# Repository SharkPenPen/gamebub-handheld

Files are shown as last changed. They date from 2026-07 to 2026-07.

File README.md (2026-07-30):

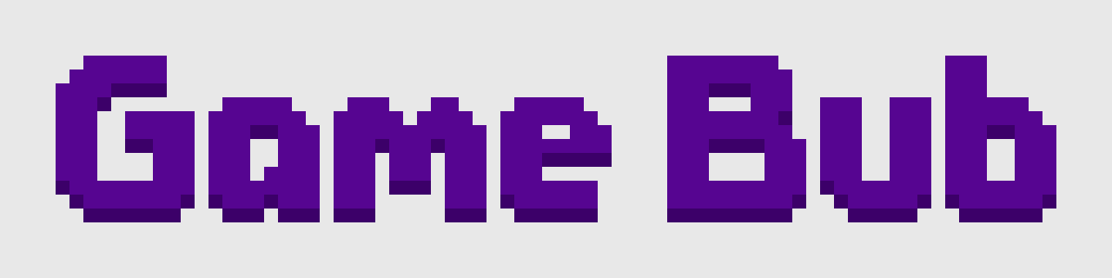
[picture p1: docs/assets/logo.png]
Game Bub logo

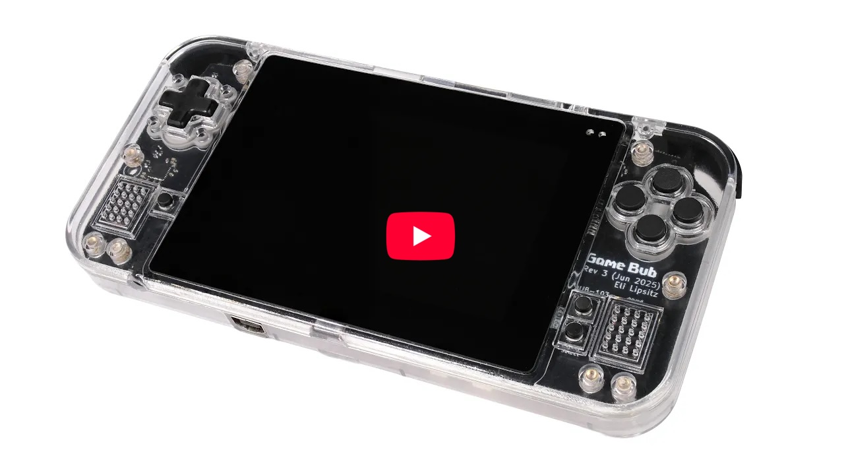
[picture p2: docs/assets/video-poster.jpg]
Game Bub trailer (https://www.youtube.com/watch?v=f16E5J6qljw)


**Game Bub** is an open-source FPGA retro emulation handheld, with support for Game Boy, Game Boy Color, and Game Boy Advance games.

Check out the [announcement blog post](https://eli.lipsitz.net/posts/introducing-gamebub/) for an in-depth look at the development process!

You can buy your own, prebuilt Game Bub from **[Crowd Supply](https://www.crowdsupply.com/second-bedroom/game-bub)**!

Want to chat about Game Bub? Feel free to [join the Discord](https://discord.gg/T5xrYpMfN7). 

## Features
* Play physical Game Boy / Color / Advance cartridges
* Load and play ROM files from a microSD card (with built-in support for rumble, clock, accelerometer, gyroscope)
* Multiplayer link cable functionality
* Custom, from-scratch Game Boy and Game Boy Advance FPGA cores with great game compatibility
* 14+ hour battery life 
* Video output to TV or monitor via custom dock
* Extensible hardware, designed for future improvements

## Building

Building a Game Bub handheld requires manufacturing PCBs, 3D printing the shell and buttons, and assembling components from a variety of sources. For information on manufacturing and assembling your own, see [docs/building.md](docs/building.md).

For other inquiries, contact me directly at eli@lipsitz.net.

## Architecture

For an in-depth description of the project architecture, see [docs/architecture.md](docs/architecture.md).

The Game Bub handheld consists of a Xilinx XC7A100T FPGA to do the main emulation and I/O, and an ESP32-S3 microcontroller to do auxiliary tasks (configuring the FPGA, rendering the UI, loading ROM files from a microSD card and sending it to the FPGA).

### Directory Structure

* `pcb`: PCB design files for Handheld, Dock, and others
* `3d`: STLs for 3D printed shell and buttons
* `fpga`: FPGA source code (HDL), written in [Chisel](https://github.com/chipsalliance/chisel)
* `firmware/handheld`: Microcontroller firmware

## License

Unless otherwise specified:
* FPGA source code (in `fpga/`) and firmware (in `firmware/`) is licensed under GPLv3 (`GPL-3.0-only`).
* 3D STL files (in `3d/`) is licensed under Creative Commons Attribution / Share-Alike 4.0 (`CC-BY-SA-4.0`)
* PCB schematic and layout files (in `pcb/`) are licensed under Creative Commons Attribution / Share-Alike 4.0 (`CC-BY-SA-4.0`)

At a high level, this means that you can copy, share, and modify the source code, as long as you provide proper attribution and share your source code / design files with the same license. However, this does not mean that you can use the "Game Bub" name and logo for your product without permission.

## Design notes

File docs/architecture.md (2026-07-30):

# Architecture

The physical architecture of the Game Bub handheld is summarized in the following block diagram.

See the [schematic](../pcb/handheld_rev2/handheld.pdf) for more information.

<p align="center">
     
</p>

## Power 

The device is split into three power domains:

* **Always on**: real-time clock, battery charger, battery gauge, and the power switch circuit.
    * `VBATT` (directly from the battery, 3.7V to 4.2V)
    * `VSYS_ALWAYS` (from the BQ24073 charger)
* **MCU**: Powers the MCU, its peripherals, and the display. Pressing the power switch powers on this power domain.
    * `VSYS` (~3.7V to 5.0V), from `VSYS_ALWAYS` through a load switch
    * `+3V3` (3.3V), generated by a TLV62585 buck converter from `VSYS`
* **FPGA**: Controlled by the `FPGA_ENABLE` signal from the MCU. Powers the FPGA and its peripherals. Also powers the DAC digital and analog core voltages (but the IO rails are powered as part of the MCU power domain).
    * `+1V0` (1.0V), generated by a TLV62585 buck converter from `VSYS`
    * `+5V0` (5.0V), generated by a TPS61022 boost converter from `VSYS`
    * `+1V8` (1.8V), generated by a TPS61022 boost converter from `VSYS`
    * `+3V3_FPGA` (3.3V), gated by a load switch from `+3V3`
    * `VGB` (3.3V or 5.0V), muxed from `+3V3_FPGA` or `+5V0` depending on whether there is a Game Boy (5V) or Game Boy Advance (3.3V) cartridge present. This muxing is controlled by the FPGA, and this is used to power the cartridge, link port, and the level shifters.

The FPGA requires careful power sequencing: `FPGA_ENABLE` enables `+1V0` and `+5V0`. `+1V8` is enabled once `+1V0` stabilizes, and `+3V3_FPGA` is enabled once that stabilizes.

## MCU and FPGA Responsibilities

The MCU is responsible for system control: it boots the device and manages the FPGA (power and configuration). It also renders the UI (sending completed frames over the FPGA for display).

The FPGA does all game emulation. It has direct access to the cartridge slot and link ports, and has dedicated memory (32 MiB of SDRAM, 512 KiB of SRAM) to assist with this. It produces audio and sends it to the DAC via I2S, and it has a high-bandwidth 18-bit parallel interface to the display. 

The FPGA also has 4 high-speed differential pairs routed out to the USB-C connector. This is used, with the custom dock in a vendor-specific alt mode, to output HDMI audio and video (directly from the FPGA). 

The high-speed QSPI link between the MCU and the FPGA (4 bit at 40 MHz, 20 MB/sec) is primarily used for control signals (telling the FPGA to play or pause), as well as rendering the UI. The FPGA drives the display, so the MCU has to send its UI through the FPGA.

Additionally, when using an emulated cartridge, the MCU sends the ROM file over to the FPGA to be stored in SDRAM, and periodically sends IMU updates (to emulate cartridges with accelerometers or gyroscopes).

Upon boot, the MCU loads the FPGA bitstream from the microSD card (4-bit SDIO), powers on the FPGA and configures it (using single SPI at 80 MHz). It initializes the display and other peripherals, and renders the initial UI.

## FPGA Structure

The top-level FPGA design is written in SystemVerilog and provides glue code to interface with the outside world, and instantiates the MMCM/PLLs, the HDMI module, and the main `HandheldTop` module, written in Chisel.

The `HandheldTop` module provides functionality common to both the Game Boy and GBA emulators. It instantiates the SPI receiver, MCU interrupt sender, SDRAM and SRAM controller, common configuration registers, the audio output (I2S), and the video output (DPI).

It instantiates the main emulator as a submodule ("inner module"), sending button input, receiving audio and video data (pixel by pixel, sample by sample, as it's generated), and arbitrating RAM access between the inner module and the MCU.

Video data from the inner module is placed into a triple-buffered framebuffer (backed by block RAM). The triple buffering is unfortunately essential because the display is rotated 90 degrees, so there would be diagonal tearing if entire frames were not buffered in memory. This also helps for HDMI output, which has to run at a constant 60 Hz frame rate, compared to the 59.73 Hz that the Game Boy and GBA run at. The UI from the MCU is received as 15-bit RGB (plus one alpha bit) and stored in a single buffer. The two are composited together as video is output.

### Clock Domains

* The "system" clock, which runs at the speed of the inner emulator (~8.39 MHz for Game Boy, ~16.78 MHz for GBA). Most of the logic runs in this clock domain
* The "av" (audio/video) clock, where the audio and video output is generated. This is 12.288 MHz when using the internal display, and 27.027 MHz when HDMI is enabled. HDMI uses a clock 5x faster as well for DDR TMDS encoding.
* The "sdram" clock, which runs at an integer multiple (e.g. 4x) of the "system" clock. This is used to communicate with the SDRAM module, and the integer multiple greatly simplifies clock domain crossing.
* The "spi" clock, which runs at 200 MHz. The SPI deserializer runs in this clock domain, allowing the 40 MHz SPI bus to be 5x oversampled. Read and write commands are deserialized and passed to the system clock domain via an asynchronous FIFO.

## MCU Structure

The MCU firmware is written with Rust, built on top of ESP-IDF with the [esp-idf-hal](https://github.com/esp-rs/esp-idf-hal) crate.

The UI is built with [Slint](https://github.com/slint-ui/slint). There's a single top-level Window, that holds the status bar and a swappable set of "Screen" components. Screens are each user-visible screen, such as the Main Menu, Rom Select, Settings, Tools, and Game screens.

Interrupts (from the FPGA, peripherals, or the button I/O expander) are handled in a dedicated interrupt thread, which sends events to a background "worker" thread. The UI runs on a dedicated "UI" thread, and the worker and UI threads communicate with each other through message passing.

When a game is being played, the Game screen is active. There are separate drivers for each type of bitstream (Game Boy or GBA), which handle loading the bootrom, loading and configuring the emulated cartridge, save files, and sending auxiliary data (e.g. IMU samples).

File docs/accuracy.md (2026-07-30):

# Accuracy

Neither the Game Boy [Color] or Game Boy Advance emulators have any major issues in any games I've tested.

## Game Boy / Game Boy Color

Test results WIP

## Game Boy Advance

Summary of test results (using [tests from here](https://emulation.gametechwiki.com/index.php/GBA_Tests)), as of commit [7d47149](/../../tree/7d47149a2f52bd7607accf401fc958f4a95d7e3a).

#### [mGBA test suite](https://github.com/mgba-emu/suite), commit 0293d27

| Test name  | Total | Passed |
| ---  | ----- | --- |
| Memory tests | 1552 | 1356 |
| I/O read tests | 130 | 43 |
| Timing tests | 2020 | 1510 |
| Timer count-up tests | 936 | 603 |
| Timer IRQ tests | 90 | 45 |
| Shifter tests | 140 | **140** |
| Carry tests | 93 | **93** |
| Multiply long tests | 72 | 52 |
| BIOS math tests | 615 | **615** |
| DMA tests | 1256 | 1060 |
| SIO register R/W tests | 90 | 32 |
| SIO timing tests | 8 | 0 |
| Misc. edge case tests | 10 | 8 |
| Video tests  | 7 | 5 |

#### AGS Aging Cartridge v10.0

| Test name  | Total | Passed |
| ---  | ----- | --- |
| Memory | 9 | **9** |
| LCD | 7 | **7** |
| Timer | 3 | **3** |
| DMA | 9 | **9** |
| COM | N/A | N/A |
| Key Input | 1 | **1** |
| Interrupt | 7 | **7** |

#### [jsmolka gba-tests](https://github.com/jsmolka/gba-tests), commit 49204e1

| Test name  | Result |
| ---  | --- |
| arm | **Pass** |
| bios | **Pass** |
| memory | **Pass** |
| nes | **Pass** |
| thumb | **Pass** |
| save: none | **Pass** |
| save: sram | **Pass** |
| save: flash64 | **Pass** |
| save: flash128 | **Pass** |

#### [alyosha gba-tests](https://github.com/alyosha-tas/gba-tests/), commit c8e15ff

| Test name  | Result |
| ---  | --- |
| DMA_ROM_Fixed | Fail test 46 |
| FIFO | Fail test 1 |
| FIFO_2 | Fail test 78 |
| Internal_Cycle_DMA_IRQ | Fail test 6 |
| Internal_Cycle_DMA_Mul | Fail test 37 |
| Halt_PC | Fail test 212 |
| Halt_PC_2 | Fail test 236 |
| Halt_PC_3 | Fail test 233 |
| Halt_PC_4 | Fail test 239 |
| IE | Fail test 1 |
| IF | Fail test 1 |
| IF_Timer | Fail test 1 |
| IRQ_Sub | **Pass** |
| LDM_ALU | Fail test 2 |
| LDM_ALU_Store | Fail test 6 |
| Sprite disable midline | not tested |
| Sprite disable on VRAM access | not tested |
| Sprite Last VRAM access | Fail test 159 |
| Sprite Last VRAM access free |  Fail test 121 |
| boundary_test_1 | Fail test 34 |
| branch_thumb | Fail test 42 |
| branch_thumb_2 | Fail test 26 |
| branch_thumb_3 | Fail test 34 |
| branch_thumb_4 | Fail test 29 |
| branch_thumb_arm | Fail test 55 |
| prefetcher_dma | Fail test 52 |
| prefetcher_full_arm | Fail test 1 |
| prefetcher_full_thumb | fail test 49 |
| PSR | Fail test 4 |
| Timer | Fail test 1 |
| Timer disable | Fail test 244 |
| Timer reset | Fail test 1 |

#### [NBA hw-test](https://github.com/nba-emu/hw-test), commit 4571fc5

| Test name  | Result |
| ---  | --- |
| Bus 128kb-boundary | Fail (stuck?) |
| DMA burst-into-tears | Fail 0/3 |
| DMA force-nseq-access | Fail 0/2 |
| DMA latch | Fail 0/3 |
| DMA start-delay | Fail 0/1 |
| IRQ irq-delay | **Pass** |
| PPU bgpd | Fail |
| PPU bgx | Fail |
| PPU dispcnt-latch | Fail |
| PPU greenswap | Fail |
| PPU sprite-hmosaic | Fail |
| PPU status-irq-dma | Fail (stuck?) |
| PPU vram-mirror | Fail 7/10 |
| Timer Reload | **Pass** |
| Timer Start-stop | **Pass** |
| Timer Halt-cnt | Fail 1/6 |

#### [Hades-Tests](https://github.com/hades-emu/Hades-Tests), commit 25ec4b4

| Test name  | Result |
| ---  | --- |
| bios-openbus | **Pass 12/12** |
| dma-latch | Fail 0/4 |
| dma-start-delay | Fail 0/8 |
| timer-basic | **Pass 10/10** |

#### [AGBEEG Aging v0.0.2](https://github.com/zaydlang/AGBEEG-Aging-Cartridge)

| Test name  | Result |
| ---  | --- |
| Cartridge | Fail 0/2 |
| CPU | Fail 2/3 |
| DMA | Fail 0/1 |

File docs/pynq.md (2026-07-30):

# Pynq-Z2 Documentation

The first version of this project was intended to be run on a Pynq-Z2 development board. Read the full writeup [here](https://eli.lipsitz.net/posts/fpga-gameboy-emulator/).

This document preserves the original instructions. **Please note, however, that the active branch of this repo no longer contains the Pynq/Zynq related code.** Check out the [`pynq-release` tag](https://github.com/elipsitz/gamebub/tree/pynq-release) for that code.

Currently, only the Pynq-Z2 is supported, although the core of the emulator should be able to be used on any FPGA with sufficient resources.

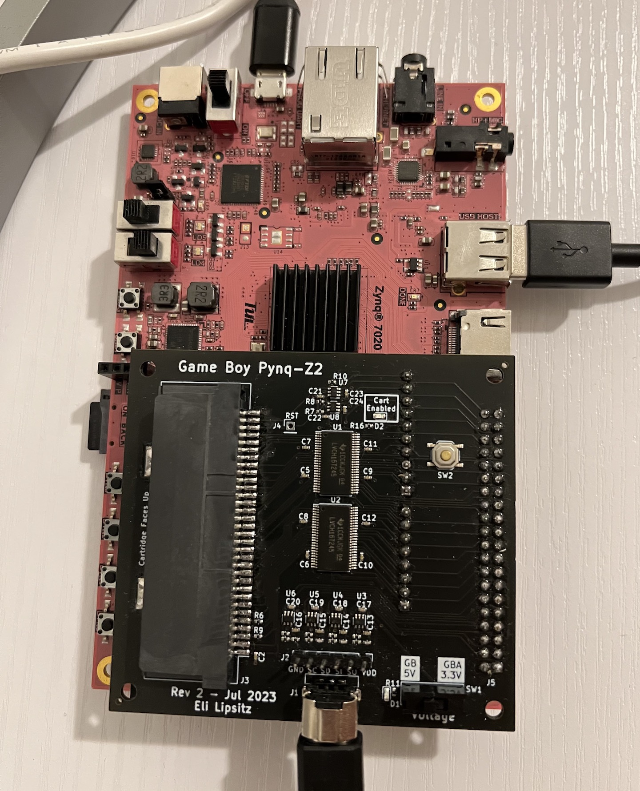
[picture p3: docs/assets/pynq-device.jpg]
 

## Building

A precompiled bitstream is available under Releases.

### Setup

#### Install Vivado

Currently this project uses Vivado 2020.2. The free edition is sufficient. Make sure to install with support for Zynq-7000 SoCs.

Install the [Pynq-Z2 Vivado board files](https://pynq.readthedocs.io/en/latest/overlay_design_methodology/board_settings.html).

Additionally, you should set up a shared IP cache to speed up synthesis of Xilinx IP:
1. Create the `~/vivado_ip_cache` directory (could be located somewhere else).
2. Create the file `~/.Xilinx/Vivado/Vivado_init.tcl`
3. In that file, add `set_param project.defaultIPCacheSetting /home/eli/vivado_ip_cache/` (substituting the absolute path to the IP cache directory).

#### Install other tools

You'll need to install JDK 8 or later, and [Scala Build Tool (`sbt`)](https://www.scala-sbt.org/download.html). Additionally, install [FuseSoC](https://github.com/olofk/fusesoc).

### Building the bitstream

From the top-level directory:

```
fusesoc --cores-root . run --build --target=pynq_z2 elipsitz:gameboy:gameboy
```

This will generate a `.bit` and `.hwh` file, which need to be accessible to the PS Python code.

## Running

### Setup

Install Pynq Linux on the Pynq-Z2, and install the pip packages listed in `python/requirements.txt`.

Transfer the `gameboy_ps` Python module (located in the `python` directory) to the Pynq-Z2.

Place the `gameboy.bit` and `gameboy.hwh` files from the build process in the `gameboy_ps/resources` directory.

### HDMI and Controller

Connect an HDMI cable from the "HDMI OUT" port on the Pynq-Z2 to a monitor or TV.

Attach an Xbox-compatible controller to the USB port of the Pynq-Z2.

### Running 

As root, run `python3 -m gameboy_ps <path to ROM directory>`, passing the path to the directory containing ROM files.

The program will load the bitstream to the PL. It takes a few seconds to load all of the Pynq libraries, but the main menu should soon show up on the display.

Warning: the audio output can be quite loud. Start at the lowest setting on the monitor/TV and increase it as needed.

## Building the cartridge adapter board

To play physical cartridges, you'll need to assemble the adapter board. KiCad board files can be found in the `pcb/pynq_adapter_rev2` directory. The schematic is pre-populated with LCSC part numbers for easy assembly at JLCPCB.

You'll need to add a few components yourself. These are all easy to solder:

* A 2x20 0.1mm female pin header (e.g. [this one](https://www.adafruit.com/product/2222)). These are used for Raspberry Pi HATs, so they're pretty easy to find.
* A SPDT slide switch such as the [EG1218](https://octopart.com/search?q=EG1218), or just a 1x3 strip of 0.1mm male pin header and a jumper.
* A GBA SP slot (such as [this one](https://handheldlegend.com/products/game-boy-cartridge-slot)). These can be found quite cheaply on eBay or Aliexpress as well. They're all pretty much the same.
* If desired, a GBA link port (e.g. [this one](https://handheldlegend.com/products/game-boy-advance-ext-link-port)). These can also be found easily from other sources.

The other parts are relatively small, so I don't recommend hand soldering the board. However, if you want to assemble the whole thing yourself, in addition to assorted resistors and capacitors, you'll also need:

* 6x [74LVC1T45DCK](https://octopart.com/search?q=74LVC1T45DCK) 1-bit level shifters.
* 2x [74LVCH16T245DGGR](https://octopart.com/search?q=74LVCH16T245DGGR) 16-bit level shifters. The non 'H' version should work as well, but the 'H' (bus hold) version is preferable.

## Appendix

### Getting Xbox controller to work on Pynq-Z2

This needs the `xpad` and `joydev` drivers. Pynq Linux isn't built with them. If you're running Pynq Linux with kernel `5.15.19-xilinx-v2022.1`, prebuilt kernel modules can be found in the [`pynq-release` release on GitHub](https://github.com/elipsitz/gamebub/releases/tag/pynq-release). Otherwise, to build loadable kernel modules from scratch:

On the Pynq-Z2, go to `/lib/modules/5.15.19-xilinx-v2022.1/build`.

Download the right version of [`xpad.c`](https://raw.githubusercontent.com/torvalds/linux/v5.15/drivers/input/joystick/xpad.c)
to `drivers/input/joystick/xpad.c`.

And do the same with [`joydev.c`](https://raw.githubusercontent.com/torvalds/linux/v5.15/drivers/input/joydev.c), to `drivers/input/joydev.c`.

The build commands in `/lib/modules` need to run with `sudo` due to permissions issues.

Do `sudo make menuconfig` and set:

* `Device Drivers --> Input device support --> Joystick interface` to `M` (for 'module')
* `Device Drivers --> Input device support --> Joysticks/gamepads --> X-box Gamepad support` to `M` (for 'module')

Save and exit.

Then build the modules:

```
sudo make scripts
sudo make distclean
sudo make prepare
sudo make modules_prepare

sudo make -C . M=drivers/input/ joydev.ko
sudo make -C . M=drivers/input/joystick xpad.ko
```

Install the modules so that they'll be loaded automatically on boot.
Copy the `.ko` files to `/usr/lib/modules/$(uname -r)/kernel/`, and append
to `/etc/modules`:

```
joydev
xpad
```

Alternatively, use `insmod <modules>.ko` to load them once.

Make sure the `xilinx` user is in the group `input`:
`sudo usermod -a -G input xilinx` (and re-login)

Install the Python library with `sudo pip3 install xbox360controller`

Create the device nodes if needed: https://docs.kernel.org/input/joydev/joystick.html#device-nodes

```
cd /dev
rm js*
mkdir input
mknod input/js0 c 13 0
mknod input/js1 c 13 1
mknod input/js2 c 13 2
mknod input/js3 c 13 3
ln -s input/js0 js0
ln -s input/js1 js1
ln -s input/js2 js2
ln -s input/js3 js3
```

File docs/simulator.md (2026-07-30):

# Simulator

Most development can be done in a Verilator simulation for easier debugging and to avoid having to build a new bitstream for every change.

Note that while the simulator is fast to compile, it's very slow to run. Only single thread CPU performance matters. On a MacBook Air M3, the GBA simulator runs at  ~5 fps (real time is 60fps), and the Game Boy Color simulator runs at ~40 fps.

The simulator has only been tested on macOS, but Linux should work perfectly fine as well.

## Setup

Ensure this repo is cloned with submodules checked out. If you already cloned the repo, run this:

```
git submodule update --init --recursive
```

SDL2 and [Verilator](https://www.veripool.org/verilator/) must be installed.
`fusesoc` and `sbt` (Scala Build Tool) must also be installed, see [building.md](./building.md).

## Building

To build the Game Boy simulator, run:

```
fusesoc --cores-root . run --target=sim --flag=module_gameboy elipsitz:gameboy:gameboy
```

The simulator will be built at `./build/elipsitz_gameboy_gameboy_1.0.0/sim-verilator/VSimGameboy`

Similarly, for the GBA, run:

```
fusesoc --cores-root . run --target=sim --flag=module_gba elipsitz:gameboy:gameboy
```

And find the simulator at `./build/elipsitz_gameboy_gameboy_1.0.0/sim-verilator/VSimGba`

Note that this command will end with an error ("ERROR: Failed to run ...") -- that's okay! FuseSoC doesn't know how to provide the correct command-line arguments to run the simulator.

## Running

For Game Boy Advance:

```
./build/elipsitz_gameboy_gameboy_1.0.0/sim-verilator/VSimGba --bios-path <path to bios.bin> <path to rom.gba>
```

Game Boy is the same, but with `VSimGameboy` (as mentioned above).

Optionally pass `--record path/to/output.mp4` to record all of the output of the simulator to play it back at full speed. Note that this produces an unusual lossless `mp4` file, and not all video players can play it. VLC works, though.

### Controls

Simulator controls:
* `escape`: quit the simulator
* `cmd+p`: pause or unpause
* `cmd+n`: pause and enter frame-by-frame mode. Keep pressing to advance one frame at a time.
* `cmd+r`: reset the simulator

Game controls:
* Arrow keys: D-pad up/down/left/right
* `z`: A button
* `x`: B button
* `a`: L shoulder button
* `s`: R shoulder button
* `right shift`: Select button
* `return`: Start button

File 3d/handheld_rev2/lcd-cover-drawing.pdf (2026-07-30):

R=3.20mm (x4)

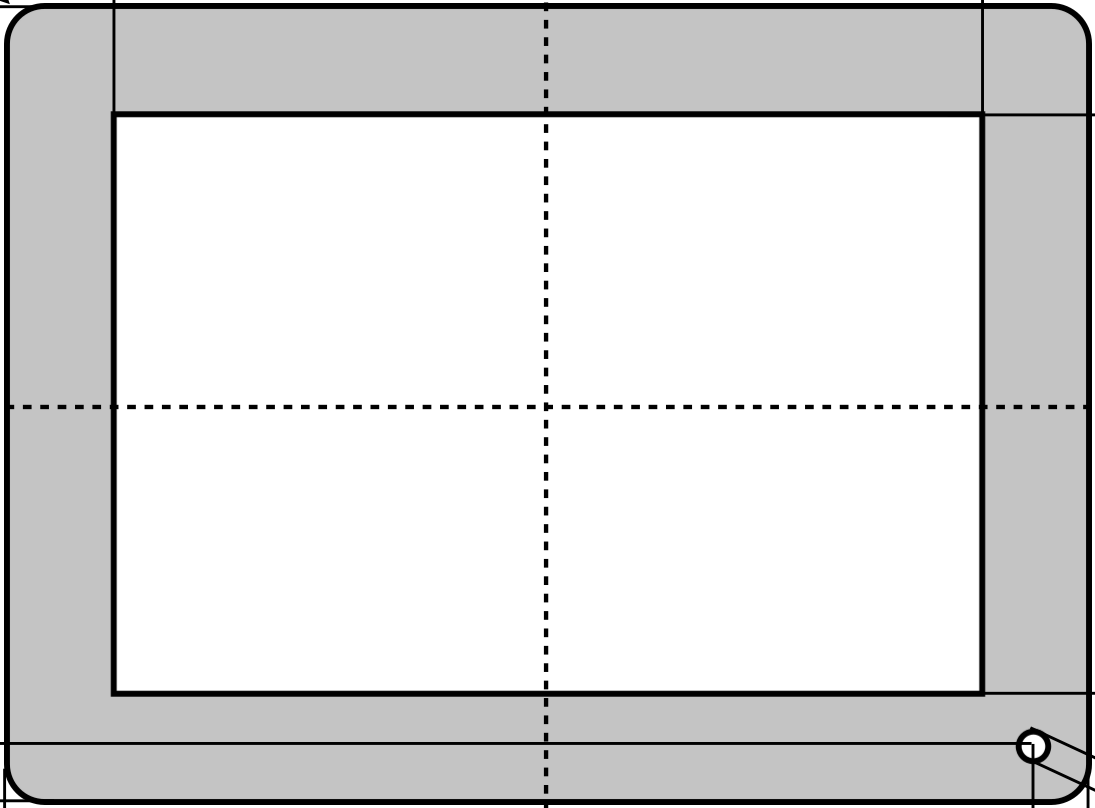
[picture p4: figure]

91.50mm

67.26mm
49.21mm

73.69mm

D=2.50mm

4.70mm

4.70mm

Shaded area: black silkscreen and adhesive backing

No adhesive in middle transparent rectangle

Material: 0.7mm tempered glass

Rounded corners (radius 3.20 mm, per drawing)

Note transparent circle in bottom right

# Front View

Transparent circle (no silkscreen)

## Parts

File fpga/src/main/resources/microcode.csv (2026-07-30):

Label | Comment | Encoding | PcNext | IME | RegRead1Sel | RegRead2Sel | RegWriteSel | RegOp | IncOp | IncReg | AluOp | AluSelA | AluSelB | AluFlagSet | MemEn | MemWr | MemAddrSel | MicroBranch | NextState
NOP |  | 00000000 | - | = | - | - | - | None | - | - | - | - | - | No | - | - | - | Fetch | -
_INVALID |  |  | Same | = | - | - | - | None | No | - | - | - | - | No | No | - | - | Jump | _INVALID
HALT |  | 01110110 | Same | = | - | - | - | None | No | - | - | - | - | No | No | - | - | Jump | HALT
STOP |  | 00010000 | IncOut | = | - | - | - | None | Inc | PC | - | - | - | No | No | - | - | Next | -
#STOP_loop |  |  | Same | = | - | - | - | None | No | - | - | - | - | No | No | - | - | Jump | #STOP_loop
LD r, (HL) |  | 01???110 | Same | = | - | - | Reg8Dest | WriteMem | No | HL | - | - | - | No | Yes | No | Incrementer | Jump | NOP
LD (HL), r |  | 01110??? | Same | = | - | Reg8Src | - | None | No | HL | CopyB | - | Reg2 | No | Yes | Yes | Incrementer | Jump | NOP
LD (HL),n |  | 00110110 | IncOut | = | - | - | W | WriteMem | Inc | PC | - | - | - | No | Yes | No | Incrementer | Next | -
 |  |  | Same | = | - | W | - | None | No | HL | CopyB | - | Reg2 | No | Yes | Yes | Incrementer | Jump | NOP
LD r,r |  | 01?????? | - | = | - | Reg8Src | Reg8Dest | WriteAlu | - | - | CopyB | - | Reg2 | No | - | - | - | Fetch | -
LD r,n |  | 00???110 | IncOut | = | - | - | Reg8Dest | WriteMem | Inc | PC | - | - | - | No | Yes | No | Incrementer | Jump | NOP
LD rr,nn |  | 00??0001 | IncOut | = | - | - | Reg16Lo | WriteMem | Inc | PC | - | - | - | No | Yes | No | Incrementer | Next | -
 |  |  | IncOut | = | - | - | Reg16Hi | WriteMem | Inc | PC | - | - | - | No | Yes | No | Incrementer | Jump | NOP
ldi (HL),A |  | 00100010 | Same | = | - | - | - | None | Inc | HL | CopyA | A | - | No | Yes | Yes | Incrementer | Jump | NOP
ldi A,(HL) |  | 00101010 | Same | = | - | - | A | WriteMem | Inc | HL | - | - | - | No | Yes | No | Incrementer | Jump | NOP
ldd (HL),A |  | 00110010 | Same | = | - | - | - | None | Dec | HL | CopyA | A | - | No | Yes | Yes | Incrementer | Jump | NOP
ldd A,(HL) |  | 00111010 | Same | = | - | - | A | WriteMem | Dec | HL | - | - | - | No | Yes | No | Incrementer | Jump | NOP
ALU A, n |  | 11???110 | IncOut | = | - | - | W | WriteMem | Inc | PC | - | - | - | No | Yes | No | Incrementer | Next | -
 |  |  | - | = | - | W | A | WriteAlu | - | - | InstAlu | A | Reg2 | All | - | - | - | Fetch | -
ALU A, (HL) |  | 10???110 | Same | = | - | - | W | WriteMem | No | HL | - | - | - | No | Yes | No | Incrementer | Next | -
 |  |  | - | = | - | W | A | WriteAlu | - | - | InstAlu | A | Reg2 | All | - | - | - | Fetch | -
ALU A, r |  | 10?????? | - | = | - | Reg8Src | A | WriteAlu | - | - | InstAlu | A | Reg2 | All | - | - | - | Fetch | -
JP nn | little endian address | 11000011 | IncOut | = | - | - | Z | WriteMem | Inc | PC | - | - | - | No | Yes | No | Incrementer | Next | -
 |  |  | IncOut | = | - | - | W | WriteMem | Inc | PC | - | - | - | No | Yes | No | Incrementer | Next | -
#PC=WZ |  |  | IncOut | = | - | - | - | None | No | WZ | - | - | - | No | No | - | - | Jump | NOP
JP HL |  | 11101001 | IncOut | = | - | - | - | None | IncNoWrite | HL | - | - | - | No | - | - | Incrementer | Fetch* | -
JP f,nn | Conditional | 110??010 | IncOut | = | - | - | Z | WriteMem | Inc | PC | - | - | - | No | Yes | No | Incrementer | Next | -
 |  |  | IncOut | = | - | - | W | WriteMem | Inc | PC | - | - | - | No | Yes | No | Incrementer | Cond | #PC=WZ
 |  |  | - | = | - | - | - | None | - | - | - | - | - | No | - | - | - | Fetch | -
LD (rr), A |  | 00??0010 | Same | = | - | - | - | None | No | Inst16 | CopyA | A | - | No | Yes | Yes | Incrementer | Jump | NOP
LD A, (rr) |  | 00??1010 | Same | = | - | - | A | WriteMem | No | Inst16 | - | - | - | No | Yes | No | Incrementer | Jump | NOP
LD (nn), A |  | 11101010 | IncOut | = | - | - | Z | WriteMem | Inc | PC | - | - | - | No | Yes | No | Incrementer | Next | -
 |  |  | IncOut | = | - | - | W | WriteMem | Inc | PC | - | - | - | No | Yes | No | Incrementer | Next | -
 |  |  | Same | = | - | - | - | None | No | WZ | CopyA | A | - | No | Yes | Yes | Incrementer | Jump | NOP
LD A, (nn) |  | 11111010 | IncOut | = | - | - | Z | WriteMem | Inc | PC | - | - | - | No | Yes | No | Incrementer | Next | -
 |  |  | IncOut | = | - | - | W | WriteMem | Inc | PC | - | - | - | No | Yes | No | Incrementer | Next | -
 |  |  | Same | = | - | - | A | WriteMem | No | WZ | - | - | - | No | Yes | No | Incrementer | Jump | NOP
LD (FF00 + n), A |  | 11100000 | IncOut | = | - | - | W | WriteMem | Inc | PC | - | - | - | No | Yes | No | Incrementer | Next | -
 |  |  | Same | = | - | W | - | None | No | - | CopyA | A | - | No | Yes | Yes | High | Jump | NOP
LD (FF00 + C), A |  | 11100010 | Same | = | - | C | - | None | No | - | CopyA | A | - | No | Yes | Yes | High | Jump | NOP
LD A, (FF00 + n) |  | 11110000 | IncOut | = | - | - | W | WriteMem | Inc | PC | - | - | - | No | Yes | No | Incrementer | Next | -
 |  |  | Same | = | - | W | A | WriteMem | No | - | - | - | - | No | Yes | No | High | Jump | NOP
LD A, (FF00 + C) |  | 11110010 | Same | = | - | C | A | WriteMem | No | - | - | - | - | No | Yes | No | High | Jump | NOP
INC rr |  | 00??0011 | Same | = | - | - | - | None | Inc | Inst16 | - | - | - | No | No | - | - | Jump | NOP
DEC rr |  | 00??1011 | Same | = | - | - | - | None | Dec | Inst16 | - | - | - | No | No | - | - | Jump | NOP
LD (nn), SP |  | 00001000 | IncOut | = | - | - | Z | WriteMem | Inc | PC | - | - | - | No | Yes | No | Incrementer | Next | -
 |  |  | IncOut | = | - | - | W | WriteMem | Inc | PC | - | - | - | No | Yes | No | Incrementer | Next | -
 |  |  | Same | = | - | SP_Lo | - | None | Inc | WZ | CopyB | - | Reg2 | No | Yes | Yes | Incrementer | Next | -
 |  |  | Same | = | - | SP_Hi | - | None | Inc | WZ | CopyB | - | Reg2 | No | Yes | Yes | Incrementer | Jump | NOP
LD SP, HL |  | 11111001 | Same | = | - | L | SP_Lo | WriteAlu | No | - | CopyB | - | Reg2 | No | No | - | - | Next | -
 |  |  | - | = | - | H | SP_Hi | WriteAlu | - | - | CopyB | - | Reg2 | No | - | - | - | Fetch | -
PUSH AF |  | 11110101 | Same | = | - | - | - | None | Dec | SP | - | - | - | No | No | No | - | Next | -
 |  |  | Same | = | - | A | - | None | Dec | SP | CopyB | - | Reg2 | No | Yes | Yes | Incrementer | Next | -
 |  |  | Same | = | - | F | - | None | No | SP | CopyB | - | Reg2 | No | Yes | Yes | Incrementer | Jump | NOP
POP AF |  | 11110001 | Same | = | - | - | F | WriteMem | Inc | SP | CopyB | - | Reg2 | No | Yes | No | Incrementer | Next | -
 |  |  | Same | = | - | - | A | WriteMem | Inc | SP | CopyB | - | Reg2 | No | Yes | No | Incrementer | Jump | NOP
PUSH rr |  | 11??0101 | Same | = | - | - | - | None | Dec | SP | - | - | - | No | No | No | - | Next | -
 |  |  | Same | = | - | Reg16Hi | - | None | Dec | SP | CopyB | - | Reg2 | No | Yes | Yes | Incrementer | Next | -
 |  |  | Same | = | - | Reg16Lo | - | None | No | SP | CopyB | - | Reg2 | No | Yes | Yes | Incrementer | Jump | NOP
POP rr |  | 11??0001 | Same | = | - | - | Reg16Lo | WriteMem | Inc | SP | - | - | - | No | Yes | No | Incrementer | Next | -
 |  |  | Same | = | - | - | Reg16Hi | WriteMem | Inc | SP | - | - | - | No | Yes | No | Incrementer | Jump | NOP
ADD HL,rr | 16-bit add | 00??1001 | Same | = | L | Reg16Lo | L | WriteAlu | No | - | AddLo | Reg1 | Reg2 | No | No | - | - | Next | -
 |  |  | - | = | H | Reg16Hi | H | WriteAlu | - | - | AddHi | Reg1 | Reg2 | -*** | - | - | - | Fetch | -
ADD SP,dd |  | 11101000 | IncOut | = | - | - | W | WriteMem | Inc | PC | - | - | - | No | Yes | No | Incrementer | Next | -
 |  |  | Same | = | SP_Lo | W | SP_Lo | WriteAlu | No | - | AddLo | Reg1 | Reg2 | 0*** | No | - | - | Next | -
 |  |  | Same | = | SP_Hi | W | SP_Hi | WriteAlu | No | - | AddHi | Reg1 | SignReg2 | No | No | - | - | Jump | NOP
ld HL,SP+dd |  | 11111000 | IncOut | = | - | - | W | WriteMem | Inc | PC | - | - | - | No | Yes | No | Incrementer | Next | -
 |  |  | Same | = | SP_Lo | W | L | WriteAlu | No | - | AddLo | Reg1 | Reg2 | 0*** | No | - | - | Next | -
 |  |  | - | = | SP_Hi | W | H | WriteAlu | - | - | AddHi | Reg1 | SignReg2 | No | - | - | - | Fetch | -
JR e |  | 00011000 | IncOut | = | - | - | W | WriteMem | Inc | PC | - | - | - | No | Yes | No | Incrementer | Next | -
#PC+=W |  |  | Same | = | PC_Lo | W | PC_Lo | WriteAlu | No | - | AddLo | Reg1 | Reg2 | No | No | - | - | Next | -
 | Mem MemAddr to be the new PC, and need to increment PC |  | IncOut | = | PC_Hi | W | PC_Hi | WriteAlu | IncNoWrite | PC_ALU | AddHi | Reg1 | SignReg2 | No | Yes | No | Incrementer | Fetch* | -
JR c,e | Conditional | 001??000 | IncOut | = | - | - | W | WriteMem | Inc | PC | - | - | - | No | Yes | No | Incrementer | Cond | #PC+=W
 |  |  | - | = | - | - | - | None | - | - | - | - | - | No | - | - | - | Fetch | -
CALL nn |  | 11001101 | IncOut | = | - | - | Z | WriteMem | Inc | PC | - | - | - | No | Yes | No | Incrementer | Next | -
 |  |  | IncOut | = | - | - | W | WriteMem | Inc | PC | - | - | - | No | Yes | No | Incrementer | Next | -
#CALL_end |  |  | Same | = | - | - | - | None | Dec | SP | - | - | - | No | No | No | - | Next | -
 |  |  | Same | = | - | PC_Hi | - | None | Dec | SP | CopyB | - | Reg2 | No | Yes | Yes | Incrementer | Next | -
 |  |  | Same | = | - | PC_Lo | - | None | No | SP | CopyB | - | Reg2 | No | Yes | Yes | Incrementer | Next | -
 |  |  | IncOut | = | - | - | - | None | IncNoWrite | WZ | - | - | - | No | - | - | Incrementer | Fetch* | -
CALL cc, nn | Conditional | 110??100 | IncOut | = | - | - | Z | WriteMem | Inc | PC | - | - | - | No | Yes | No | Incrementer | Next | -
 |  |  | IncOut | = | - | - | W | WriteMem | Inc | PC | - | - | - | No | Yes | No | Incrementer | Cond | #CALL_end
 |  |  | - | = | - | - | - | None | - | - | - | - | - | No | - | - | - | Fetch | -
RET |  | 11001001 | Same | = | - | - | PC_Lo | WriteMem | Inc | SP | - | - | - | No | Yes | No | Incrementer | Next | -
 |  |  | Same | = | - | - | PC_Hi | WriteMem | Inc | SP | - | - | - | No | Yes | No | Incrementer | Next | -
 | Extra NOP |  | Same | = | - | - | - | None | No | - | - | - | - | No | No | - | - | Jump | NOP
RET cc | Conditional | 110??000 | Same | = | - | - | - | None | No | - | - | - | - | No | No | - | - | Cond | RET
 |  |  | - | = | - | - | - | None | - | - | - | - | - | No | - | - | - | Fetch | -
RETI | RET + enable interrupts | 11011001 | Same | = | - | - | PC_Lo | WriteMem | Inc | SP | - | - | - | No | Yes | No | Incrementer | Next | -
 |  |  | Same | = | - | - | PC_Hi | WriteMem | Inc | SP | - | - | - | No | Yes | No | Incrementer | Next | -
 | Extra NOP |  | Same | En | - | - | - | None | No | - | - | - | - | No | No | - | - | Jump | NOP
INC (HL) |  | 00110100 | Same | = | - | - | W | WriteMem | No | HL | - | - | - | No | Yes | No | Incrementer | Next | -
 |  |  | Same | = | - | W | - | None | No | HL | IncB | - | Reg2 | All | Yes | Yes | Incrementer | Jump | NOP
INC r |  | 00???100 | - | = | - | Reg8Dest | Reg8Dest | WriteAlu | - | - | IncB | - | Reg2 | All | - | - | - | Fetch | -
DEC (HL) |  | 00110101 | Same | = | - | - | W | WriteMem | No | HL | - | - | - | No | Yes | No | Incrementer | Next | -
 |  |  | Same | = | - | W | - | None | No | HL | DecB | - | Reg2 | All | Yes | Yes | Incrementer | Jump | NOP
DEC r |  | 00???101 | - | = | - | Reg8Dest | Reg8Dest | WriteAlu | - | - | DecB | - | Reg2 | All | - | - | - | Fetch | -
ALU unary | accumulator/flag ops | 00???111 | - | = | - | - | A | WriteAlu | - | - | InstAcc | A | Reg2 | All | - | - | - | Fetch | -
CB_PREFIX | CB prefix | 11001011 | IncOut | = | - | - | - | None | Inc | PC | - | - | - | No | Yes | No | Incrementer | DispatchCB | -
CB_ALU (HL) | CB shift / rotates | CB_00???110 | Same | = | - | - | W | WriteMem | No | HL | - | - | - | No | Yes | No | Incrementer | Next | -
 |  |  | Same | = | - | W | - | None | No | HL | InstCB | - | Reg2 | All | Yes | Yes | Incrementer | Jump | NOP
CB_ALU r | CB shift / rotates | CB_00?????? | - | = | - | Reg8Src | Reg8Src | WriteAlu | - | - | InstCB | - | Reg2 | All | - | - | - | Fetch | -
BIT (HL) | No (HL) writeback | CB_01???110 | Same | = | - | - | W | WriteMem | No | HL | - | - | - | No | Yes | No | Incrementer | Next | -
 |  |  | - | = | - | W | - | None | - | - | InstBit | - | Reg2 | All | - | - | - | Fetch | -
CB_BIT (HL) |  | CB_?????110 | Same | = | - | - | W | WriteMem | No | HL | - | - | - | No | Yes | No | Incrementer | Next | -
 |  |  | Same | = | - | W | - | None | No | HL | InstBit | - | Reg2 | All | Yes | Yes | Incrementer | Jump | NOP
CB_BIT r |  | CB_???????? | - | = | - | Reg8Src | Reg8Src | WriteAlu | - | - | InstBit | - | Reg2 | All | - | - | - | Fetch | -
EI | Enable interrupts | 11111011 | - | En | - | - | - | None | - | - | - | - | - | No | - | - | - | Fetch | -
DI | Disable interrupts | 11110011 | - | Dis | - | - | - | None | - | - | - | - | - | No | - | - | - | Fetch | -
RST vec |  | 11???111 | Same | = | - | - | - | None | Dec | SP | - | - | - | No | No | No | - | Next | -
 |  |  | Same | = | - | PC_Hi | - | None | Dec | SP | CopyB | - | Reg2 | No | Yes | Yes | Incrementer | Next | -
 |  |  | RstAddr | = | - | PC_Lo | - | None | No | SP | CopyB | - | Reg2 | No | Yes | Yes | Incrementer | Jump | NOP
#Interrupt | decrement PC |  | IncOut | Dis | - | - | - | None | Dec | PC | - | - | - | No | No | No | - | Next | -
#Interrupt_keepPC | decrement SP |  | Same | Dis | - | - | - | None | Dec | SP | - | - | - | No | No | No | - | Next | -
 | push PC hi |  | Same | = | - | PC_Hi | - | None | Dec | SP | CopyB | - | Reg2 | No | Yes | Yes | Incrementer | Next | -
 | push PC, jump |  | Interrupt | = | - | PC_Lo | - | None | No | SP | CopyB | - | Reg2 | No | Yes | Yes | Incrementer | Jump | NOP

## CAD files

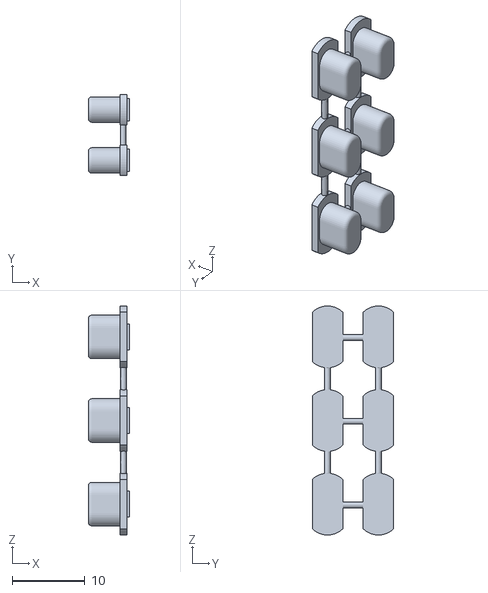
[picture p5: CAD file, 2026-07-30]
3d/handheld_rev2/SideButtonArray.stl
5.70 x 11.2 x 31.5

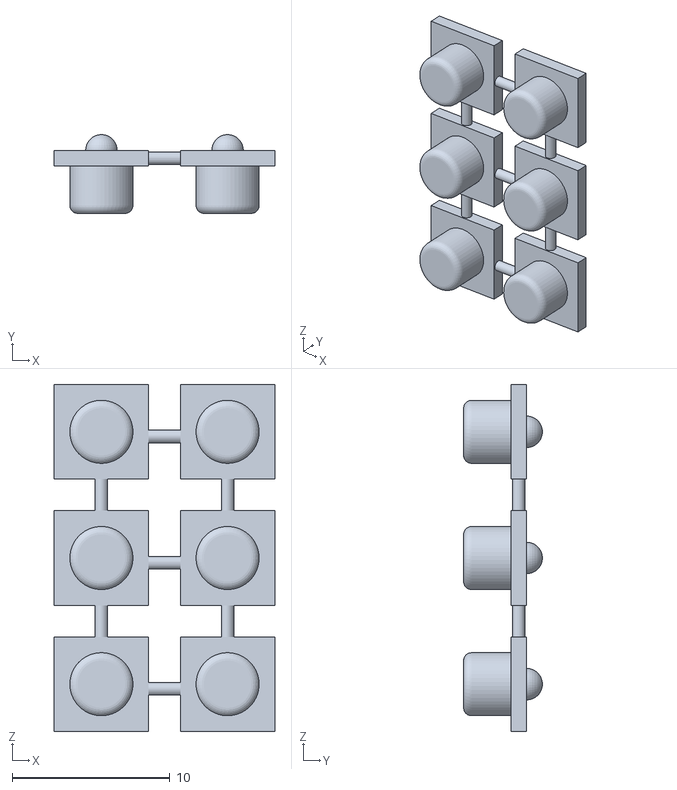
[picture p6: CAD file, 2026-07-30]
3d/handheld_rev2/ExtButtonArray.stl
14.0 x 5.00 x 22.0

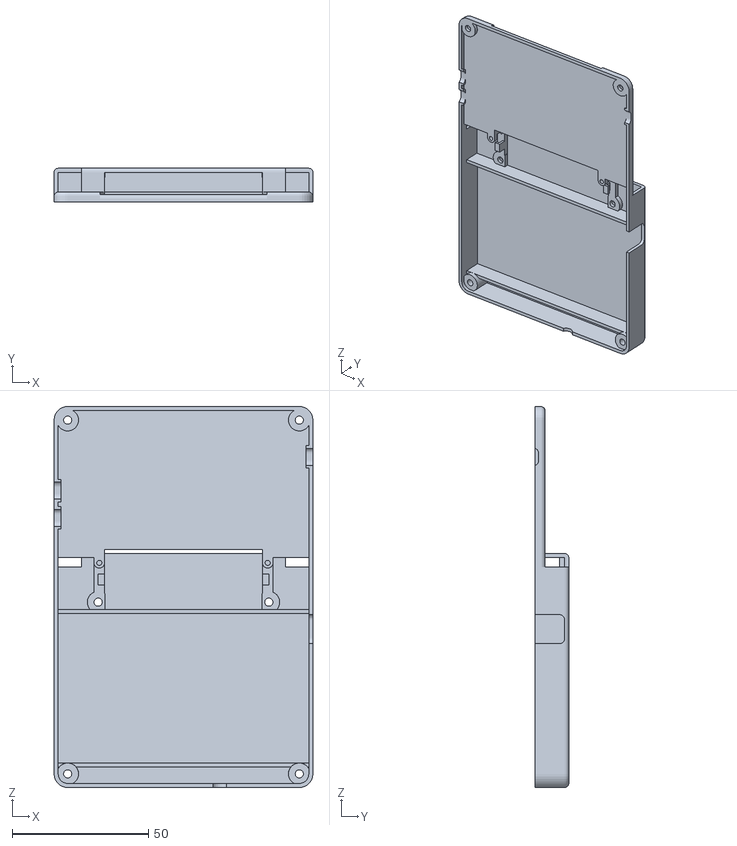
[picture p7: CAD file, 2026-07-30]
3d/handheld_rev2/Rear.stl
95.1 x 12.4 x 140.0

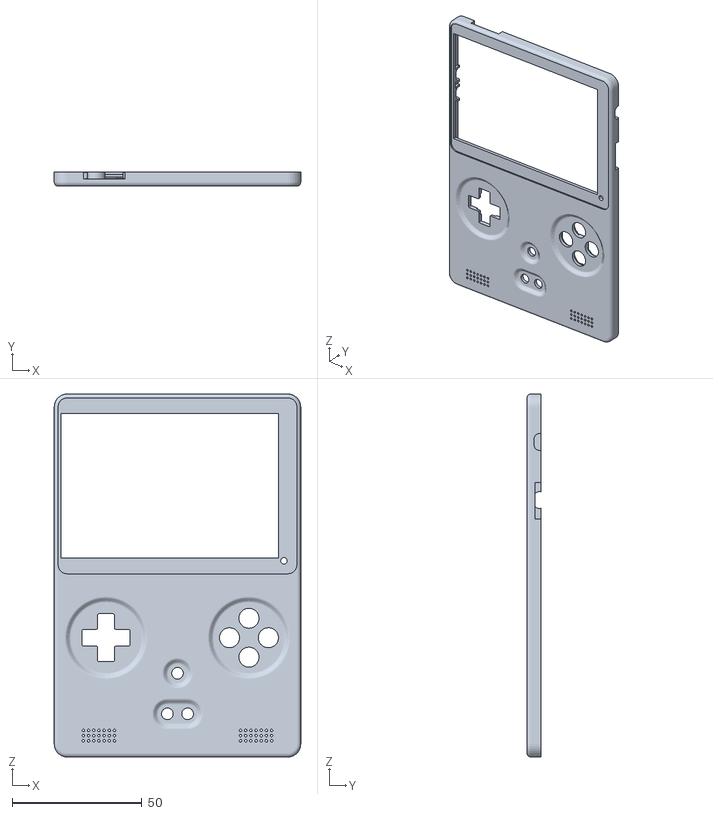
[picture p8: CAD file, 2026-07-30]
3d/handheld_rev2/Front.stl
95.1 x 5.50 x 140.0

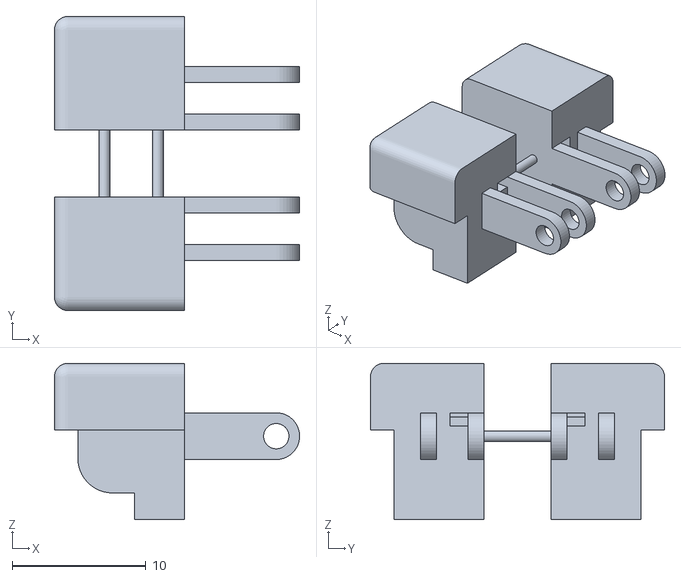
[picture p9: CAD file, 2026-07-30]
3d/handheld_rev2/ShoulderButtonArray.stl
18.3 x 22.0 x 11.7

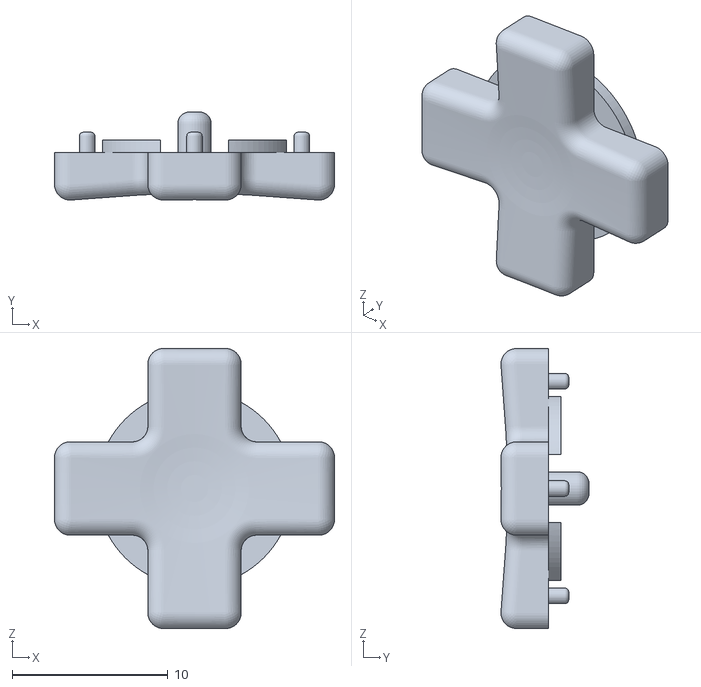
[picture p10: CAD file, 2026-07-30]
3d/handheld_rev2/DpadButton.stl
18.0 x 5.66 x 18.0

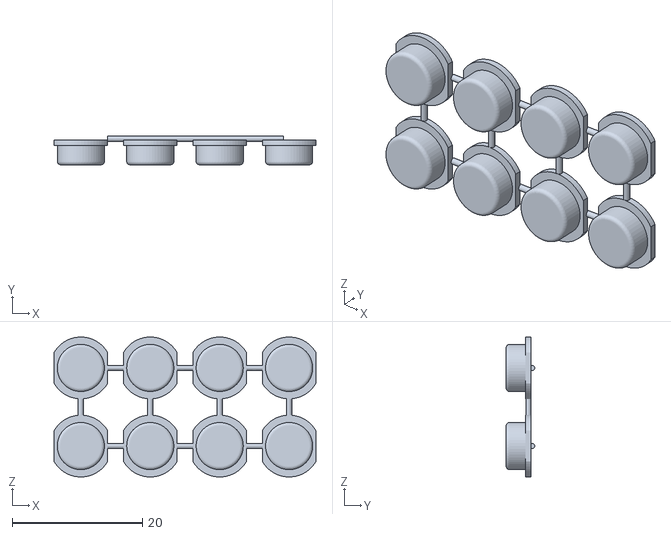
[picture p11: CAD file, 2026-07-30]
3d/handheld_rev2/FaceButtonArray.stl
40.3 x 4.40 x 21.5

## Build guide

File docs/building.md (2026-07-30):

# Building

Building a Game Bub unit is a fairly involved process:

1. Manufacturing the PCB
2. Assembling the PCB
3. Printing the shell (and buttons)
4. Assembling the whole device
5. Building the FPGA bitstreams
6. Setting up the microSD card
7. Flashing the MCU firmware

## 1. Manufacturing the PCB

Fab the PCB (in `/pcb/handheld_rev2`) using your manufacturer of choice. The board was initially designed to be fabricated and assembled by JLCPCB.

The board has 6 layers, and rectangular dimensions of 90.1 mm by 135 mm. Due to the fine pitch (0.8mm) BGA FPGA package, the smallest vias are 0.4/0.25mm, with a minimum track width of 0.1mm. The board must have an ENIG finish, as HASL is too uneven for fine-pitch BGA components. 

The board should have a thickness of 1.6mm -- this isn't essential, but the enclosure was designed for this thickness. Only the JLCPCB default 6-layer `JLC06161H-3313` stackup has been tested, but other stackups are likely to work too.

## 2. Assembling the PCB

The board is primarily one-sided, and the vast majority of the components can be machine assembled. The board design files have LCSC component IDs (for easy JLCPCB assembly).

The remaining components are specialty or otherwise difficult to machine assemble:

Front:
* 3.5mm headphone jack: Same Sky SJ-43614-SMT-TR
* Rumble motor: generic 10mm diameter rumble motor
* Optional PMOD connector: 6-pin female 0.1 inch right angle SMD header

Rear:
* Generic GBA cartridge slot
* Generic GBA link port
* Cartridge slot shape detector: JJOV0UL650NONPRBK
* Battery connector: S2B-PH-SM4-TB (or generic 2-pin SMD JST-PH receptacle)
* Shoulder (L and R) buttons: C&K PTS645VN13SMTR92LFS (x2)

Solder each of these components (see the PCB design files if needed).

## 3. Printing the shell

The shell consists of two pieces: the front and rear. Both have a wall thickness of 1.5mm, with some small features of 1.0mm or 0.8mm.

FDM (filament) printing is almost certainly not suitable: this should be printed with a high-precision technology such as SLA (photosensitive resin).

Additionally, all of the buttons are custom and need to be printed as well:
* 4x Large front buttons (A, B, X, and Y)
* D-pad
* 3x Small front buttons (Start, Select, Home)
* 3x Side buttons

## 4. Assembling the whole device

### Parts needed
* ER-TFT035IPS-6 LCD module
* LCD Cover glass (tempered glass or transparent acrylic)
* 2x Speakers (CMS-160903-18S-X8)
* 9x M2.5x4mm heat-set inserts
* CA glue to glue the inserts
* A set of Nintendo DSi button membranes (ABXY and D-pad)
* M2.5 screws:
    * 5x 5mm (three PCB screws, 2 top screws)
    * 4x 14mm (middle and bottom screws)
* A set of torsion springs (1x left, 1x right):
    * Required: >1.5mm interior diameter
    * Suggested: 0.3mm wire diameter, 5 turns, 135 degree angle
* 2x 1.5mm diameter dowel pins, 8mm to 9mm long.
* 755068 size flat Lipo battery with a JST-PH connector (verify polarity)

### Steps
Before assembling, consider testing that the PCB works properly.

1. Attach the LCD cover glass to the front shell with adhesive glue or tape
2. Place the front shell face down on a surface
3. Carefully align and press the LCD module onto the cover glass (ensure flex is facing the correct direction)
4. Glue all 9 heat-set inserts into place, and let the glue harden
5. Insert the speakers into the shell
6. Place the face buttons into the shell, followed by the D-pad and ABXY membranes
7. Open the LCD flex connector on the PCB
8. Carefully set the PCB face down onto the shell, putting the LCD module flex into place on the PCB connector, and close it.
9. Ensure the PCB is aligned well onto the front shell
8. Use the 5mm screws to attach the PCB to the front shell (triangle of screw holes in the middle, towards the bottom half of the PCB). Tighten carefully.
9. Insert the three side buttons into the front shell.
10. Attach the battery to the rear shell with adhesive
11. Assemble the shoulder buttons: align each shoulder button with the rear shell. Place the correct spring in line (inserting one end of the spring into the button), and then insert a dowel pin to hold the assembly together. Hook the other end of the spring into the hook in the rear shell.
12. Plug the battery into the battery connector on the PCB
13. Place the rear shell onto the front shell
14. Use 6 screws (5mm on top, 14mm on the middle and bottom) to close up the shell

## 5. Building the FPGA bitstreams

1. Install Xilinx Vivado 2023.2 with support for Artix-7 devices
2. Install JDK 8 or later, and [Scala Build Tool (`sbt`)](https://www.scala-sbt.org/download.html)
3. Install [FuseSoC](https://github.com/olofk/fusesoc).

From the `/fpga` directory, use FuseSoC to build the bitstreams:

```sh
$ fusesoc --cores-root . --work-root=build/boot --target=handheld_rev2 --flag=boot elipsitz:gameboy:gameboy
$ fusesoc --cores-root . --work-root=build/gameboy --target=handheld_rev2 --flag=gameboy elipsitz:gameboy:gameboy
$ fusesoc --cores-root . --work-root=build/gba --target=handheld_rev2 --flag=gba elipsitz:gameboy:gameboy
```

Save the generated `*.bit` files.

## 6. Setting up the microSD card

Format a good quality microSD card with FAT32, then create the following directory structure:

```
system/
  boot.bit.gz
  gameboy.bit.gz
  gameboy.bios-dmg.bin
  gameboy.bios-cgb.bin
  gba.bit.gz
  gba.bios.bin
roms/
```

* `boot.bit.gz` should be a gzip'd copy of the `boot` bitstream built previously.
* `gameboy.bit.gz` should be a gzip'd copy of the `gameboy` bitstream.
* `gba.bit.gz` should be a gzip'd copy of the `gba` bitstream.
* `gameboy.bios-dmg.bin` and `gameboy.bios-cgb.bin` should be the bootrom files for the original Game Boy and Game Boy Color, or open-source alternatives (e.g. from [SameBoy](https://github.com/LIJI32/SameBoy)).
* `gba.bios.bin` should be the Game Boy Advance bootrom. Either the official one, extracted from a GBA (best compatibility), or a free alternative ([e.g. this one](https://github.com/Cult-of-GBA/BIOS)).
* `roms/` should be a directory containing ROM files (if desired), with `.gb`, `.gbc`, and `.gba` extensions. This directory can be further organized into more directories.

## 7. Flashing the MCU firmware

### Setup

1. Install Rust for ESP32 by [following these instructions (Xtensa targets)](https://docs.esp-rs.org/book/installation/index.html)
2. Install [espflash](https://github.com/esp-rs/espflash)

### Building and installing

Connect the device to your computer with a USB-C cable. Hold the "Home" button (in the center) while turning the device on (by pressing the power button in the top right).

From `/firmware/handheld`, run the following command to build and flash the firmware:

```sh
$ cargo run --release --features=rev2
```

Then, flash the device-specific "factory" data:

```sh
$ python3 flash_nvs.py --serial serialno --revision 2
```

The device should automatically reboot into the main menu.

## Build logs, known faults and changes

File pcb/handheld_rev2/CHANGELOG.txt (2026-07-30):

Done
* Switch USB-C connector to one with 24p
* Remove HDMI port and related circuitry
* Power DAC IOVDD with +3V3 instead of 3V3_FPGA
* Change pull-up resistors on link port lines to ~47k to 100k. Move the 100K pull-up to the other side of the 330R current limiter
* Add 3V3_FPGA test point
* Add n-FET gated by 3V3_FPGA between IRQ line and FPGA IRQ to pull it down
* Switch to ESP32-S3-MINI
* Separate SPI bus for display (3 wire -- so add clock and data line)
* Connect TE signal from LCD (could replace SRAM nCS)
* Output HDMI signals over USB-C SS signals
* Connect a (or both?) USB-C SBU to the FPGA (with a series resistor)
* Add a rumble "brake" circuit? with another signal to the FPGA
* Update SRAM LCSC ID to comparable part
* Investigate noise in headphones and speakers -- try the low-noise LDO for analog 3V3
* Reserve space for screw holes (new positioning)
* Allow for larger, 5mm (!) rounded radius
* Footprint for 24p USB-C
* Switch battery connector to SMD (or maybe dual footprint)
* [not possible] If possible, move cartridge shape detector to the left side (when looking at rear)
* Change 0603 resistors to 0402 where possible? Including 0 ohm shunts
* Switch headphone jack (PJ-342?)
* Use DSi XL button spacing and silicone pads (and keep-out area)
* Use Kicad 8 pin 1 designators on footprints
* Move link port to the bottom, on the rear
* Move side buttons a bit further from L/R buttons
* Move the home button away? Closer to the top, middle?
* Remove unneeded hole from cartridge switch footprint
* Support speaker with spring contact -- leave space for it
* Move side buttons further in (with PCB cutout around)
* Make shoulder buttons SMD 
* Ensure all ports hang off the right amount
* If needed, change some of the test points (e.g. I2S) to smaller surface-only
* Investigate SMD vibration motor? Reserve space to solder it in place on board and glue it down?
* Minimize BOM: Look at resistors and capacitors that are used just once -- see if they can be changed to something else
* Add silkscreen rectangle to write identifying info
* New Gamebub logo
* Print test point silkscreen (for through hole) on rear

TODO Schematic
* Try to connect FPGA clock to different IO bank -- bank 14 or bank 15

TODO Layout
* Add silkscreen indicators around screw holes

Not doing:
* Make FPGA JTAG easier to access (e.g. when there's a case on? closer to battery?)
* Consider swapping I/O expander to QFN 4x4mm package if needed
* Move spi test points further from LCD plug (removed them)
* Use Kicad 8 net-from-value for power rails
* Add some resettable fuses (PTC): one each where 3.3V and 5V connects to VGB (and can remove the extra transistors). 
* Add resettable fuse at rumble motor
* Not needed: Tie SRAM nCE low, disconnect from FPGA (if needed)

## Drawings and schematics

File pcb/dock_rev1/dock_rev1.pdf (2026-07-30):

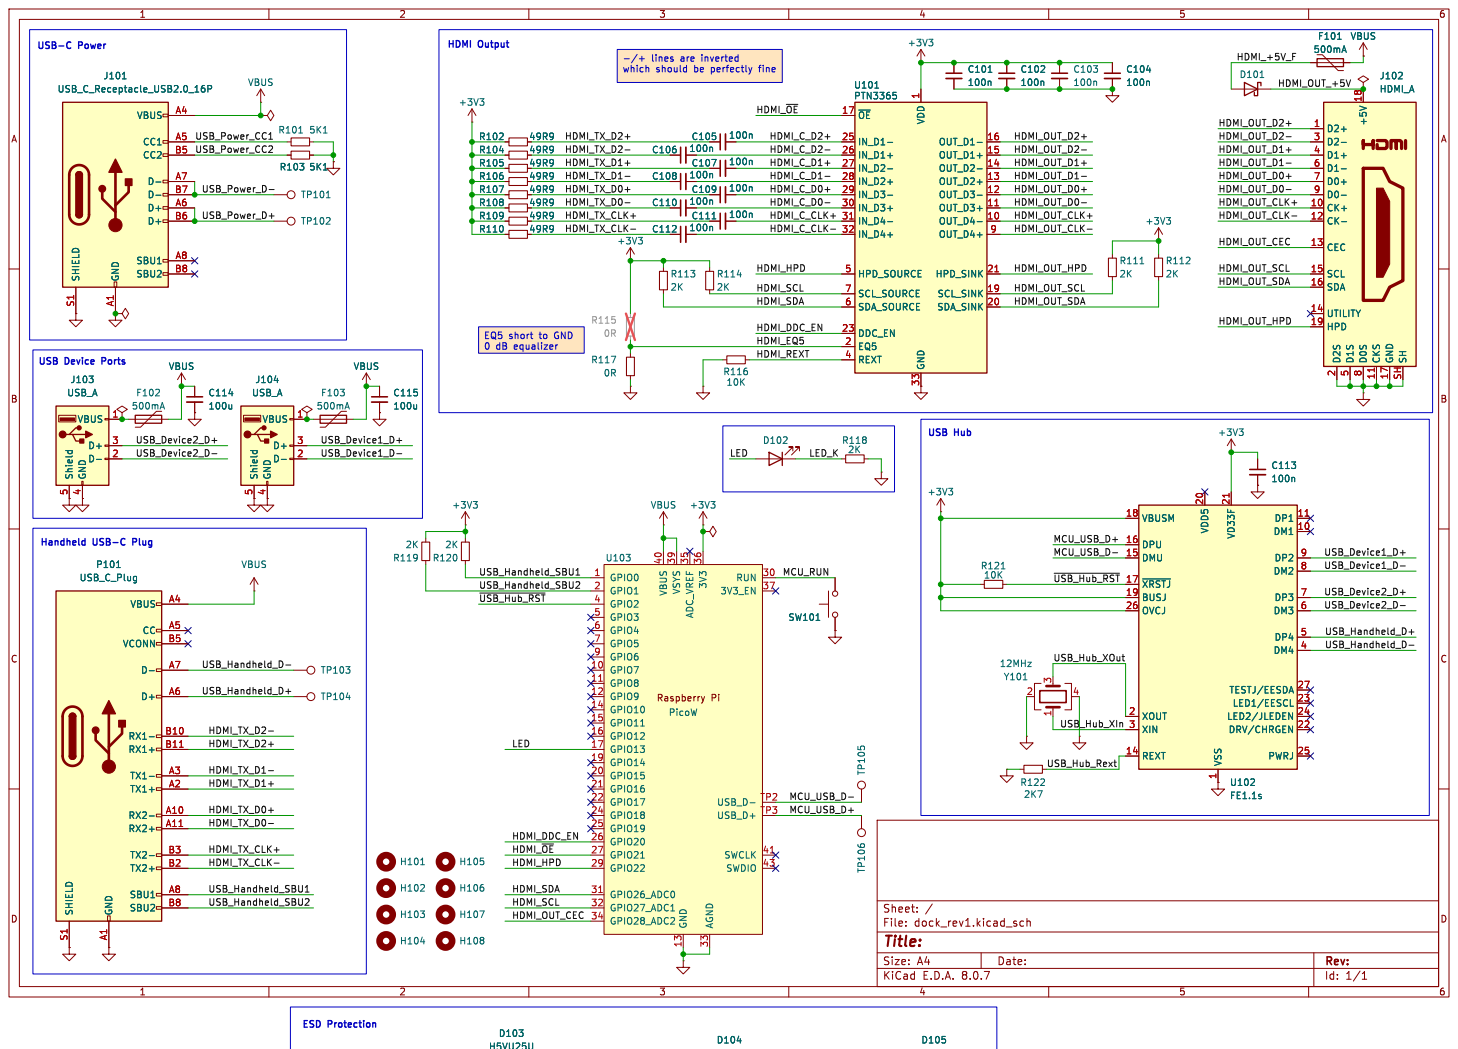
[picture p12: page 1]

HDMI Output USB Device Ports

1 DM1 10 DP1 11 REXT 14 DMU 15 DPU 16 ~{XRSTJ} 17 VBUSM 18 BUSJ 19 XOUT 2 VDD5 20 VD33F 21 DRV/CHRGEN 22

Id: 1/1 Title: File: dock_rev1.kicad_sch Sheet: /

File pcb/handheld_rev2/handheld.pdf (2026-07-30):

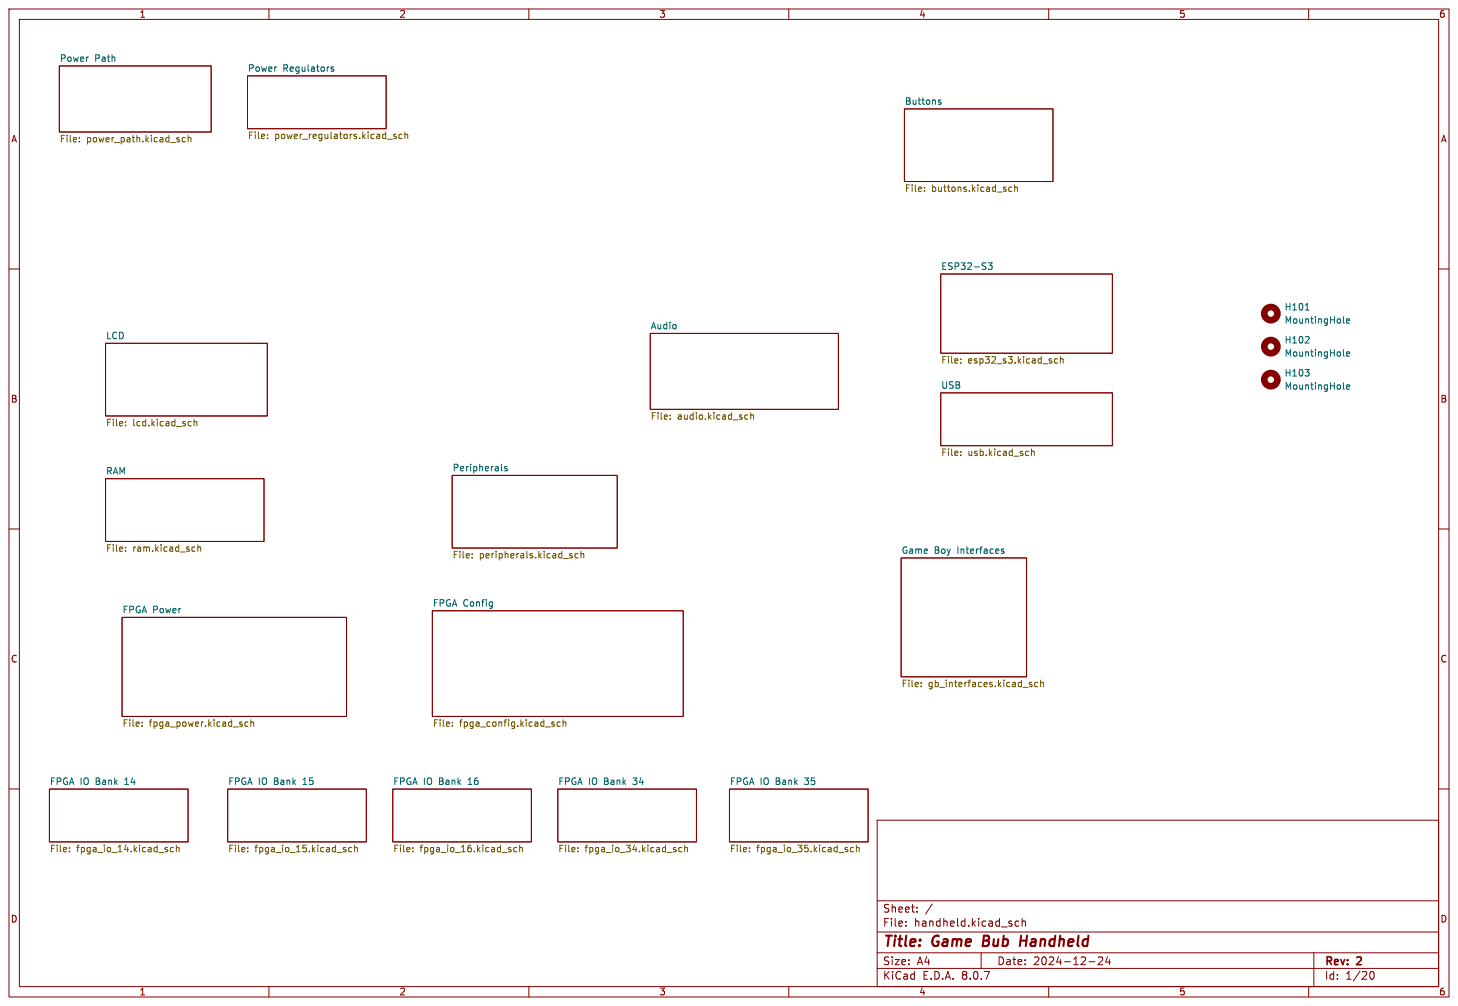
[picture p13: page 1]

File: lcd.kicad_sch Power Path File: power_path.kicad_sch RAM

File: usb.kicad_sch Power Regulators File: power_regulators.kicad_sch

File: handheld.kicad_sch Sheet: /
Id: 1/20 Title: Game Bub Handheld

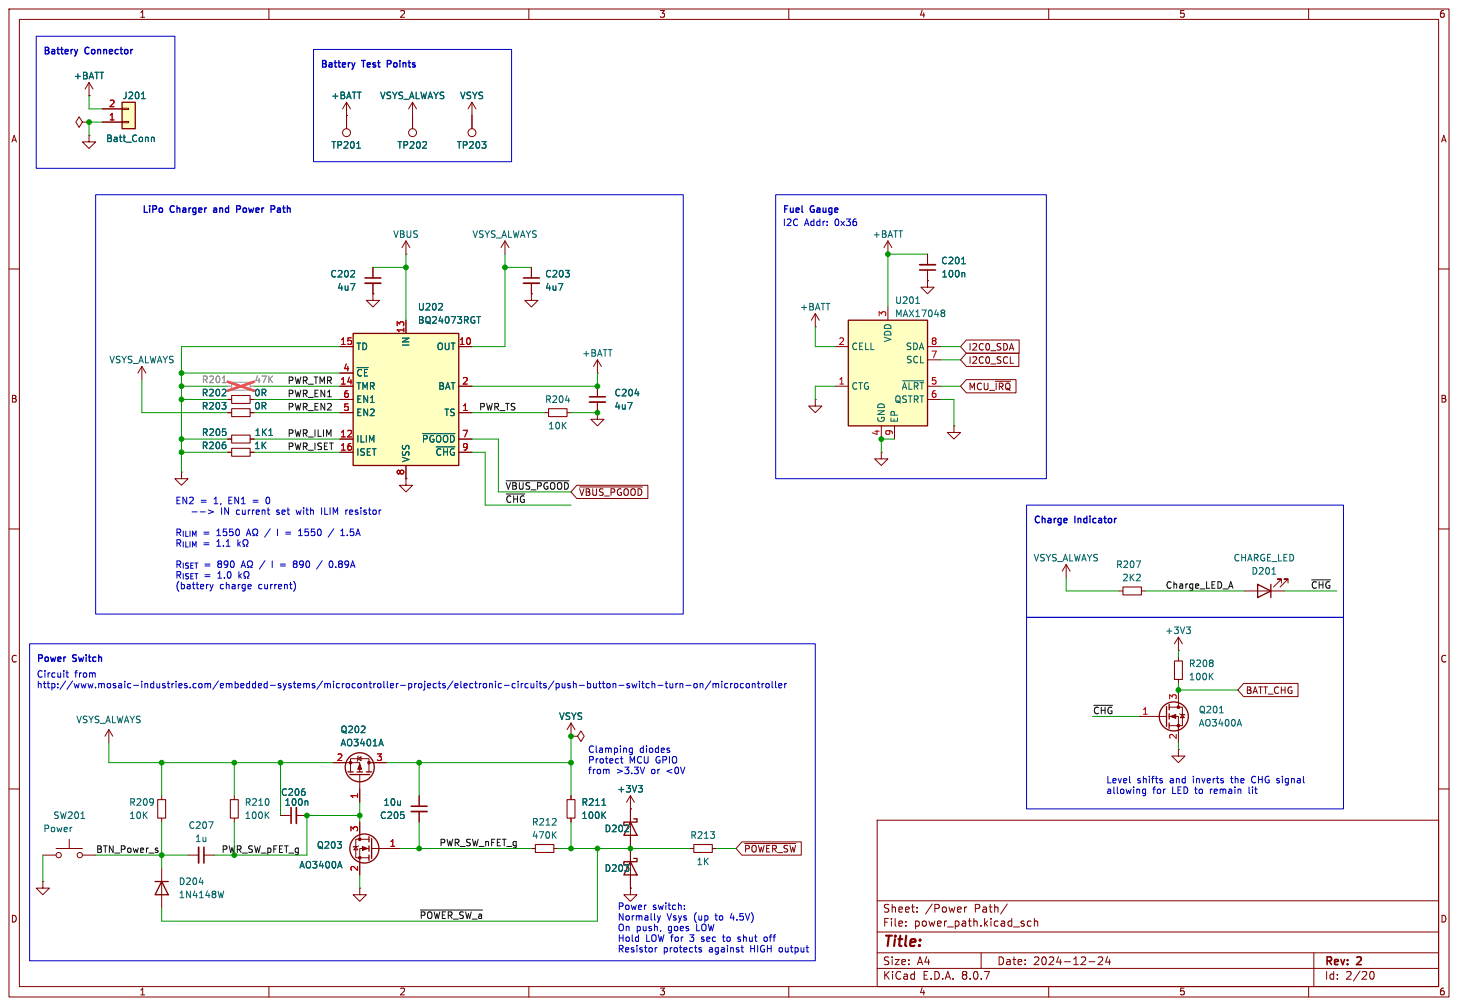
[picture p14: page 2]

4 QSTRT 6 SCL 7 SDA 8 EP

R_{ISET} = 890 þÿA©/ I = 890 / 0.89A R_{ISET} = 1.0 þÿk©

http://www.mosaic-industries.com/embedded-systems/microcontroller-projects/electronic-circuits/push-button-switch-turn-on/microcontroller

Level shifts and inverts the CHG signal

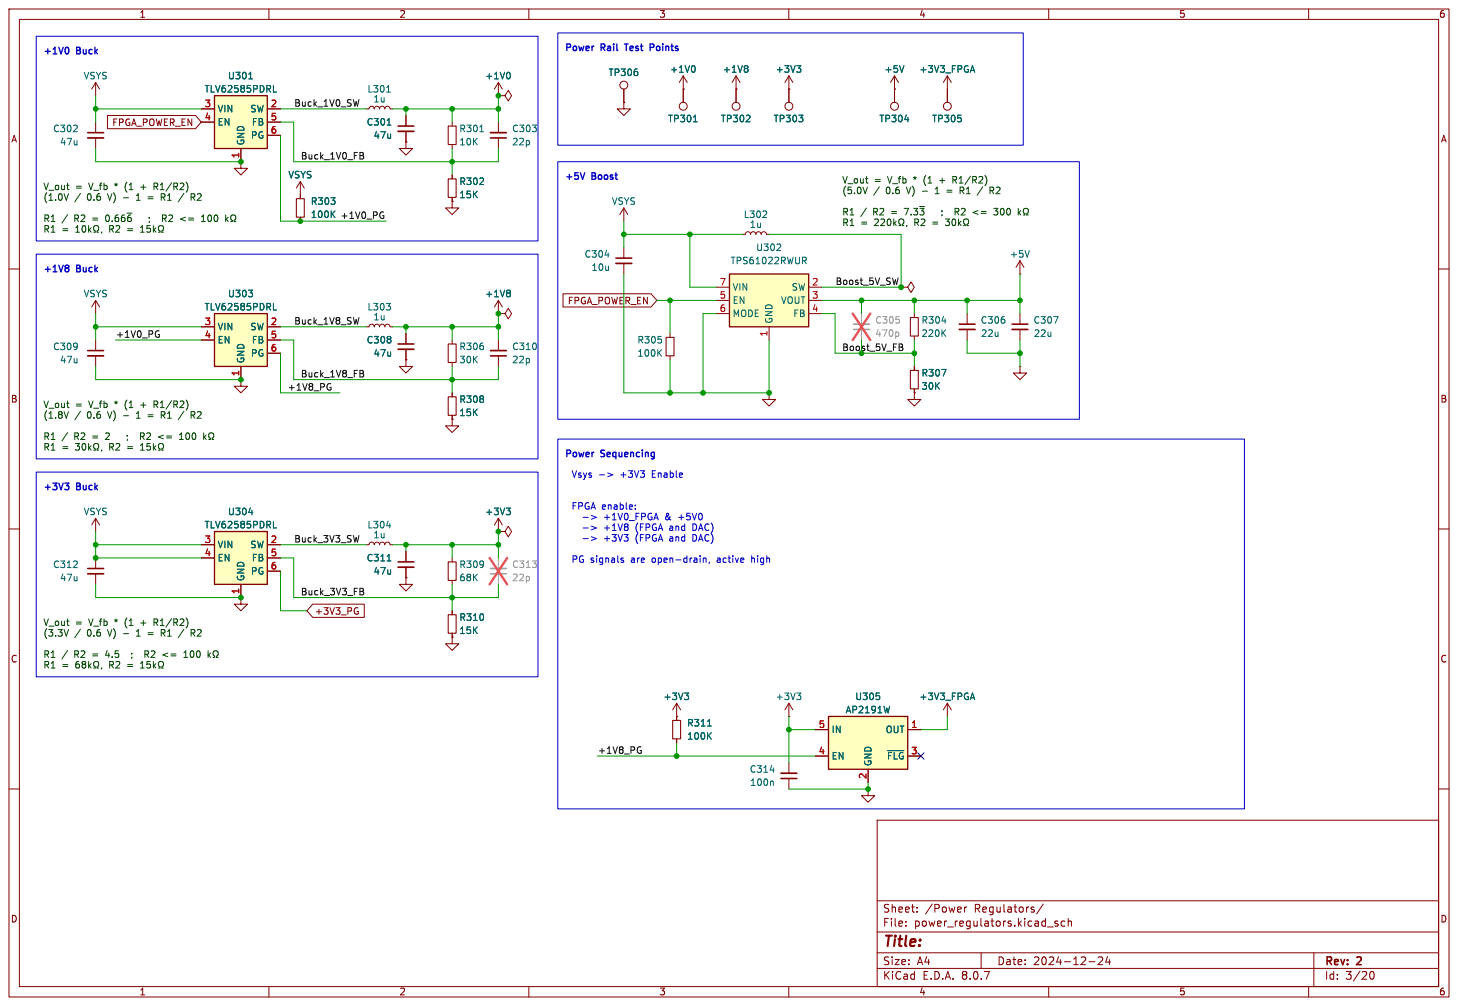
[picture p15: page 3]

1 SW 2 VIN 3 EN 4 FB 5 PG 6 U301 TLV62585PDRL C302

1 SW 2 VIN 3 EN 4 FB 5 PG 6 VSYS C301

1 SW 2 VOUT 3 FB 4 EN 5 VIN 7 U302 TPS61022RWUR

1 SW 2 VIN 3 EN 4 FB 5 PG 6 U303 TLV62585PDRL VSYS C309

1 SW 2 VIN 3 EN 4 FB 5 PG 6 R308

1 SW 2 VIN 3 EN 4 FB 5 PG 6 U304 TLV62585PDRL R311

1 SW 2 VIN 3 EN 4 FB 5 PG 6 C311

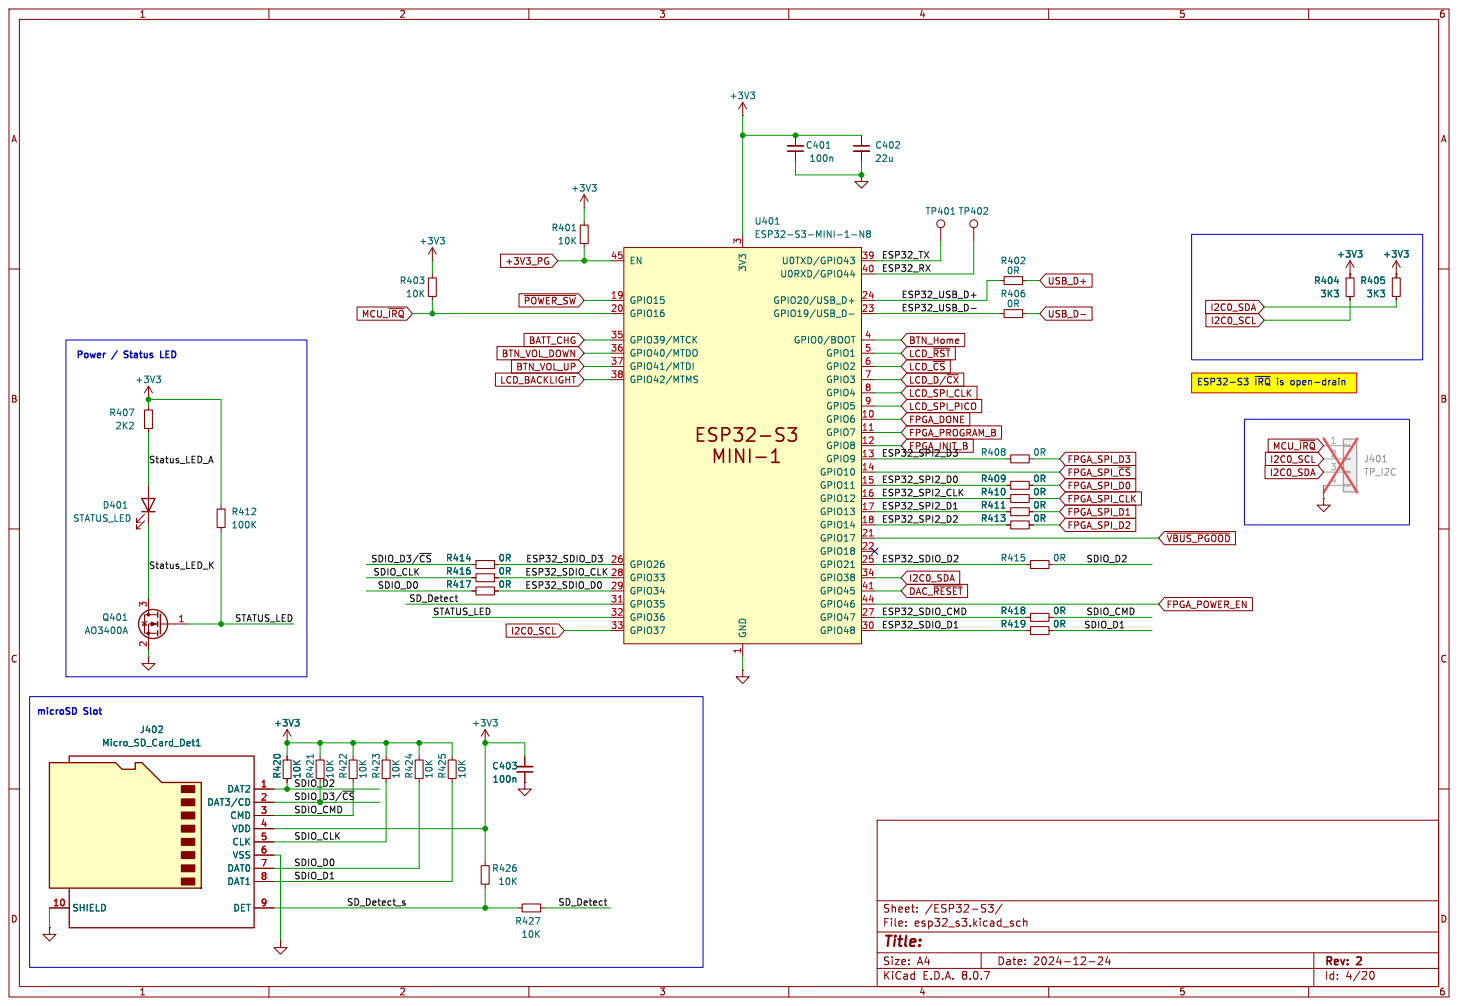
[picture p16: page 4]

3 GPIO0/BOOT 4 GPIO45 41 GPIO46 44 EN 45 GPIO6 10 GPIO7 11 GPIO8 12 GPIO9 13 GPIO10 14 GPIO11 15 GPIO12 16 GPIO13 17 GPIO14 18 GPIO15 19 GPIO16 20 GPIO17 21 GPIO18 22 GPIO19/USB_D- 23 GPIO20/USB_D+ 24 GPIO47 27 GPIO33 28 GPIO34 29 GPIO48 30 GPIO35 31 GPIO36 32 GPIO37 33 GPIO38 34 GPIO39/MTCK 35 GPIO40/MTDO 36 GPIO41/MTDI 37 GPIO42/MTMS 38 U0TXD/GPIO43 39 U0RXD/GPIO44 40 GPIO1 5 GPIO2 6 GPIO3 7 GPIO4 8 GPIO5 9 U401 ESP32-S3-MINI-1-N8 +3V3 D401 STATUS_LED

ESP32_SPI2_D1 ESP32_SPI2_D2 microSD Slot Power / Status LED

Id: 4/20 Title: File: esp32_s3.kicad_sch Sheet: /ESP32-S3/ R426

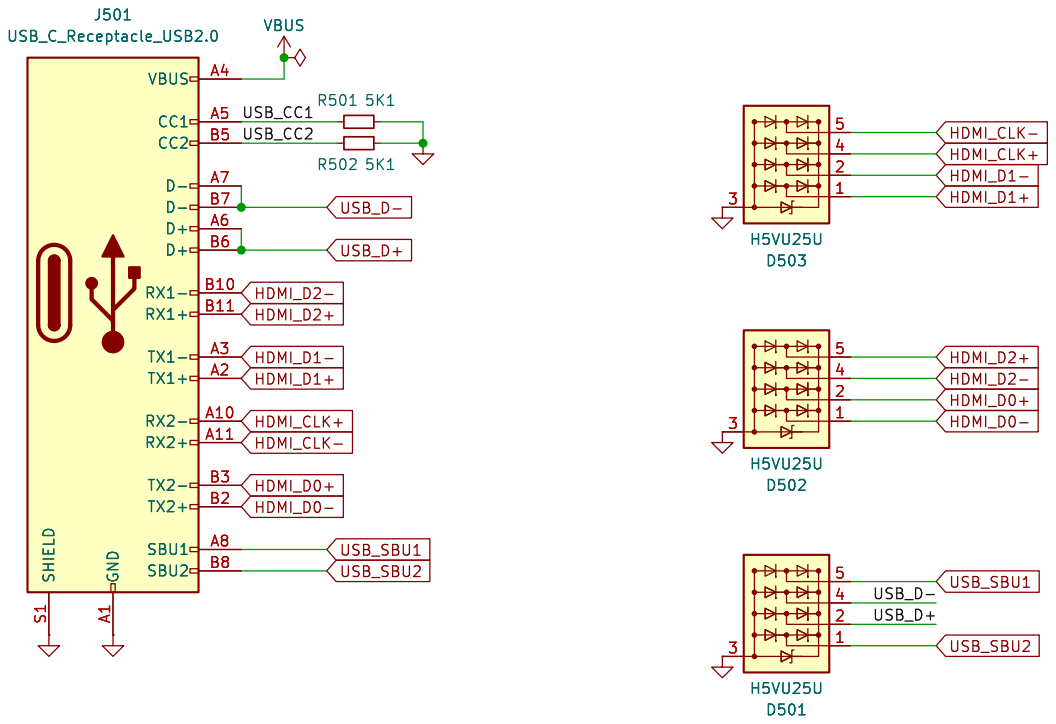
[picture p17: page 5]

Id: 5/20 Title: File: usb.kicad_sch Sheet: /USB/

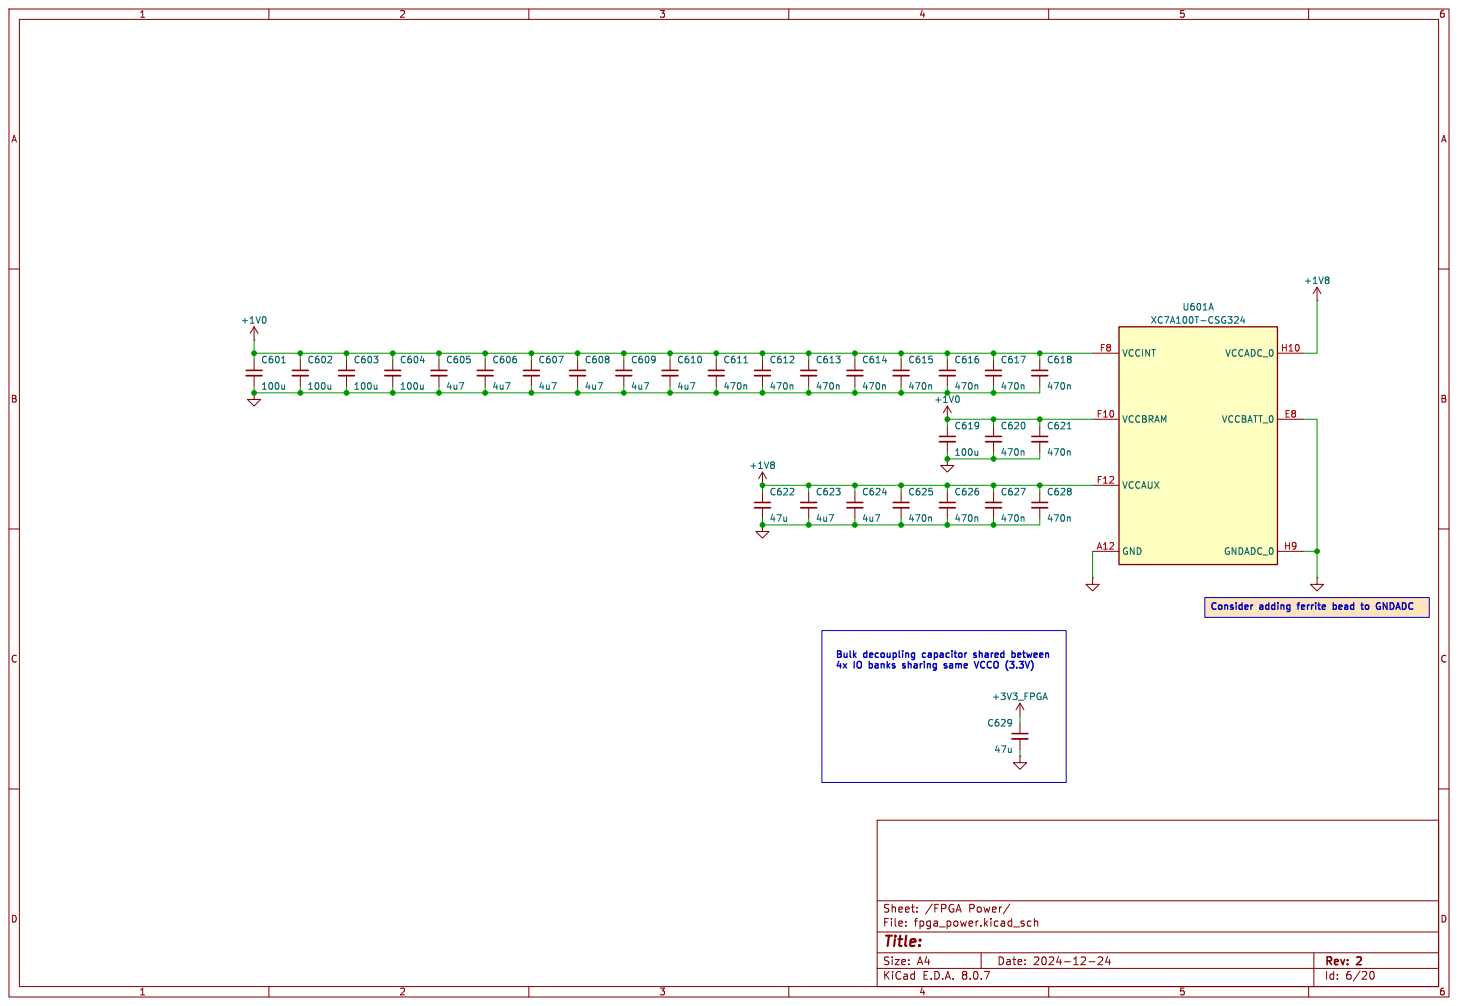
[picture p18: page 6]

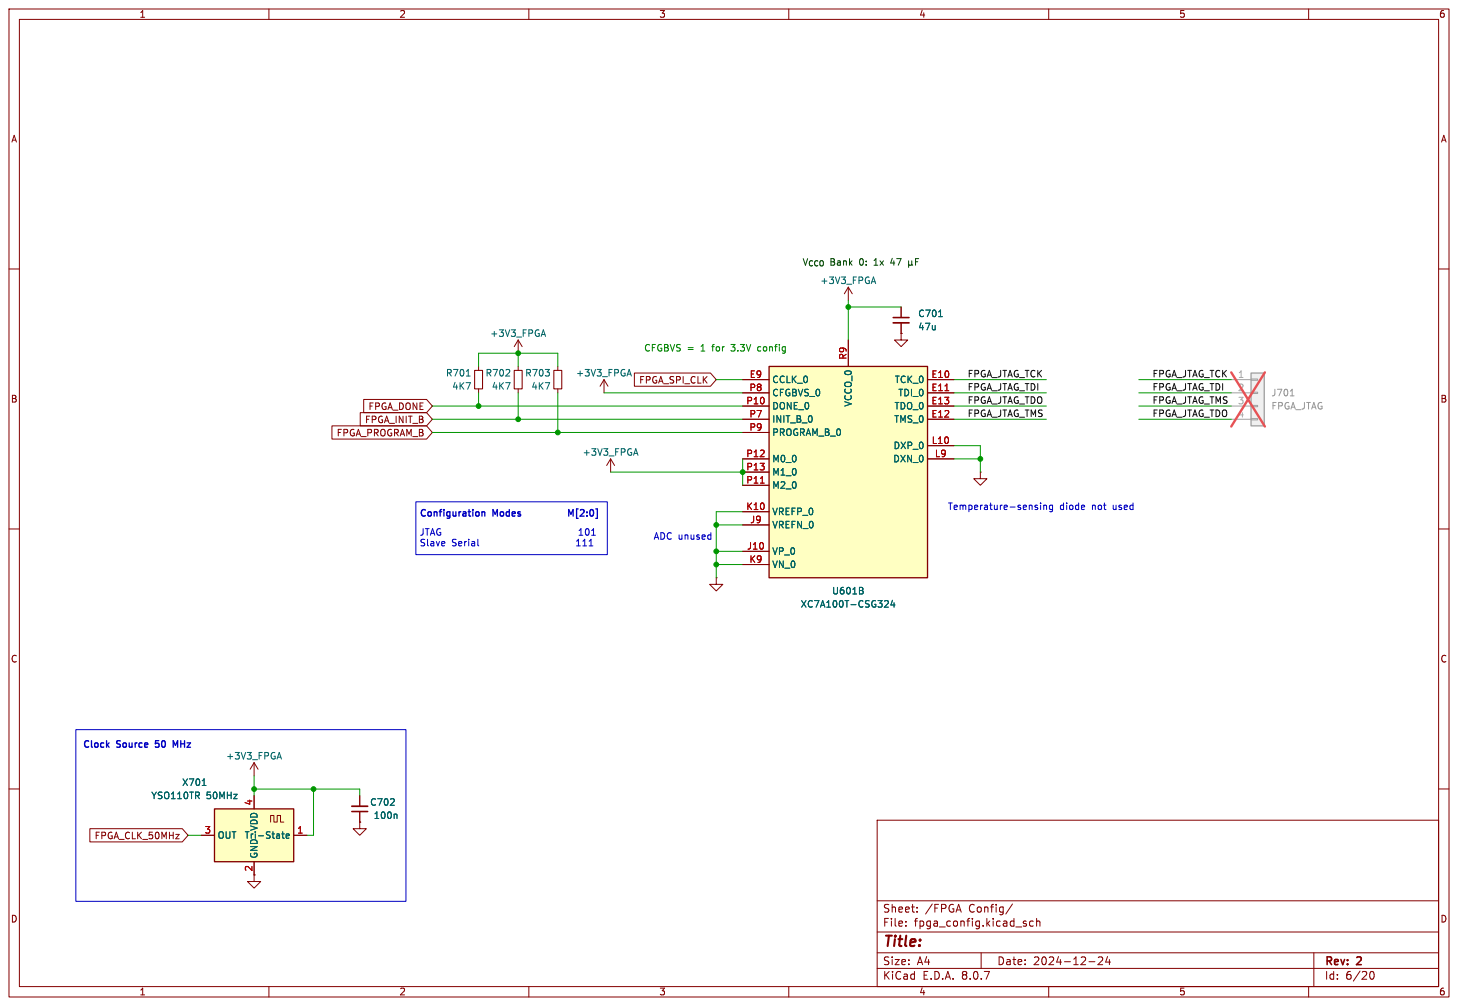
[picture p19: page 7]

Id: 6/20 Title: File: fpga_config.kicad_sch Sheet: /FPGA Config/

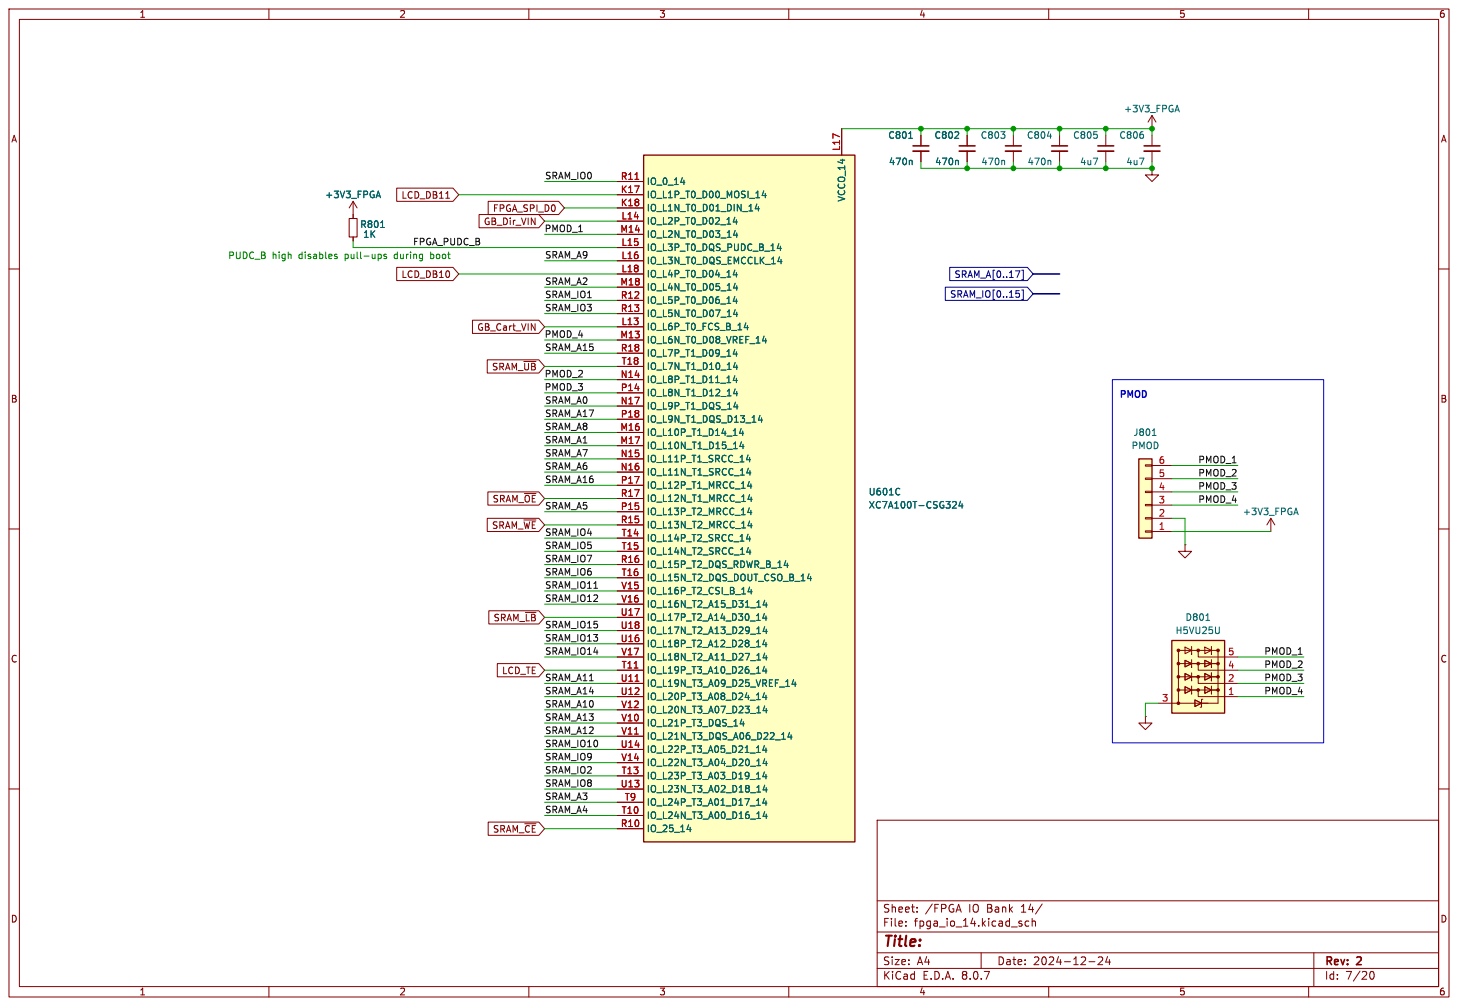
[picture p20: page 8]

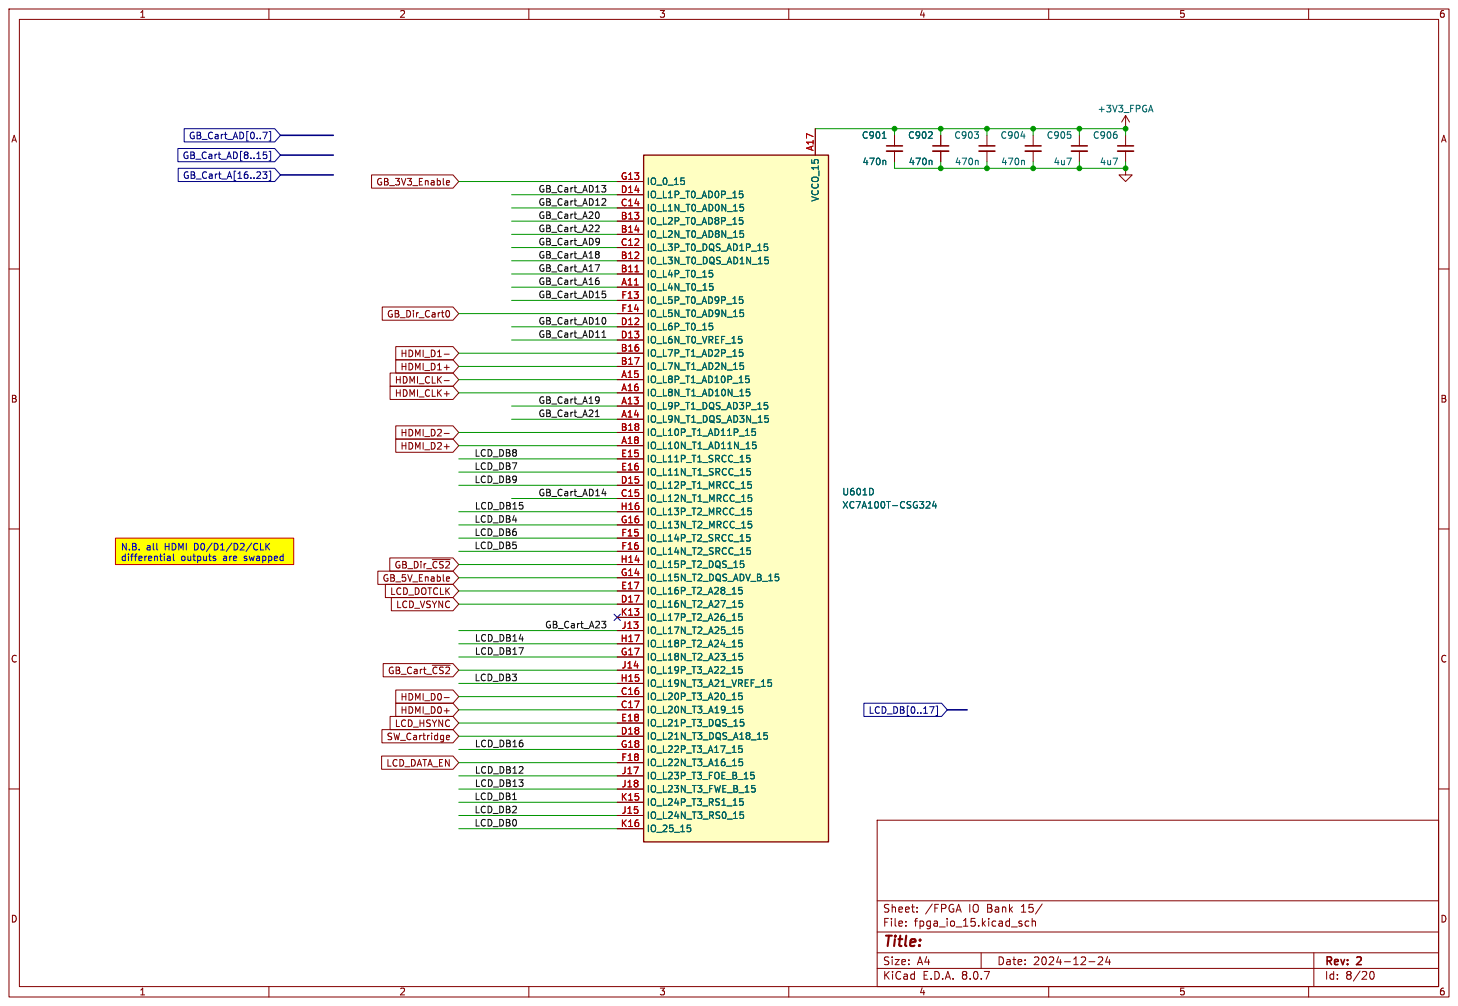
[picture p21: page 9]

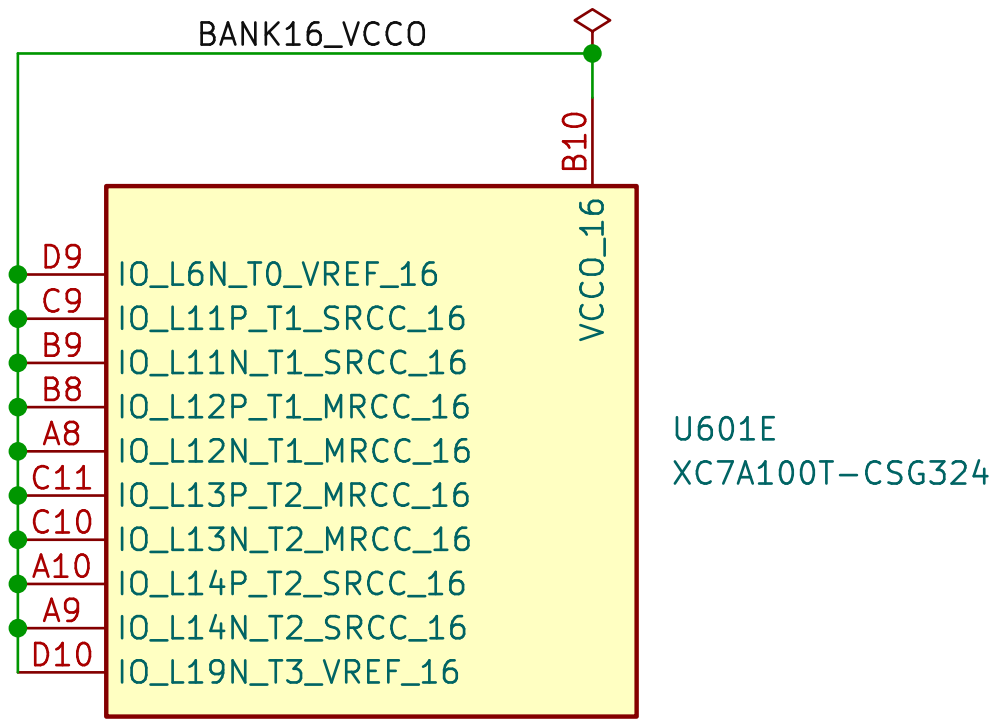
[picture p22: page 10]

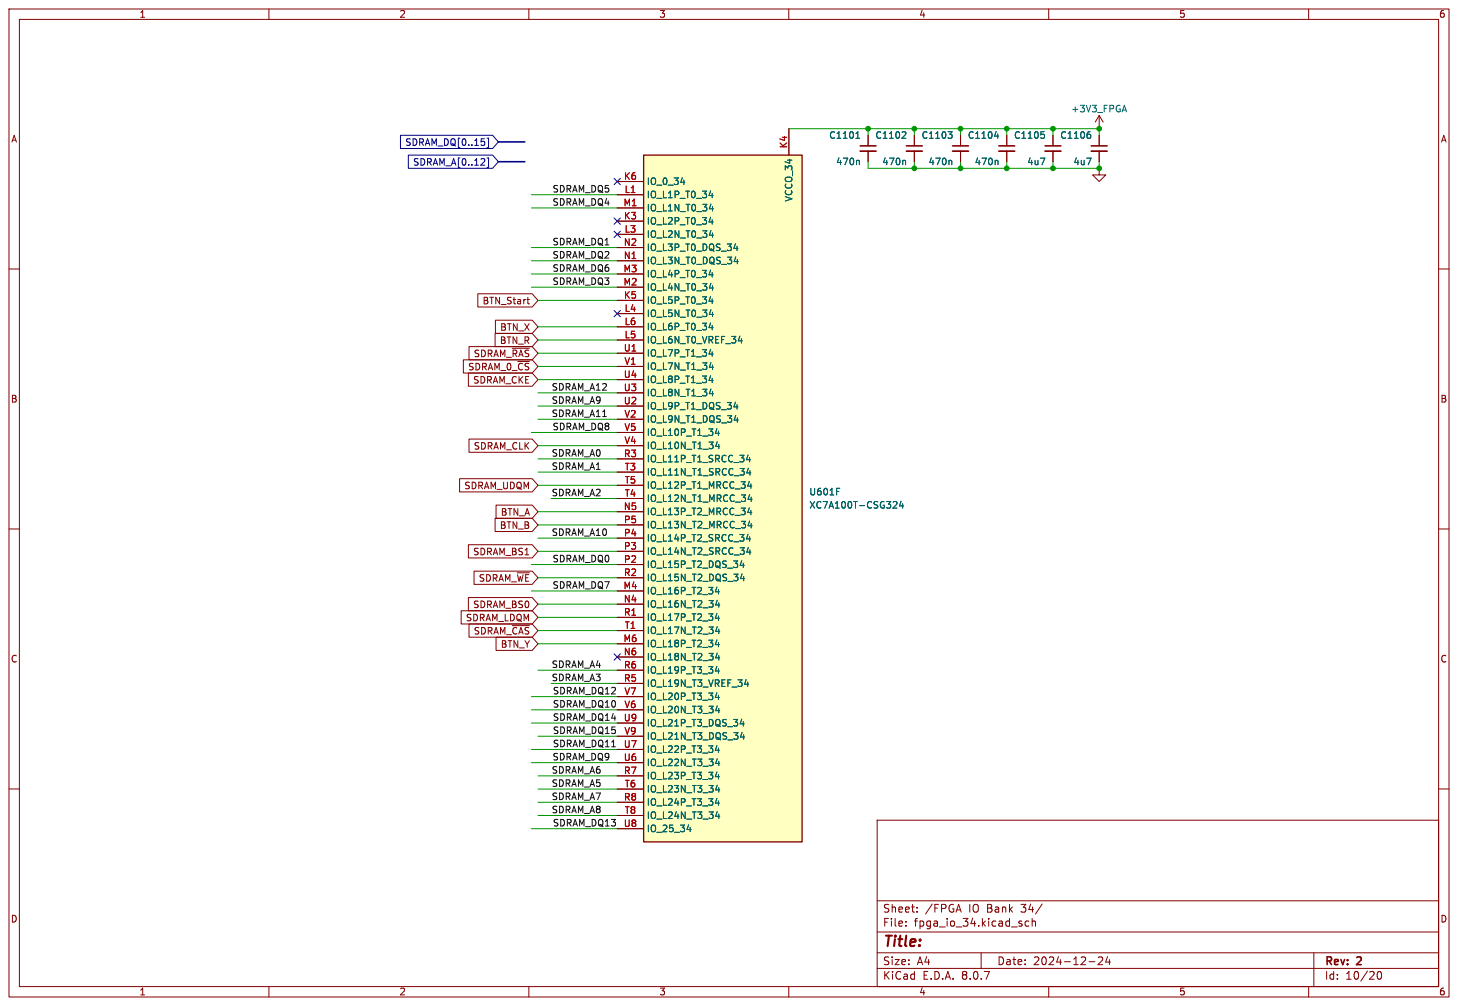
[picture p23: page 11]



Id: 12/20 Title: File: lcd.kicad_sch Sheet: /LCD/


3 A5 30 A6 31 A7 32 A8 33 A9 34 A11 35 A12 36 CKE 37 CLK 38 UDQM 39 DQ1 4 DQ8 42 DQ9 44 DQ10 45 DQ11 47 DQ12 48 DQ2 5 DQ13 50 DQ14 51 DQ15 53 VSSQ

Id: 13/20 Title: File: ram.kicad_sch Sheet: /RAM/


4 SDA 5 SCL 6 CLKO 7 VDD

Honestly it's pretty much a guess


Id: 15/20 Title: File: buttons.kicad_sch Sheet: /Buttons/ R1628


3 HPR 30 ~{RESET} 31 GPIO1 32 EP 33 NC 4 DIN 5 WCLK 6 BCLK 7 MCLK 8 SDA 9U1701 TLV320DAC3101 C1702

1 SCL 10 VOL/MICDET 11 MICBIAS 12 AIN1 13 AIN2 14 NC 15 AVSS 16 AVDD 17 DVSS 18 SPLM 19 IOVDD
I2C0_SDA DAC_BCLK DAC_DIN
I2C0_SCL

2 SPLVSS 20 SPLVDD 21 SPLP 22 SPRM 23 SPRVDD 24 SPRVSS 25 SPRP 26 HPL 27 HPVDD 28 HPVSS 29 DVDD

Headphone Jack CTIA (Apple) style

Id: 16/20 Title: File: audio.kicad_sch Sheet: /Audio/ C1714

Tip is Left R1 is Right R2 is GND


It's easier to route +3V3 R1805

This could be +3V3_FPGA or +3V3


VDD 1 AD4/A4 10 AD5/A5 11 AD6/A6 12 AD7/A7 13 AD8/A8 14 AD9/A9 15 AD10/A10 16 AD11/A11 17 AD12/A12 18 AD13/A13 19 PHI 2 AD14/A14 20 AD15/A15 21 A16/D0 22 A17/D1 23 A18/D2 24 A19/D3 25 A20/D4 26 A21/D5 27 A22/D6 28 A23/D7 29 ~{WR}3 ~{CS2}/~{RES} 30 ~{REQ}/VIN31 GND 32 ~{RD}4 ~{CS1}/~{CS} 5 AD0/A0 6 AD1/A1 7 AD2/A2 8 AD3/A3 9 MP


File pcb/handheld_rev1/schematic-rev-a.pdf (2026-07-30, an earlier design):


File: lcd.kicad_sch Power Path File: power_path.kicad_sch RAM

File: handheld.kicad_sch Sheet: /
Id: 1/20 Title: Game Bub Handheld


4 QSTRT 6 SCL 7 SDA 8 EP

R_{ISET} = 890 þÿA©/ I = 890 / 0.89A R_{ISET} = 1.0 þÿk©

http://www.mosaic-industries.com/embedded-systems/microcontroller-projects/electronic-circuits/push-button-switch-turn-on/microcontroller

Level shifts and inverts the CHG signal


Power Rail Test Points V_out = V_fb * (1 + R1/R2)
+1V0 Buck

1 SW 2 VIN 3 EN 4 FB 5 PG 6 U301 TLV62585PDRL VSYS C302

1 SW 2 VIN 3 EN 4 FB 5 PG 6 +1V8 R302

1 SW 2 VOUT 3 FB 4 EN 5 VIN 7 U302 TPS61022RWUR

1 SW 2 VOUT 3 FB 4 EN 5 VIN 7 R305

1 SW 2 VIN 3 EN 4 FB 5 PG 6 U303 TLV62585PDRL C309

1 SW 2 VIN 3 EN 4 FB 5 PG 6 R306

1 SW 2 VIN 3 EN 4 FB 5 PG 6 U304 TLV62585PDRL VSYS R307

1 SW 2 VIN 3 EN 4 FB 5 PG 6 R308


Reset Power / Status LED

2 GPIO12 20 GPIO13 21 GPIO14 22 GPIO21 23 GPIO47 24 GPIO48 25 GPIO45 26 GPIO0/BOOT 27 GPIO35 28 GPIO36 29 EN 3 GPIO37 30 GPIO38 31 GPIO39/MTCK 32 GPIO40/MTDO 33 GPIO41/MTDI 34 GPIO42/MTMS 35 U0RXD/GPIO44 36 U0TXD/GPIO43 37 GPIO2 38 GPIO1 39 GPIO4 4 GPIO5 5 GPIO6 6 GPIO7 7 GPIO15 8 GPIO16 9 U401 ESP32-S3-WROOM-1 R412 0R

Id: 4/20 Title: File: esp32_s3.kicad_sch Sheet: /ESP32-S3/



Id: 6/20 Title: File: fpga_config.kicad_sch Sheet: /FPGA Config/ C602







Each AP2502 channel provides 20mA
Total of 120mA from the two

Id: 12/20 Title: File: lcd.kicad_sch Sheet: /LCD/ +3V3 C1203


3 A5 30 A6 31 A7 32 A8 33 A9 34 A11 35 A12 36 CKE 37 CLK 38 UDQM 39 DQ1 4 DQ8 42 DQ9 44 DQ10 45 DQ11 47 DQ12 48 DQ2 5 DQ13 50 DQ14 51 DQ15 53 VSSQ

Id: 13/20 Title: File: ram.kicad_sch Sheet: /RAM/


to be unused RTC

to be unused See NXP UM10301

4 SDA 5 SCL 6 CLKO 7 VDD

Id: 14/20 Title: File: peripherals.kicad_sch Sheet: /Peripherals/ 1 2
JP1402 SolderJumper_2_Bridged

Honestly it's pretty much a guess


Id: 15/20 Title: File: buttons.kicad_sch Sheet: /Buttons/ R1525


3 HPR 30 ~{RESET} 31 GPIO1 32 EP 33 NC 4 DIN 5 WCLK 6 BCLK 7 MCLK 8 SDA 9U1601 TLV320DAC3101 C1605

1 SCL 10 VOL/MICDET 11 MICBIAS 12 AIN1 13 AIN2 14 NC 15 AVSS 16 AVDD 17 DVSS 18 SPLM 19 IOVDD

2 SPLVSS 20 SPLVDD 21 SPLP 22 SPRM 23 SPRVDD 24 SPRVSS 25 SPRP 26 HPL 27 HPVDD 28 HPVSS 29 DVDD

nFET converts push-pull

check polarity and pins of speaker

Tip is Left R1 is Right R2 is GND

Id: 16/20 Title: File: audio.kicad_sch Sheet: /Audio/



It's easier to route +3V3 R1805


VDD 1 AD4/A4 10 AD5/A5 11 AD6/A6 12 AD7/A7 13 AD8/A8 14 AD9/A9 15 AD10/A10 16 AD11/A11 17 AD12/A12 18 AD13/A13 19 PHI 2 AD14/A14 20 AD15/A15 21 A16/D0 22 A17/D1 23 A18/D2 24 A19/D3 25 A20/D4 26 A21/D5 27 A22/D6 28 A23/D7 29 ~{WR}3 ~{CS2}/~{RES} 30 ~{REQ}/VIN31 GND 32 ~{RD}4 ~{CS1}/~{CS} 5 AD0/A0 6 AD1/A1 7 AD2/A2 8 AD3/A3 9 MP


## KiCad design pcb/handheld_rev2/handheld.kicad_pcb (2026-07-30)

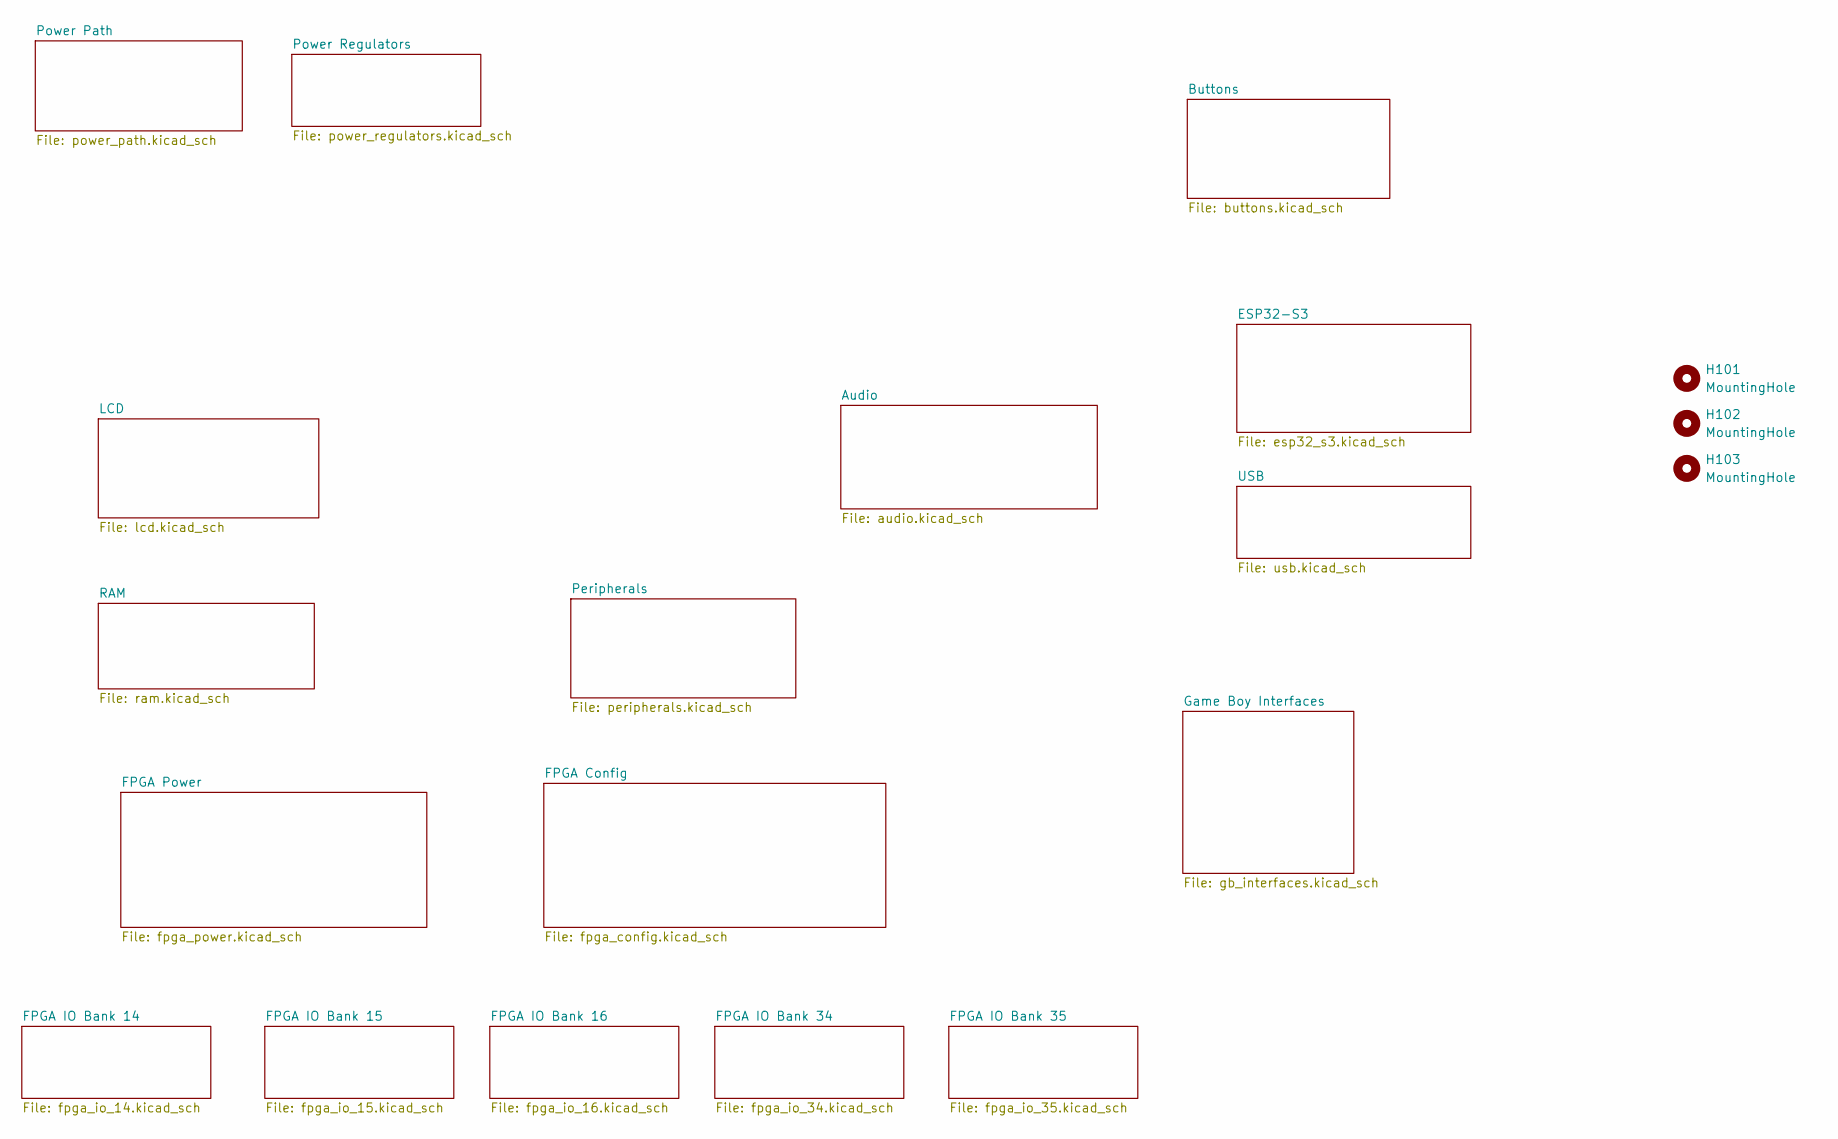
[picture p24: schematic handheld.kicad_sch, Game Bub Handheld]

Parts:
H101, H102, H103: MountingHole; MountingHole_2.7mm_M2.5

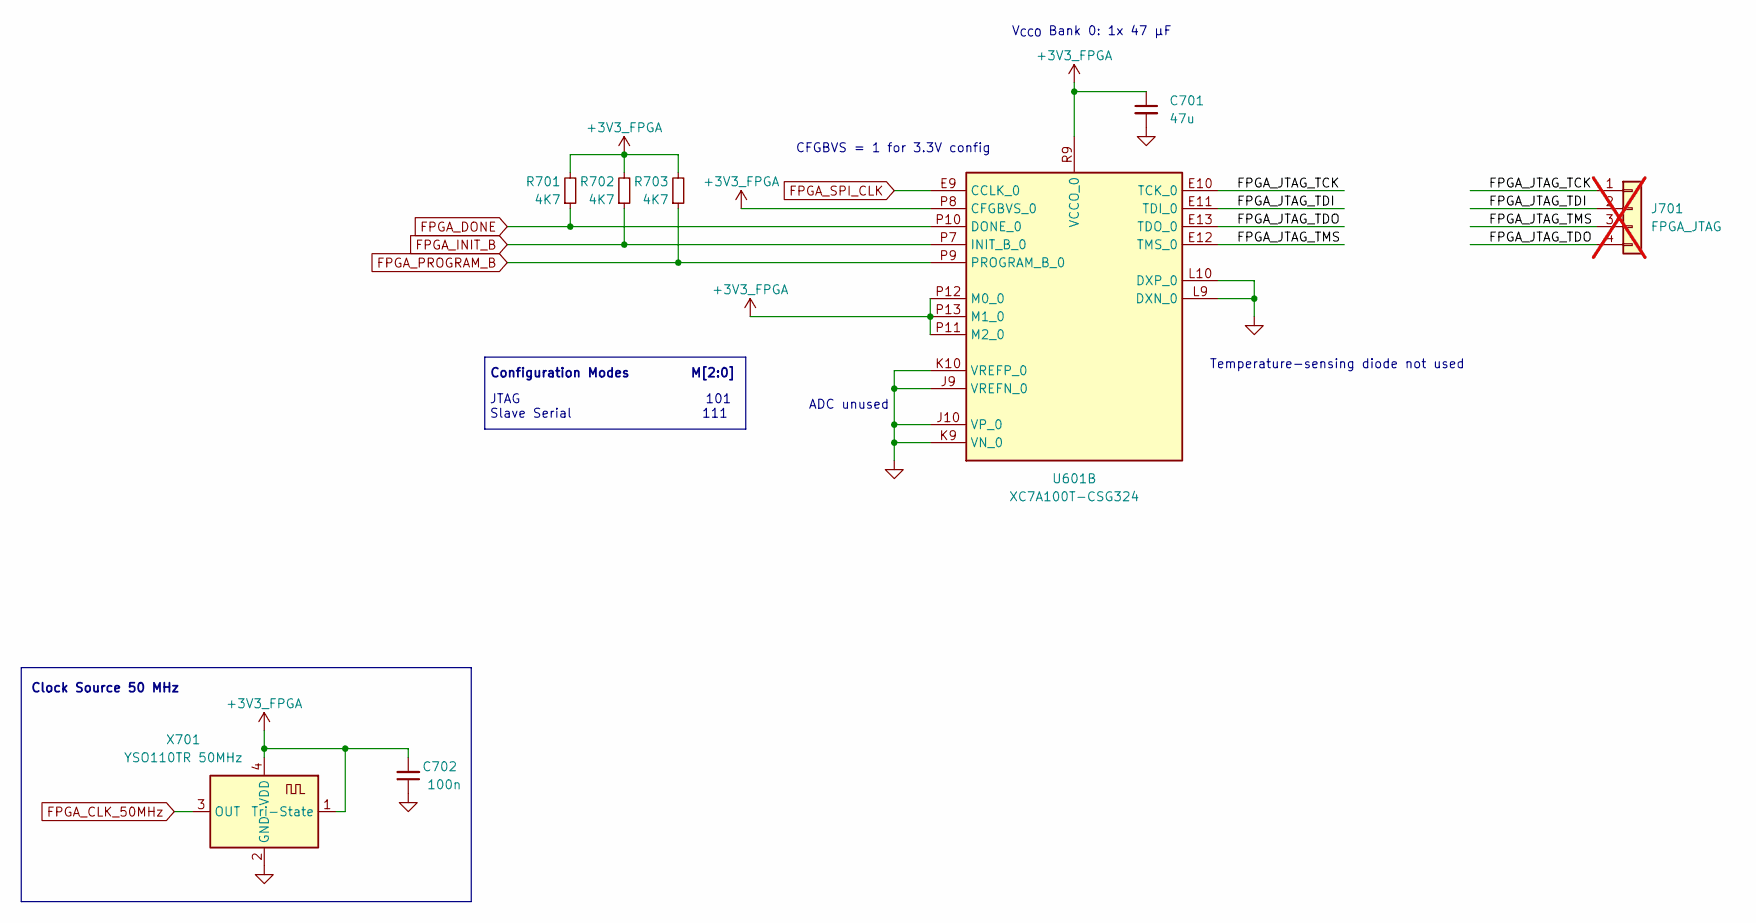
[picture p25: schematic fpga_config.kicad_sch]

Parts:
C701: 47u; C_0805_2012Metric; LCSC C16780
C702: 100n; C_0402_1005Metric; LCSC C1525
J701: FPGA_JTAG; PinSocket_1x04_P2.54mm_Vertical; not fitted
R701, R702, R703: 4K7; R_0402_1005Metric; LCSC C25900
U601: XC7A100T-CSG324; Xilinx_CSG324; LCSC C1521791
X701: YSO110TR 50MHz; Oscillator_SMD_SeikoEpson_SG8002CE-4Pin_3.2x2.5mm; LCSC C5203552

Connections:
+3V3_FPGA: C701.1, C702.2, R701.2, R702.2, R703.2, U601.P8 (CFGBVS_0), U601.P11 (M2_0), U601.P12 (M0_0), U601.P13 (M1_0), U601.R9 (VCCO_0), X701.1 (Tri-State), X701.4 (VDD); also elsewhere on the board
/FPGA Config/FPGA_JTAG_TCK: J701.1, U601.E10 (TCK_0)
/FPGA Config/FPGA_JTAG_TDI: J701.2, U601.E11 (TDI_0)
/FPGA Config/FPGA_JTAG_TDO: J701.4, U601.E13 (TDO_0)
/FPGA Config/FPGA_JTAG_TMS: J701.3, U601.E12 (TMS_0)
FPGA_CLK_50MHz: X701.3 (OUT); also elsewhere on the board
FPGA_DONE: R701.1, U601.P10 (DONE_0); also elsewhere on the board
FPGA_INIT_B: R702.1, U601.P7 (INIT_B_0); also elsewhere on the board
FPGA_PROGRAM_B: R703.1, U601.P9 (PROGRAM_B_0); also elsewhere on the board
FPGA_SPI_CLK: U601.E9 (CCLK_0); also elsewhere on the board
GND: C701.2, C702.1, U601.J9 (VREFN_0), U601.J10 (VP_0), U601.K9 (VN_0), U601.K10 (VREFP_0), U601.L9 (DXN_0), U601.L10 (DXP_0), X701.2 (GND); also elsewhere on the board

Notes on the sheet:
Clock Source 50 MHz
JTAG 101 Slave Serial 111
V_{CCO} Bank 0: 1x 47 µF
ADC unused
CFGBVS = 1 for 3.3V config
Temperature-sensing diode not used
Configuration Modes M[2:0]

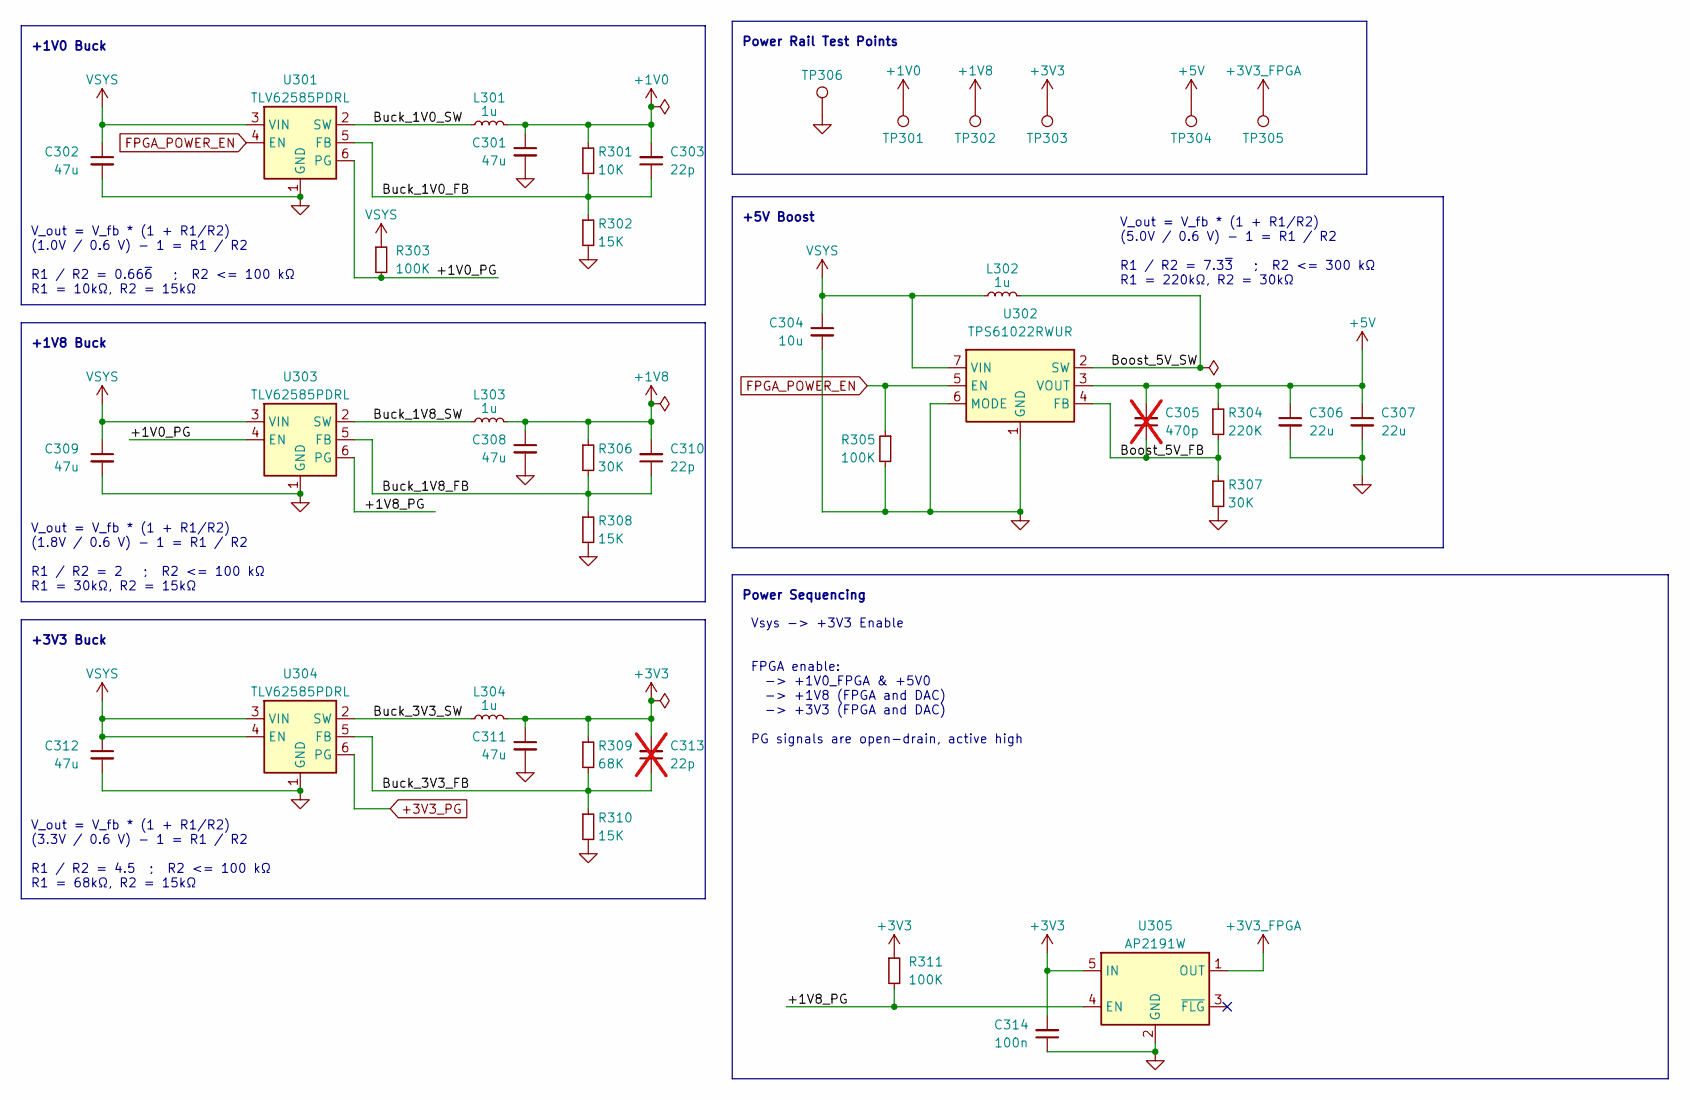
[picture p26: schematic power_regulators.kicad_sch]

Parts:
C301, C302, C308, C309, C311, C312: 47u; C_0805_2012Metric; LCSC C16780
C303, C310: 22p; C_0402_1005Metric; LCSC C1555
C304: 10u; C_0402_1005Metric; LCSC C15525
C305: 470p; C_0402_1005Metric; LCSC C1537; not fitted
C306, C307: 22u; C_0805_2012Metric; LCSC C45783
C313: 22p; C_0402_1005Metric; LCSC C1555; not fitted
C314: 100n; C_0402_1005Metric; LCSC C1525
L301, L302, L303, L304: 1u; L_Sunlord_SWPA252012S; LCSC C98348
R301: 10K; R_0402_1005Metric; LCSC C25744
R302, R308, R310: 15K; R_0402_1005Metric; LCSC C25756
R303, R305, R311: 100K; R_0402_1005Metric; LCSC C25741
R304: 220K; R_0603_1608Metric; LCSC C22961
R306, R307: 30K; R_0402_1005Metric; LCSC C25776
R309: 68K; R_0402_1005Metric; LCSC C36871
TP301: +1V0; TestPoint_2.54mm_THT
TP302: +1V8; TestPoint_2.54mm_THT
TP303: +3V3; TestPoint_2.54mm_THT
TP304: +5V; TestPoint_2.54mm_THT
TP305: +3V3_FPGA; TestPoint_2.54mm_THT
TP306: GND; TestPoint_2.54mm_THT
U301, U303, U304: TLV62585PDRL; SOT-563; LCSC C485118
U302: TPS61022RWUR; VQFN-7_L2.0-W2.0-P0.55-TL_RWU; LCSC C915088
U305: AP2191W; SOT-23-5; LCSC C141321

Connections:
+1V0: C301.1, C303.2, L301.2, R301.1, TP301.1; also elsewhere on the board
+1V8: C308.1, C310.2, L303.2, R306.1, TP302.1; also elsewhere on the board
+3V3: C311.1, C313.2, C314.2, L304.2, R309.1, R311.1, TP303.1, U305.5 (IN); also elsewhere on the board
+3V3_FPGA: TP305.1, U305.1 (OUT); also elsewhere on the board
+3V3_PG: U304.6 (PG); also elsewhere on the board
+5V: C305.2, C306.1, C307.1, R304.1, TP304.1, U302.3 (VOUT); also elsewhere on the board
/Power Regulators/+1V0_PG: R303.2, U301.6 (PG), U303.4 (EN)
/Power Regulators/+1V8_PG: R311.2, U303.6 (PG), U305.4 (EN)
/Power Regulators/Boost_5V_FB: C305.1, R304.2, R307.1, U302.4 (FB)
/Power Regulators/Boost_5V_SW: L302.2, U302.2 (SW)
/Power Regulators/Buck_1V0_FB: C303.1, R301.2, R302.1, U301.5 (FB)
/Power Regulators/Buck_1V0_SW: L301.1, U301.2 (SW)
/Power Regulators/Buck_1V8_FB: C310.1, R306.2, R308.1, U303.5 (FB)
/Power Regulators/Buck_1V8_SW: L303.1, U303.2 (SW)
/Power Regulators/Buck_3V3_FB: C313.1, R309.2, R310.1, U304.5 (FB)
/Power Regulators/Buck_3V3_SW: L304.1, U304.2 (SW)
FPGA_POWER_EN: R305.1, U301.4 (EN), U302.5 (EN); also elsewhere on the board
GND: C301.2, C302.2, C304.2, C306.2, C307.2, C308.2, C309.2, C311.2, C312.2, C314.1, R302.2, R305.2, R307.2, R308.2, R310.2, TP306.1, U301.1 (GND), U302.1 (GND), U302.6 (MODE), U303.1 (GND), U304.1 (GND), U305.2 (GND); also elsewhere on the board
VSYS: C302.1, C304.1, C309.1, C312.1, L302.1, R303.1, U301.3 (VIN), U302.7 (VIN), U303.3 (VIN), U304.3 (VIN), U304.4 (EN); also elsewhere on the board

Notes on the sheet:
+1V8 Buck
V_out = V_fb * (1 + R1/R2) (5.0V / 0.6 V) - 1 = R1 / R2 R1 / R2 = 7.3~{3} ; R2 <= 300 kΩ R1 = 220kΩ, R2 = 30kΩ
V_out = V_fb * (1 + R1/R2) (3.3V / 0.6 V) - 1 = R1 / R2 R1 / R2 = 4.5 ; R2 <= 100 kΩ R1 = 68kΩ, R2 = 15kΩ
+1V0 Buck
V_out = V_fb * (1 + R1/R2) (1.8V / 0.6 V) - 1 = R1 / R2 R1 / R2 = 2 ; R2 <= 100 kΩ R1 = 30kΩ, R2 = 15kΩ
Vsys -> +3V3 Enable FPGA enable: -> +1V0_FPGA & +5V0 -> +1V8 (FPGA and DAC) -> +3V3 (FPGA and DAC) PG signals are open-drain, active high
Power Rail Test Points
Power Sequencing
V_out = V_fb * (1 + R1/R2) (1.0V / 0.6 V) - 1 = R1 / R2 R1 / R2 = 0.66~{6} ; R2 <= 100 kΩ R1 = 10kΩ, R2 = 15kΩ
+3V3 Buck
+5V Boost

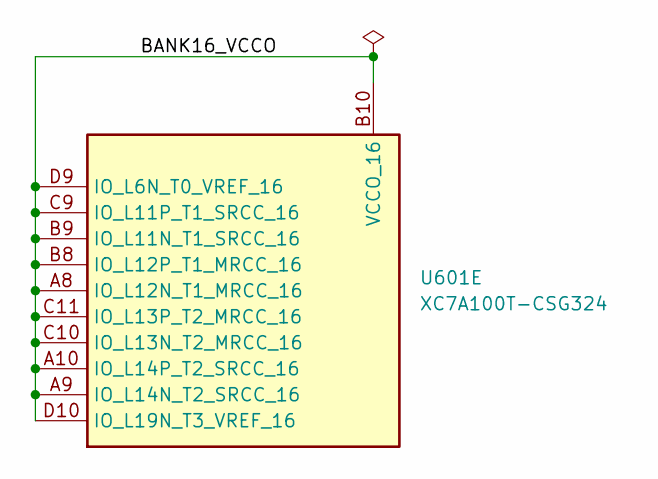
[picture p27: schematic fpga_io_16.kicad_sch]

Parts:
U601: XC7A100T-CSG324; Xilinx_CSG324; LCSC C1521791

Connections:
/FPGA IO Bank 16/BANK16_VCCO: U601.A8 (IO_L12N_T1_MRCC_16), U601.A9 (IO_L14N_T2_SRCC_16), U601.A10 (IO_L14P_T2_SRCC_16), U601.B8 (IO_L12P_T1_MRCC_16), U601.B9 (IO_L11N_T1_SRCC_16), U601.B10 (VCCO_16), U601.C9 (IO_L11P_T1_SRCC_16), U601.C10 (IO_L13N_T2_MRCC_16), U601.C11 (IO_L13P_T2_MRCC_16), U601.D9 (IO_L6N_T0_VREF_16), U601.D10 (IO_L19N_T3_VREF_16)

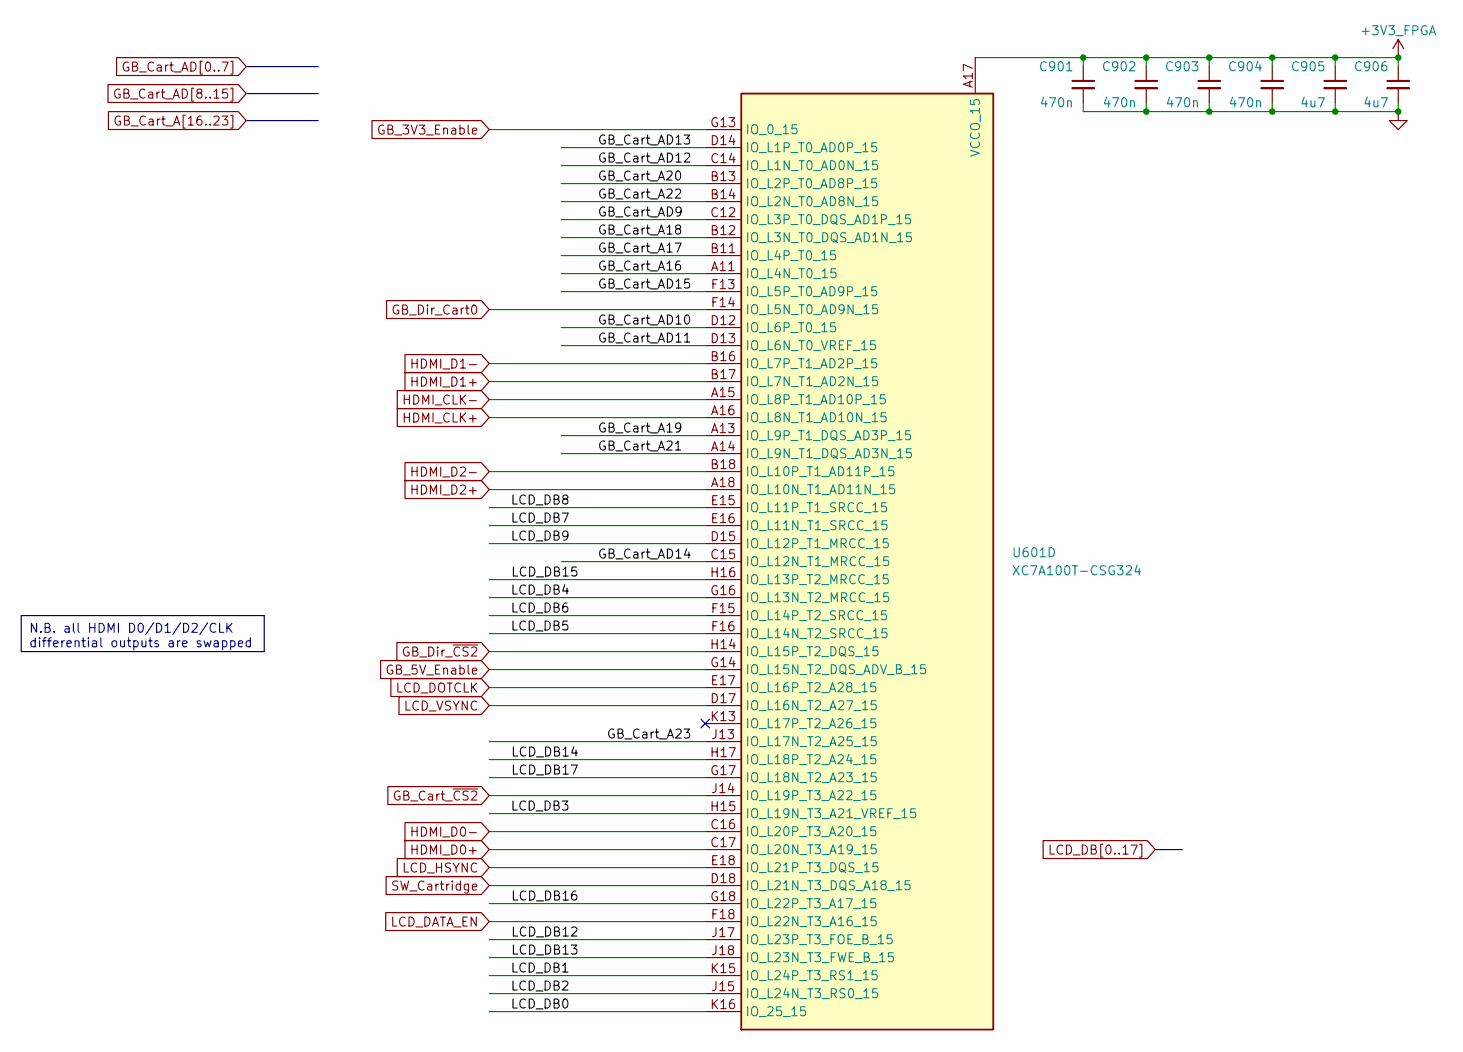
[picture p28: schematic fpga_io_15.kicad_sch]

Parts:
C901, C902, C903, C904: 470n; C_0402_1005Metric; LCSC C47339
C905, C906: 4u7; C_0402_1005Metric; LCSC C23733
U601: XC7A100T-CSG324; Xilinx_CSG324; LCSC C1521791

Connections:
+3V3_FPGA: C901.1, C902.1, C903.1, C904.1, C905.1, C906.1, U601.A17 (VCCO_15), U601.C13 (VCCO_15), U601.D16 (VCCO_15), U601.G15 (VCCO_15), U601.H18 (VCCO_15), U601.K14 (VCCO_15); also elsewhere on the board
GB_3V3_Enable: U601.G13 (IO_0_15); also elsewhere on the board
GB_5V_Enable: U601.G14 (IO_L15N_T2_DQS_ADV_B_15); also elsewhere on the board
GB_Cart_A16: U601.A11 (IO_L4N_T0_15); also elsewhere on the board
GB_Cart_A17: U601.B11 (IO_L4P_T0_15); also elsewhere on the board
GB_Cart_A18: U601.B12 (IO_L3N_T0_DQS_AD1N_15); also elsewhere on the board
GB_Cart_A19: U601.A13 (IO_L9P_T1_DQS_AD3P_15); also elsewhere on the board
GB_Cart_A20: U601.B13 (IO_L2P_T0_AD8P_15); also elsewhere on the board
GB_Cart_A21: U601.A14 (IO_L9N_T1_DQS_AD3N_15); also elsewhere on the board
GB_Cart_A22: U601.B14 (IO_L2N_T0_AD8N_15); also elsewhere on the board
GB_Cart_A23: U601.J13 (IO_L17N_T2_A25_15); also elsewhere on the board
GB_Cart_AD9: U601.C12 (IO_L3P_T0_DQS_AD1P_15); also elsewhere on the board
GB_Cart_AD10: U601.D12 (IO_L6P_T0_15); also elsewhere on the board
GB_Cart_AD11: U601.D13 (IO_L6N_T0_VREF_15); also elsewhere on the board
GB_Cart_AD12: U601.C14 (IO_L1N_T0_AD0N_15); also elsewhere on the board
GB_Cart_AD13: U601.D14 (IO_L1P_T0_AD0P_15); also elsewhere on the board
GB_Cart_AD14: U601.C15 (IO_L12N_T1_MRCC_15); also elsewhere on the board
GB_Cart_AD15: U601.F13 (IO_L5P_T0_AD9P_15); also elsewhere on the board
GB_Cart_~CS2: U601.J14 (IO_L19P_T3_A22_15); also elsewhere on the board
GB_Dir_Cart0: U601.F14 (IO_L5N_T0_AD9N_15); also elsewhere on the board
GB_Dir_~CS2: U601.H14 (IO_L15P_T2_DQS_15); also elsewhere on the board
GND: C901.2, C902.2, C903.2, C904.2, C905.2, C906.2; also elsewhere on the board
HDMI_CLK+: U601.A16 (IO_L8N_T1_AD10N_15); also elsewhere on the board
HDMI_CLK-: U601.A15 (IO_L8P_T1_AD10P_15); also elsewhere on the board
HDMI_D0+: U601.C17 (IO_L20N_T3_A19_15); also elsewhere on the board
HDMI_D0-: U601.C16 (IO_L20P_T3_A20_15); also elsewhere on the board
HDMI_D1+: U601.B17 (IO_L7N_T1_AD2N_15); also elsewhere on the board
HDMI_D1-: U601.B16 (IO_L7P_T1_AD2P_15); also elsewhere on the board
HDMI_D2+: U601.A18 (IO_L10N_T1_AD11N_15); also elsewhere on the board
HDMI_D2-: U601.B18 (IO_L10P_T1_AD11P_15); also elsewhere on the board
LCD_DATA_EN: U601.F18 (IO_L22N_T3_A16_15); also elsewhere on the board
LCD_DB0: U601.K16 (IO_25_15); also elsewhere on the board
LCD_DB1: U601.K15 (IO_L24P_T3_RS1_15); also elsewhere on the board
LCD_DB2: U601.J15 (IO_L24N_T3_RS0_15); also elsewhere on the board
LCD_DB3: U601.H15 (IO_L19N_T3_A21_VREF_15); also elsewhere on the board
LCD_DB4: U601.G16 (IO_L13N_T2_MRCC_15); also elsewhere on the board
LCD_DB5: U601.F16 (IO_L14N_T2_SRCC_15); also elsewhere on the board
LCD_DB6: U601.F15 (IO_L14P_T2_SRCC_15); also elsewhere on the board
LCD_DB7: U601.E16 (IO_L11N_T1_SRCC_15); also elsewhere on the board
LCD_DB8: U601.E15 (IO_L11P_T1_SRCC_15); also elsewhere on the board
LCD_DB9: U601.D15 (IO_L12P_T1_MRCC_15); also elsewhere on the board
LCD_DB12: U601.J17 (IO_L23P_T3_FOE_B_15); also elsewhere on the board
LCD_DB13: U601.J18 (IO_L23N_T3_FWE_B_15); also elsewhere on the board
LCD_DB14: U601.H17 (IO_L18P_T2_A24_15); also elsewhere on the board
LCD_DB15: U601.H16 (IO_L13P_T2_MRCC_15); also elsewhere on the board
LCD_DB16: U601.G18 (IO_L22P_T3_A17_15); also elsewhere on the board
LCD_DB17: U601.G17 (IO_L18N_T2_A23_15); also elsewhere on the board
LCD_DOTCLK: U601.E17 (IO_L16P_T2_A28_15); also elsewhere on the board
LCD_HSYNC: U601.E18 (IO_L21P_T3_DQS_15); also elsewhere on the board
LCD_VSYNC: U601.D17 (IO_L16N_T2_A27_15); also elsewhere on the board
SW_Cartridge: U601.D18 (IO_L21N_T3_DQS_A18_15); also elsewhere on the board

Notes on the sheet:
N.B. all HDMI D0/D1/D2/CLK differential outputs are swapped

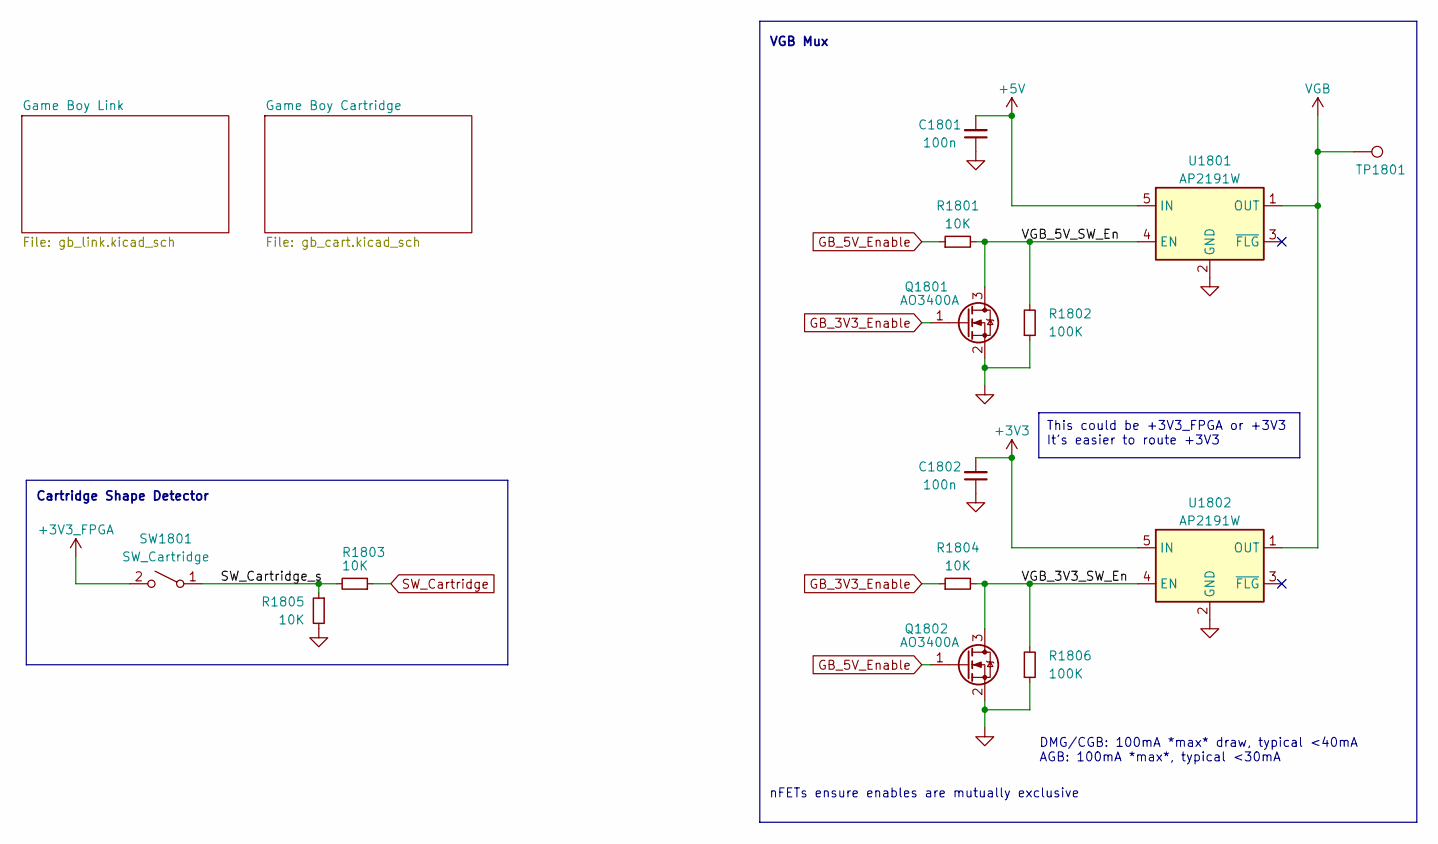
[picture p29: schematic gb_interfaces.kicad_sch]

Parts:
C1801, C1802: 100n; C_0402_1005Metric; LCSC C1525
Q1801, Q1802: AO3400A; SOT-23; LCSC C20917
R1801, R1803, R1804, R1805: 10K; R_0402_1005Metric; LCSC C25744
R1802, R1806: 100K; R_0402_1005Metric; LCSC C25741
SW1801: SW_Cartridge; JJOV0UL650NONPRBK_SIDE
TP1801: VGB; TestPoint_2.54mm_THT
U1801, U1802: AP2191W; SOT-23-5; LCSC C141321

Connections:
+3V3: C1802.2, U1802.5 (IN); also elsewhere on the board
+3V3_FPGA: SW1801.2 (B); also elsewhere on the board
+5V: C1801.2, U1801.5 (IN); also elsewhere on the board
/Game Boy Interfaces/SW_Cartridge_s: R1803.2, R1805.1, SW1801.1 (A)
/Game Boy Interfaces/VGB_3V3_SW_En: Q1802.3 (D), R1804.2, R1806.2, U1802.4 (EN)
/Game Boy Interfaces/VGB_5V_SW_En: Q1801.3 (D), R1801.2, R1802.2, U1801.4 (EN)
GB_3V3_Enable: Q1801.1 (G), R1804.1; also elsewhere on the board
GB_5V_Enable: Q1802.1 (G), R1801.1; also elsewhere on the board
GND: C1801.1, C1802.1, Q1801.2 (S), Q1802.2 (S), R1802.1, R1805.2, R1806.1, U1801.2 (GND), U1802.2 (GND); also elsewhere on the board
SW_Cartridge: R1803.1; also elsewhere on the board
VGB: TP1801.1, U1801.1 (OUT), U1802.1 (OUT); also elsewhere on the board

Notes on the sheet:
This could be +3V3_FPGA or +3V3 It's easier to route +3V3
DMG/CGB: 100mA *max* draw, typical <40mA AGB: 100mA *max*, typical <30mA
Cartridge Shape Detector
VGB Mux
nFETs ensure enables are mutually exclusive

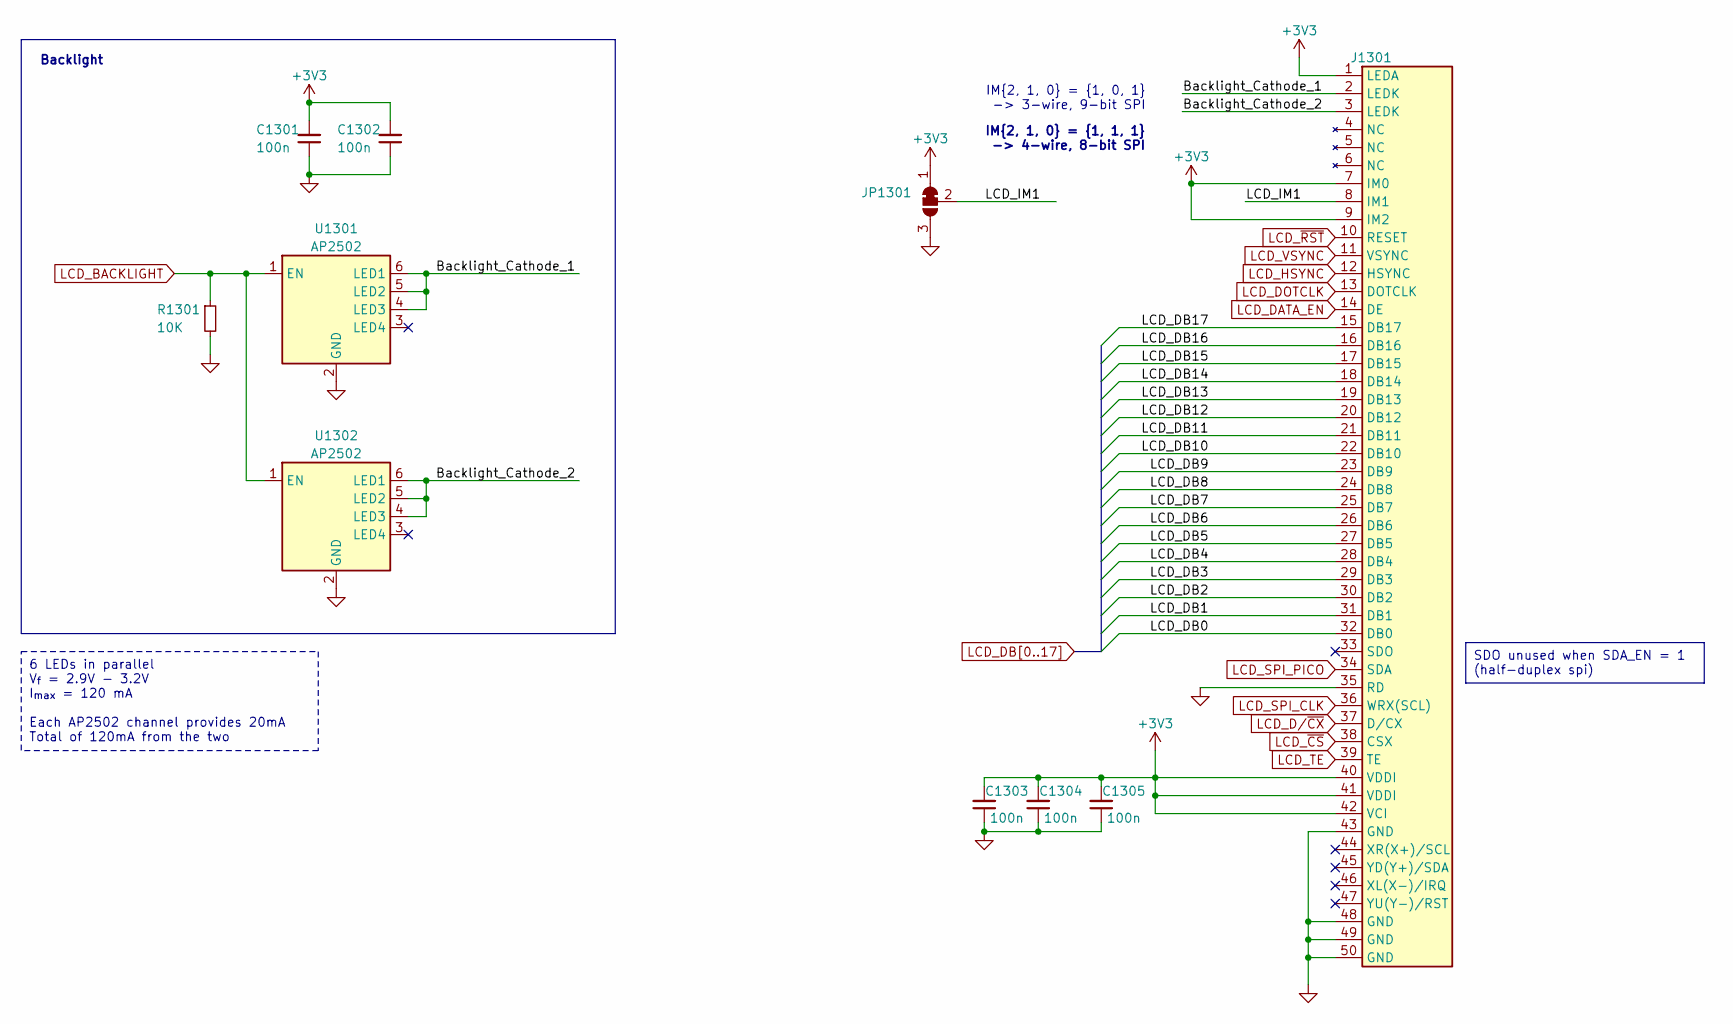
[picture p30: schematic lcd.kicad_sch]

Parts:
C1301, C1302, C1303, C1304, C1305: 100n; C_0402_1005Metric; LCSC C1525
J1301: Hirose_FH12S-50S-0.5SH_1x50-1MP_P0.50mm_Horizontal_FLIPPED; LCSC C598003
JP1301: SolderJumper_3_Bridged12; SolderJumper-3_P1.3mm_Bridged12_RoundedPad1.0x1.5mm
R1301: 10K; R_0402_1005Metric; LCSC C25744
U1301, U1302: AP2502; SOT-23-6; LCSC C460349

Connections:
+3V3: C1301.2, C1302.2, C1303.2, C1304.2, C1305.2, J1301.1 (LEDA), J1301.7 (IM0), J1301.9 (IM2), J1301.40 (VDDI), J1301.41 (VDDI), J1301.42 (VCI), JP1301.1 (A); also elsewhere on the board
/LCD/Backlight_Cathode_1: J1301.2 (LEDK), U1301.4 (LED3), U1301.5 (LED2), U1301.6 (LED1)
/LCD/Backlight_Cathode_2: J1301.3 (LEDK), U1302.4 (LED3), U1302.5 (LED2), U1302.6 (LED1)
/LCD/LCD_IM1: J1301.8 (IM1), JP1301.2 (C)
GND: C1301.1, C1302.1, C1303.1, C1304.1, C1305.1, J1301.35 (RD), J1301.43 (GND), J1301.48 (GND), J1301.49 (GND), J1301.50 (GND), JP1301.3 (B), R1301.2, U1301.2 (GND), U1302.2 (GND); also elsewhere on the board
LCD_BACKLIGHT: R1301.1, U1301.1 (EN), U1302.1 (EN); also elsewhere on the board
LCD_DATA_EN: J1301.14 (DE); also elsewhere on the board
LCD_DB0: J1301.32 (DB0); also elsewhere on the board
LCD_DB1: J1301.31 (DB1); also elsewhere on the board
LCD_DB2: J1301.30 (DB2); also elsewhere on the board
LCD_DB3: J1301.29 (DB3); also elsewhere on the board
LCD_DB4: J1301.28 (DB4); also elsewhere on the board
LCD_DB5: J1301.27 (DB5); also elsewhere on the board
LCD_DB6: J1301.26 (DB6); also elsewhere on the board
LCD_DB7: J1301.25 (DB7); also elsewhere on the board
LCD_DB8: J1301.24 (DB8); also elsewhere on the board
LCD_DB9: J1301.23 (DB9); also elsewhere on the board
LCD_DB10: J1301.22 (DB10); also elsewhere on the board
LCD_DB11: J1301.21 (DB11); also elsewhere on the board
LCD_DB12: J1301.20 (DB12); also elsewhere on the board
LCD_DB13: J1301.19 (DB13); also elsewhere on the board
LCD_DB14: J1301.18 (DB14); also elsewhere on the board
LCD_DB15: J1301.17 (DB15); also elsewhere on the board
LCD_DB16: J1301.16 (DB16); also elsewhere on the board
LCD_DB17: J1301.15 (DB17); also elsewhere on the board
LCD_DOTCLK: J1301.13 (DOTCLK); also elsewhere on the board
LCD_D/~CX: J1301.37 (D/CX); also elsewhere on the board
LCD_HSYNC: J1301.12 (HSYNC); also elsewhere on the board
LCD_SPI_CLK: J1301.36 (WRX(SCL)); also elsewhere on the board
LCD_SPI_PICO: J1301.34 (SDA); also elsewhere on the board
LCD_TE: J1301.39 (TE); also elsewhere on the board
LCD_VSYNC: J1301.11 (VSYNC); also elsewhere on the board
LCD_~CS: J1301.38 (CSX); also elsewhere on the board
LCD_~RST: J1301.10 (RESET); also elsewhere on the board

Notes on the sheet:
SDO unused when SDA_EN = 1 (half-duplex spi)
6 LEDs in parallel V_{f} = 2.9V - 3.2V I_{max} = 120 mA Each AP2502 channel provides 20mA Total of 120mA from the two
Backlight
IM{2, 1, 0} = {1, 1, 1} -> 4-wire, 8-bit SPI
IM{2, 1, 0} = {1, 0, 1} -> 3-wire, 9-bit SPI

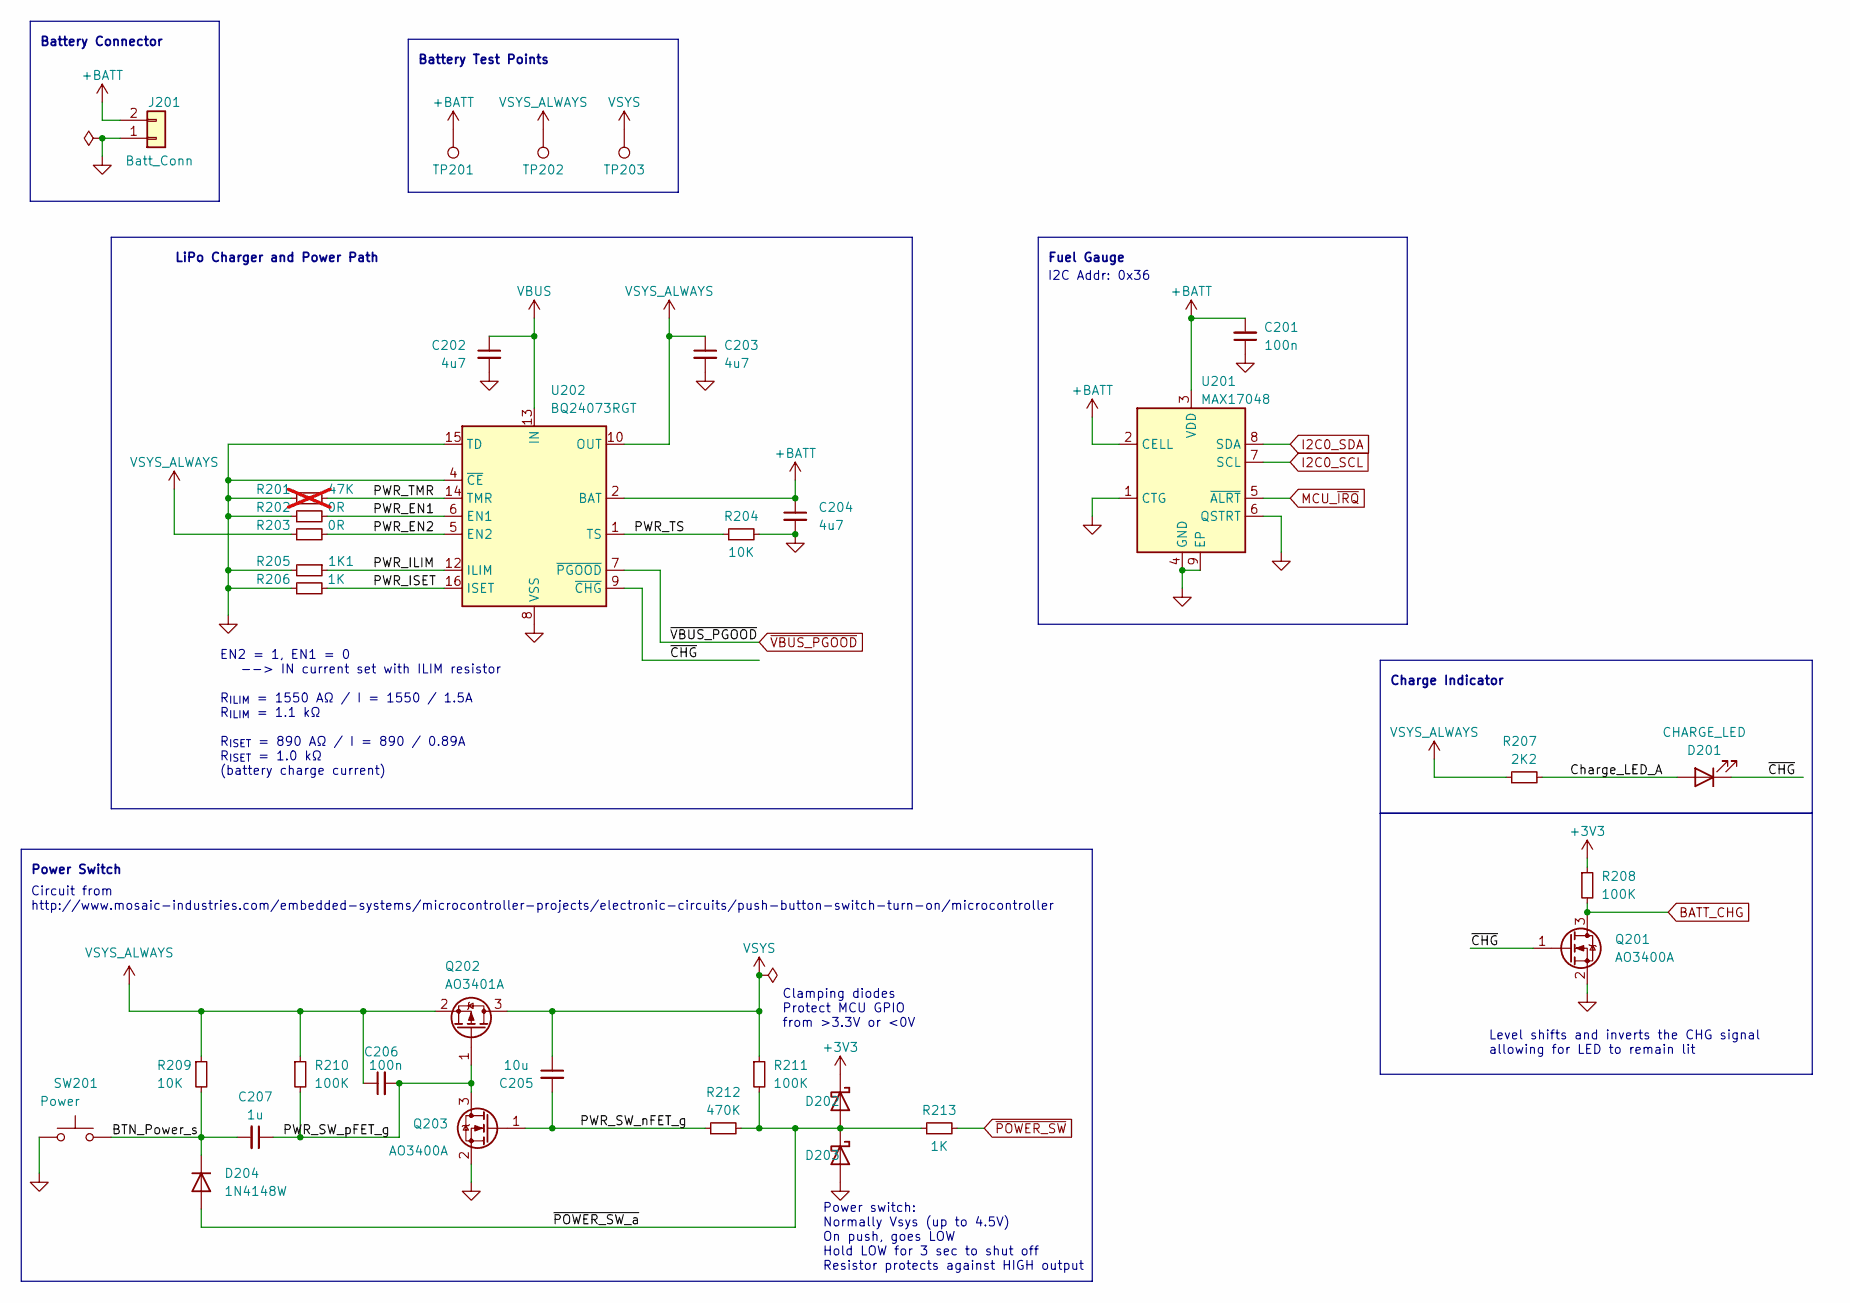
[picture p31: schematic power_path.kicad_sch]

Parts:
C201, C206: 100n; C_0402_1005Metric; LCSC C1525
C202, C203, C204: 4u7; C_0402_1005Metric; LCSC C23733
C205: 10u; C_0402_1005Metric; LCSC C15525
C207: 1u; C_0402_1005Metric; LCSC C52923
D201: CHARGE_LED; LED_0805_2012Metric; LCSC C2296
D202, D203: D_Schottky; D_SOD-323; LCSC C191023
D204: 1N4148W; D_SOD-123; LCSC C81598
J201: Batt_Conn; JST_PH_S2B-PH-SM4-TB_1x02-1MP_P2.00mm_Horizontal
Q201, Q203: AO3400A; SOT-23; LCSC C20917
Q202: AO3401A; SOT-23; LCSC C15127
R201: 47K; R_0402_1005Metric_Pad0.72x0.64mm_HandSolder; LCSC C25792; not fitted
R202, R203: 0R; R_0402_1005Metric_Pad0.72x0.64mm_HandSolder; LCSC C17168
R204, R209: 10K; R_0402_1005Metric; LCSC C25744
R205: 1K1; R_0402_1005Metric_Pad0.72x0.64mm_HandSolder; LCSC C25860
R206: 1K; R_0402_1005Metric_Pad0.72x0.64mm_HandSolder; LCSC C11702
R207: 2K2; R_0402_1005Metric; LCSC C25879
R208, R210, R211: 100K; R_0402_1005Metric; LCSC C25741
R212: 470K; R_0603_1608Metric_Pad0.98x0.95mm_HandSolder; LCSC C23178
R213: 1K; R_0402_1005Metric; LCSC C11702
SW201: Power; SW_SPST_SKSC; LCSC C115361
TP201: +BATT; TestPoint_2.54mm_THT
TP202: VSYS_ALWAYS; TestPoint_2.54mm_THT
TP203: VSYS; TestPoint_2.54mm_THT
U201: MAX17048; TDFN-8-1EP_2x2mm_P0.5mm_EP0.8x1.2mm; LCSC C2682616
U202: BQ24073RGT; VQFN-16-1EP_3x3mm_P0.5mm_EP1.6x1.6mm; LCSC C15220

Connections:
+3V3: D202.1 (K), R208.1; also elsewhere on the board
+BATT: C201.2, C204.1, J201.2, TP201.1, U201.2 (CELL), U201.3 (VDD), U202.2 (BAT), U202.3 (BAT)
/Power Path/BTN_Power_s: C207.2, D204.1 (K), R209.2, SW201.1
/Power Path/Charge_LED_A: D201.2 (A), R207.2
/Power Path/PWR_EN1: R202.2, U202.6 (EN1)
/Power Path/PWR_EN2: R203.2, U202.5 (EN2)
/Power Path/PWR_ILIM: R205.1, U202.12 (ILIM)
/Power Path/PWR_ISET: R206.2, U202.16 (ISET)
/Power Path/PWR_SW_nFET_g: C205.2, Q203.1 (G), R212.1
/Power Path/PWR_SW_pFET_g: C206.2, C207.1, Q202.1 (G), Q203.3 (D), R210.2
/Power Path/PWR_TMR: R201.1, U202.14 (TMR)
/Power Path/PWR_TS: R204.1, U202.1 (TS)
/Power Path/~CHG: D201.1 (K), Q201.1 (G), U202.9 (~CHG)
/Power Path/~POWER_SW_a: D202.2 (A), D203.1 (K), D204.2 (A), R211.2, R212.2, R213.1
BATT_CHG: Q201.3 (D), R208.2; also elsewhere on the board
GND: C201.1, C202.2, C203.2, C204.2, D203.2 (A), J201.1, Q201.2 (S), Q203.2 (S), R201.2, R202.1, R204.2, R205.2, R206.1, SW201.2, U201.1 (CTG), U201.4 (GND), U201.6 (QSTRT), U201.9 (EP), U202.4 (~CE), U202.8 (VSS), U202.15 (TD), U202.17 (VSS); also elsewhere on the board
I2C0_SCL: U201.7 (SCL); also elsewhere on the board
I2C0_SDA: U201.8 (SDA); also elsewhere on the board
MCU_~IRQ: U201.5 (~ALRT); also elsewhere on the board
VBUS: C202.1, U202.13 (IN); also elsewhere on the board
VSYS: C205.1, Q202.3 (D), R211.1, TP203.1; also elsewhere on the board
VSYS_ALWAYS: C203.1, C206.1, Q202.2 (S), R203.1, R207.1, R209.1, R210.1, TP202.1, U202.10 (OUT), U202.11 (OUT); also elsewhere on the board
~POWER_SW: R213.2; also elsewhere on the board
~VBUS_PGOOD: U202.7 (~PGOOD); also elsewhere on the board

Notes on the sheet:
Charge Indicator
Battery Connector
LiPo Charger and Power Path
Power Switch
Level shifts and inverts the CHG signal allowing for LED to remain lit
Battery Test Points
Power switch: Normally Vsys (up to 4.5V) On push, goes LOW Hold LOW for 3 sec to shut off Resistor protects against HIGH output
Clamping diodes Protect MCU GPIO from >3.3V or <0V
Circuit from http://www.mosaic-industries.com/embedded-systems/microcontroller-projects/electronic-circuits/push-button-switch-turn-on/microcontroller
I2C Addr: 0x36
EN2 = 1, EN1 = 0 --> IN current set with ILIM resistor R_{ILIM} = 1550 AΩ / I = 1550 / 1.5A R_{ILIM} = 1.1 kΩ R_{ISET} = 890 AΩ / I = 890 / 0.89A R_{ISET} = 1.0 kΩ (battery charge current)
Fuel Gauge

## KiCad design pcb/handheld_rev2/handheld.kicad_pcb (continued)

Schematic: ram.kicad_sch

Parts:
C1401, C1402, C1403, C1404, C1405, C1406, C1407, C1410, C1411: 100n; C_0402_1005Metric; LCSC C1525
C1408, C1409: 10u; C_0402_1005Metric; LCSC C15525
U1401: W9825G6KH-6; TSOP-II-54_22.2x10.16mm_P0.8mm; LCSC C62246
U1402: IS61WV25616BLL-10TLI; TSOP-II-44_10.16x18.41mm_P0.8mm; LCSC C53825

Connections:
+3V3_FPGA: C1401.2, C1402.2, C1403.2, C1404.2, C1405.2, C1406.2, C1407.2, C1408.1, C1409.1, C1410.2, C1411.2, U1401.1 (VDD), U1401.3 (VDDQ), U1401.9 (VDDQ), U1401.14 (VDD), U1401.27 (VDD), U1401.43 (VDDQ), U1401.49 (VDDQ), U1402.11 (VDD), U1402.33 (VDD); also elsewhere on the board
GND: C1401.1, C1402.1, C1403.1, C1404.1, C1405.1, C1406.1, C1407.1, C1408.2, C1409.2, C1410.1, C1411.1, U1401.6 (VSSQ), U1401.12 (VSSQ), U1401.28 (VSS), U1401.41 (VSS), U1401.46 (VSSQ), U1401.52 (VSSQ), U1401.54 (VSS), U1402.12 (GND), U1402.34 (GND); also elsewhere on the board
SDRAM_0_~CS: U1401.19 (~CS); also elsewhere on the board
SDRAM_A0: U1401.23 (A0); also elsewhere on the board
SDRAM_A1: U1401.24 (A1); also elsewhere on the board
SDRAM_A2: U1401.25 (A2); also elsewhere on the board
SDRAM_A3: U1401.26 (A3); also elsewhere on the board
SDRAM_A4: U1401.29 (A4); also elsewhere on the board
SDRAM_A5: U1401.30 (A5); also elsewhere on the board
SDRAM_A6: U1401.31 (A6); also elsewhere on the board
SDRAM_A7: U1401.32 (A7); also elsewhere on the board
SDRAM_A8: U1401.33 (A8); also elsewhere on the board
SDRAM_A9: U1401.34 (A9); also elsewhere on the board
SDRAM_A10: U1401.22 (A10/AP); also elsewhere on the board
SDRAM_A11: U1401.35 (A11); also elsewhere on the board
SDRAM_A12: U1401.36 (A12); also elsewhere on the board
SDRAM_BS0: U1401.20 (BS0); also elsewhere on the board
SDRAM_BS1: U1401.21 (BS1); also elsewhere on the board
SDRAM_CKE: U1401.37 (CKE); also elsewhere on the board
SDRAM_CLK: U1401.38 (CLK); also elsewhere on the board
SDRAM_DQ0: U1401.2 (DQ0); also elsewhere on the board
SDRAM_DQ1: U1401.4 (DQ1); also elsewhere on the board
SDRAM_DQ2: U1401.5 (DQ2); also elsewhere on the board
SDRAM_DQ3: U1401.7 (DQ3); also elsewhere on the board
SDRAM_DQ4: U1401.8 (DQ4); also elsewhere on the board
SDRAM_DQ5: U1401.10 (DQ5); also elsewhere on the board
SDRAM_DQ6: U1401.11 (DQ6); also elsewhere on the board
SDRAM_DQ7: U1401.13 (DQ7); also elsewhere on the board
SDRAM_DQ8: U1401.42 (DQ8); also elsewhere on the board
SDRAM_DQ9: U1401.44 (DQ9); also elsewhere on the board
SDRAM_DQ10: U1401.45 (DQ10); also elsewhere on the board
SDRAM_DQ11: U1401.47 (DQ11); also elsewhere on the board
SDRAM_DQ12: U1401.48 (DQ12); also elsewhere on the board
SDRAM_DQ13: U1401.50 (DQ13); also elsewhere on the board
SDRAM_DQ14: U1401.51 (DQ14); also elsewhere on the board
SDRAM_DQ15: U1401.53 (DQ15); also elsewhere on the board
SDRAM_LDQM: U1401.15 (LDQM); also elsewhere on the board
SDRAM_UDQM: U1401.39 (UDQM); also elsewhere on the board
SDRAM_~CAS: U1401.17 (~CAS); also elsewhere on the board
SDRAM_~RAS: U1401.18 (~RAS); also elsewhere on the board
SDRAM_~WE: U1401.16 (~WE); also elsewhere on the board
SRAM_A0: U1402.1 (A0); also elsewhere on the board
SRAM_A1: U1402.2 (A1); also elsewhere on the board
SRAM_A2: U1402.3 (A2); also elsewhere on the board
SRAM_A3: U1402.4 (A3); also elsewhere on the board
SRAM_A4: U1402.5 (A4); also elsewhere on the board
SRAM_A5: U1402.18 (A5); also elsewhere on the board
SRAM_A6: U1402.19 (A6); also elsewhere on the board
SRAM_A7: U1402.20 (A7); also elsewhere on the board
SRAM_A8: U1402.21 (A8); also elsewhere on the board
SRAM_A9: U1402.22 (A9); also elsewhere on the board
SRAM_A10: U1402.23 (A10); also elsewhere on the board
SRAM_A11: U1402.24 (A11); also elsewhere on the board
SRAM_A12: U1402.25 (A12); also elsewhere on the board
SRAM_A13: U1402.26 (A13); also elsewhere on the board
SRAM_A14: U1402.27 (A14); also elsewhere on the board
SRAM_A15: U1402.42 (A15); also elsewhere on the board
SRAM_A16: U1402.43 (A16); also elsewhere on the board
SRAM_A17: U1402.44 (A17); also elsewhere on the board
SRAM_IO0: U1402.7 (IO0); also elsewhere on the board
SRAM_IO1: U1402.8 (IO1); also elsewhere on the board
SRAM_IO2: U1402.9 (IO2); also elsewhere on the board
SRAM_IO3: U1402.10 (IO3); also elsewhere on the board
SRAM_IO4: U1402.13 (IO4); also elsewhere on the board
SRAM_IO5: U1402.14 (IO5); also elsewhere on the board
SRAM_IO6: U1402.15 (IO6); also elsewhere on the board
SRAM_IO7: U1402.16 (IO7); also elsewhere on the board
SRAM_IO8: U1402.29 (IO8); also elsewhere on the board
SRAM_IO9: U1402.30 (IO9); also elsewhere on the board
SRAM_IO10: U1402.31 (IO10); also elsewhere on the board
SRAM_IO11: U1402.32 (IO11); also elsewhere on the board
SRAM_IO12: U1402.35 (IO12); also elsewhere on the board
SRAM_IO13: U1402.36 (IO13); also elsewhere on the board
SRAM_IO14: U1402.37 (IO14); also elsewhere on the board
SRAM_IO15: U1402.38 (IO15); also elsewhere on the board
SRAM_~CE: U1402.6 (~CE); also elsewhere on the board
SRAM_~LB: U1402.39 (~LB); also elsewhere on the board
SRAM_~OE: U1402.41 (~OE); also elsewhere on the board
SRAM_~UB: U1402.40 (~UB); also elsewhere on the board
SRAM_~WE: U1402.17 (~WE); also elsewhere on the board

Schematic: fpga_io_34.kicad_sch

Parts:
C1101, C1102, C1103, C1104: 470n; C_0402_1005Metric; LCSC C47339
C1105, C1106: 4u7; C_0402_1005Metric; LCSC C23733
U601: XC7A100T-CSG324; Xilinx_CSG324; LCSC C1521791

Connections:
+3V3_FPGA: C1101.1, C1102.1, C1103.1, C1104.1, C1105.1, C1106.1, U601.K4 (VCCO_34), U601.N3 (VCCO_34), U601.P6 (VCCO_34), U601.T2 (VCCO_34), U601.U5 (VCCO_34), U601.V8 (VCCO_34); also elsewhere on the board
BTN_A: U601.N5 (IO_L13P_T2_MRCC_34); also elsewhere on the board
BTN_B: U601.P5 (IO_L13N_T2_MRCC_34); also elsewhere on the board
BTN_R: U601.L5 (IO_L6N_T0_VREF_34); also elsewhere on the board
BTN_Start: U601.K5 (IO_L5P_T0_34); also elsewhere on the board
BTN_X: U601.L6 (IO_L6P_T0_34); also elsewhere on the board
BTN_Y: U601.M6 (IO_L18P_T2_34); also elsewhere on the board
GND: C1101.2, C1102.2, C1103.2, C1104.2, C1105.2, C1106.2; also elsewhere on the board
SDRAM_0_~CS: U601.V1 (IO_L7N_T1_34); also elsewhere on the board
SDRAM_A0: U601.R3 (IO_L11P_T1_SRCC_34); also elsewhere on the board
SDRAM_A1: U601.T3 (IO_L11N_T1_SRCC_34); also elsewhere on the board
SDRAM_A2: U601.T4 (IO_L12N_T1_MRCC_34); also elsewhere on the board
SDRAM_A3: U601.R5 (IO_L19N_T3_VREF_34); also elsewhere on the board
SDRAM_A4: U601.R6 (IO_L19P_T3_34); also elsewhere on the board
SDRAM_A5: U601.T6 (IO_L23N_T3_34); also elsewhere on the board
SDRAM_A6: U601.R7 (IO_L23P_T3_34); also elsewhere on the board
SDRAM_A7: U601.R8 (IO_L24P_T3_34); also elsewhere on the board
SDRAM_A8: U601.T8 (IO_L24N_T3_34); also elsewhere on the board
SDRAM_A9: U601.U2 (IO_L9P_T1_DQS_34); also elsewhere on the board
SDRAM_A10: U601.P4 (IO_L14P_T2_SRCC_34); also elsewhere on the board
SDRAM_A11: U601.V2 (IO_L9N_T1_DQS_34); also elsewhere on the board
SDRAM_A12: U601.U3 (IO_L8N_T1_34); also elsewhere on the board
SDRAM_BS0: U601.N4 (IO_L16N_T2_34); also elsewhere on the board
SDRAM_BS1: U601.P3 (IO_L14N_T2_SRCC_34); also elsewhere on the board
SDRAM_CKE: U601.U4 (IO_L8P_T1_34); also elsewhere on the board
SDRAM_CLK: U601.V4 (IO_L10N_T1_34); also elsewhere on the board
SDRAM_DQ0: U601.P2 (IO_L15P_T2_DQS_34); also elsewhere on the board
SDRAM_DQ1: U601.N2 (IO_L3P_T0_DQS_34); also elsewhere on the board
SDRAM_DQ2: U601.N1 (IO_L3N_T0_DQS_34); also elsewhere on the board
SDRAM_DQ3: U601.M2 (IO_L4N_T0_34); also elsewhere on the board
SDRAM_DQ4: U601.M1 (IO_L1N_T0_34); also elsewhere on the board
SDRAM_DQ5: U601.L1 (IO_L1P_T0_34); also elsewhere on the board
SDRAM_DQ6: U601.M3 (IO_L4P_T0_34); also elsewhere on the board
SDRAM_DQ7: U601.M4 (IO_L16P_T2_34); also elsewhere on the board
SDRAM_DQ8: U601.V5 (IO_L10P_T1_34); also elsewhere on the board
SDRAM_DQ9: U601.U6 (IO_L22N_T3_34); also elsewhere on the board
SDRAM_DQ10: U601.V6 (IO_L20N_T3_34); also elsewhere on the board
SDRAM_DQ11: U601.U7 (IO_L22P_T3_34); also elsewhere on the board
SDRAM_DQ12: U601.V7 (IO_L20P_T3_34); also elsewhere on the board
SDRAM_DQ13: U601.U8 (IO_25_34); also elsewhere on the board
SDRAM_DQ14: U601.U9 (IO_L21P_T3_DQS_34); also elsewhere on the board
SDRAM_DQ15: U601.V9 (IO_L21N_T3_DQS_34); also elsewhere on the board
SDRAM_LDQM: U601.R1 (IO_L17P_T2_34); also elsewhere on the board
SDRAM_UDQM: U601.T5 (IO_L12P_T1_MRCC_34); also elsewhere on the board
SDRAM_~CAS: U601.T1 (IO_L17N_T2_34); also elsewhere on the board
SDRAM_~RAS: U601.U1 (IO_L7P_T1_34); also elsewhere on the board
SDRAM_~WE: U601.R2 (IO_L15N_T2_DQS_34); also elsewhere on the board

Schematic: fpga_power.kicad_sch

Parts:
C601, C602, C603, C604, C619: 100u; C_1206_3216Metric; LCSC C15008
C605, C606, C607, C608, C609, C610, C623, C624: 4u7; C_0402_1005Metric; LCSC C23733
C611, C612, C613, C614, C615, C616, C617, C618, C620, C621, C625, C626, C627, C628: 470n; C_0402_1005Metric; LCSC C47339
C622, C629: 47u; C_0805_2012Metric; LCSC C16780
U601: XC7A100T-CSG324; Xilinx_CSG324; LCSC C1521791

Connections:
+1V0: C601.1, C602.1, C603.1, C604.1, C605.1, C606.1, C607.1, C608.1, C609.1, C610.1, C611.1, C612.1, C613.1, C614.1, C615.1, C616.1, C617.1, C618.1, C619.1, C620.1, C621.1, U601.F8 (VCCINT), U601.F10 (VCCBRAM), U601.G7 (VCCINT), U601.G9 (VCCINT), U601.G11 (VCCBRAM), U601.H8 (VCCINT), U601.J7 (VCCINT), U601.J11 (VCCINT), U601.K8 (VCCINT), U601.L7 (VCCINT), U601.L11 (VCCINT), U601.M8 (VCCINT), U601.M10 (VCCINT), U601.N7 (VCCINT), U601.N9 (VCCINT), U601.N11 (VCCINT); also elsewhere on the board
+1V8: C622.1, C623.1, C624.1, C625.1, C626.1, C627.1, C628.1, U601.F12 (VCCAUX), U601.H10 (VCCADC_0), U601.H12 (VCCAUX), U601.K12 (VCCAUX), U601.M12 (VCCAUX); also elsewhere on the board
+3V3_FPGA: C629.1; also elsewhere on the board
GND: C601.2, C602.2, C603.2, C604.2, C605.2, C606.2, C607.2, C608.2, C609.2, C610.2, C611.2, C612.2, C613.2, C614.2, C615.2, C616.2, C617.2, C618.2, C619.2, C620.2, C621.2, C622.2, C623.2, C624.2, C625.2, C626.2, C627.2, C628.2, C629.2, U601.A2 (GND), U601.A12 (GND), U601.B5 (GND), U601.B15 (GND), U601.C8 (GND), U601.C18 (GND), U601.D1 (GND), U601.D11 (GND), U601.E4 (GND), U601.E8 (VCCBATT_0), U601.E14 (GND), U601.F7 (GND), U601.F9 (GND), U601.F11 (GND), U601.F17 (GND), U601.G8 (GND), U601.G10 (GND), U601.G12 (GND), U601.H3 (GND), U601.H7 (GND), U601.H9 (GNDADC_0), U601.H11 (GND), U601.H13 (GND), U601.J6 (GND), U601.J8 (GND), U601.J12 (GND), U601.J16 (GND), U601.K7 (GND), U601.K11 (GND), U601.L2 (GND), U601.L8 (GND), U601.L12 (GND), U601.M5 (GND), U601.M7 (GND), U601.M9 (GND), U601.M11 (GND), U601.M15 (GND), U601.N8 (GND), U601.N10 (GND), U601.N12 (GND), U601.N18 (GND), U601.P1 (GND), U601.R4 (GND), U601.R14 (GND), U601.T7 (GND), U601.T17 (GND), U601.U10 (GND), U601.V3 (GND), U601.V13 (GND); also elsewhere on the board

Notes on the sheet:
Consider adding ferrite bead to GNDADC
Bulk decoupling capacitor shared between 4x IO banks sharing same VCCO (3.3V)

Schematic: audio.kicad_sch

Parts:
C1701, C1703, C1709, C1711: 10u; C_0402_1005Metric; LCSC C15525
C1702, C1704, C1706, C1708, C1710, C1712: 100n; C_0402_1005Metric; LCSC C1525
C1705, C1707: 22u; C_0805_2012Metric; LCSC C45783
C1713, C1714: 100u; C_1206_3216Metric; LCSC C15008
J1701: SPK_L; Speaker_Same_Sky_CMS-160903-18S-X8
J1702: SPK_R; Speaker_Same_Sky_CMS-160903-18S-X8
J1703: Headphone Jack; Jack_3.5mm_CUI_SJ-43614-SMT
Q1701: AO3400A; SOT-23; LCSC C20917
R1701: 100K; R_0402_1005Metric; LCSC C25741
R1702: 1K; R_0402_1005Metric; LCSC C11702
R1703: 2K2; R_0402_1005Metric; LCSC C25879
R1704: 10K; R_0402_1005Metric; LCSC C25744
U1701: TLV320DAC3101; VQFN-32-1EP_5x5mm_P0.5mm_EP3.5x3.5mm; LCSC C2651664

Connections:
+1V8: C1709.1, C1710.2, U1701.3 (DVDD); also elsewhere on the board
+3V3: C1701.1, C1702.2, C1703.1, C1704.2, C1711.1, C1712.2, U1701.2 (IOVDD), U1701.17 (AVDD), U1701.28 (HPVDD); also elsewhere on the board
/Audio/DAC_INT: R1702.2, R1704.1, U1701.32 (GPIO1)
/Audio/DAC_INT_R: Q1701.1 (G), R1702.1
/Audio/HeadphoneJack_Tip: C1714.2, J1703.T
/Audio/Headphone_Jack_R: C1713.2, J1703.R1
/Audio/Headphone_Left: C1714.1, U1701.27 (HPL)
/Audio/Headphone_Mic: J1703.S, R1703.2, U1701.11 (VOL/MICDET)
/Audio/Headphone_Right: C1713.1, U1701.30 (HPR)
/Audio/MICBIAS: R1703.1, U1701.12 (MICBIAS)
/Audio/Speaker_Left_M: J1701.1, U1701.19 (SPLM)
/Audio/Speaker_Left_P: J1701.2, U1701.22 (SPLP)
/Audio/Speaker_Right_M: J1702.1, U1701.23 (SPRM)
/Audio/Speaker_Right_P: J1702.2, U1701.26 (SPRP)
DAC_BCLK: U1701.7 (BCLK); also elsewhere on the board
DAC_DIN: U1701.5 (DIN); also elsewhere on the board
DAC_MCLK: U1701.8 (MCLK); also elsewhere on the board
DAC_WCLK: U1701.6 (WCLK); also elsewhere on the board
DAC_~RESET: R1701.1, U1701.31 (~RESET); also elsewhere on the board
GND: C1701.2, C1702.1, C1703.2, C1704.1, C1705.2, C1706.1, C1707.2, C1708.1, C1709.2, C1710.1, C1711.2, C1712.1, J1703.R2, Q1701.2 (S), R1701.2, R1704.2, U1701.1 (IOVSS), U1701.16 (AVSS), U1701.18 (DVSS), U1701.20 (SPLVSS), U1701.25 (SPRVSS), U1701.29 (HPVSS), U1701.33 (EP); also elsewhere on the board
I2C0_SCL: U1701.10 (SCL); also elsewhere on the board
I2C0_SDA: U1701.9 (SDA); also elsewhere on the board
MCU_~IRQ: Q1701.3 (D); also elsewhere on the board
VSYS: C1705.1, C1706.2, C1707.1, C1708.2, U1701.21 (SPLVDD), U1701.24 (SPRVDD); also elsewhere on the board

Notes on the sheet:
CTIA (Apple) style Tip is Left R1 is Right R2 is GND Sleeve is Mic
Headphone Jack
nFET converts push-pull active-high DAC interrupt into open-drain active-low MCU_~{INT}
CMS-160903-18S-X8
Speaker
I2C Addr: 0x18

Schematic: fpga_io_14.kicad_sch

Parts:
C801, C802, C803, C804: 470n; C_0402_1005Metric; LCSC C47339
C805, C806: 4u7; C_0402_1005Metric; LCSC C23733
D801: H5VU25U; Diodes_UDFN-10_1.0x2.5mm_P0.5mm; LCSC C7420374
J801: PMOD; PinSocket_1x06_P2.54mm_Horizontal_SMD
R801: 1K; R_0402_1005Metric; LCSC C11702
U601: XC7A100T-CSG324; Xilinx_CSG324; LCSC C1521791

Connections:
+3V3_FPGA: C801.1, C802.1, C803.1, C804.1, C805.1, C806.1, J801.1, R801.2, U601.L17 (VCCO_14), U601.N13 (VCCO_14), U601.P16 (VCCO_14), U601.T12 (VCCO_14), U601.U15 (VCCO_14), U601.V18 (VCCO_14); also elsewhere on the board
/FPGA IO Bank 14/FPGA_PUDC_B: R801.1, U601.L15 (IO_L3P_T0_DQS_PUDC_B_14)
/FPGA IO Bank 14/PMOD_1: D801.5 (K4), D801.6 (K4), J801.6, U601.M14 (IO_L2N_T0_D03_14)
/FPGA IO Bank 14/PMOD_2: D801.4 (K3), D801.7 (K3), J801.5, U601.N14 (IO_L8P_T1_D11_14)
/FPGA IO Bank 14/PMOD_3: D801.2 (K2), D801.9 (K2), J801.4, U601.P14 (IO_L8N_T1_D12_14)
/FPGA IO Bank 14/PMOD_4: D801.1 (K1), D801.10 (K1), J801.3, U601.M13 (IO_L6N_T0_D08_VREF_14)
FPGA_SPI_D0: U601.K18 (IO_L1N_T0_D01_DIN_14); also elsewhere on the board
GB_Cart_VIN: U601.L13 (IO_L6P_T0_FCS_B_14); also elsewhere on the board
GB_Dir_VIN: U601.L14 (IO_L2P_T0_D02_14); also elsewhere on the board
GND: C801.2, C802.2, C803.2, C804.2, C805.2, C806.2, D801.3 (A), D801.8 (A), J801.2; also elsewhere on the board
LCD_DB10: U601.L18 (IO_L4P_T0_D04_14); also elsewhere on the board
LCD_DB11: U601.K17 (IO_L1P_T0_D00_MOSI_14); also elsewhere on the board
LCD_TE: U601.T11 (IO_L19P_T3_A10_D26_14); also elsewhere on the board
SRAM_A0: U601.N17 (IO_L9P_T1_DQS_14); also elsewhere on the board
SRAM_A1: U601.M17 (IO_L10N_T1_D15_14); also elsewhere on the board
SRAM_A2: U601.M18 (IO_L4N_T0_D05_14); also elsewhere on the board
SRAM_A3: U601.T9 (IO_L24P_T3_A01_D17_14); also elsewhere on the board
SRAM_A4: U601.T10 (IO_L24N_T3_A00_D16_14); also elsewhere on the board
SRAM_A5: U601.P15 (IO_L13P_T2_MRCC_14); also elsewhere on the board
SRAM_A6: U601.N16 (IO_L11N_T1_SRCC_14); also elsewhere on the board
SRAM_A7: U601.N15 (IO_L11P_T1_SRCC_14); also elsewhere on the board
SRAM_A8: U601.M16 (IO_L10P_T1_D14_14); also elsewhere on the board
SRAM_A9: U601.L16 (IO_L3N_T0_DQS_EMCCLK_14); also elsewhere on the board
SRAM_A10: U601.V12 (IO_L20N_T3_A07_D23_14); also elsewhere on the board
SRAM_A11: U601.U11 (IO_L19N_T3_A09_D25_VREF_14); also elsewhere on the board
SRAM_A12: U601.V11 (IO_L21N_T3_DQS_A06_D22_14); also elsewhere on the board
SRAM_A13: U601.V10 (IO_L21P_T3_DQS_14); also elsewhere on the board
SRAM_A14: U601.U12 (IO_L20P_T3_A08_D24_14); also elsewhere on the board
SRAM_A15: U601.R18 (IO_L7P_T1_D09_14); also elsewhere on the board
SRAM_A16: U601.P17 (IO_L12P_T1_MRCC_14); also elsewhere on the board
SRAM_A17: U601.P18 (IO_L9N_T1_DQS_D13_14); also elsewhere on the board
SRAM_IO0: U601.R11 (IO_0_14); also elsewhere on the board
SRAM_IO1: U601.R12 (IO_L5P_T0_D06_14); also elsewhere on the board
SRAM_IO2: U601.T13 (IO_L23P_T3_A03_D19_14); also elsewhere on the board
SRAM_IO3: U601.R13 (IO_L5N_T0_D07_14); also elsewhere on the board
SRAM_IO4: U601.T14 (IO_L14P_T2_SRCC_14); also elsewhere on the board
SRAM_IO5: U601.T15 (IO_L14N_T2_SRCC_14); also elsewhere on the board
SRAM_IO6: U601.T16 (IO_L15N_T2_DQS_DOUT_CSO_B_14); also elsewhere on the board
SRAM_IO7: U601.R16 (IO_L15P_T2_DQS_RDWR_B_14); also elsewhere on the board
SRAM_IO8: U601.U13 (IO_L23N_T3_A02_D18_14); also elsewhere on the board
SRAM_IO9: U601.V14 (IO_L22N_T3_A04_D20_14); also elsewhere on the board
SRAM_IO10: U601.U14 (IO_L22P_T3_A05_D21_14); also elsewhere on the board
SRAM_IO11: U601.V15 (IO_L16P_T2_CSI_B_14); also elsewhere on the board
SRAM_IO12: U601.V16 (IO_L16N_T2_A15_D31_14); also elsewhere on the board
SRAM_IO13: U601.U16 (IO_L18P_T2_A12_D28_14); also elsewhere on the board
SRAM_IO14: U601.V17 (IO_L18N_T2_A11_D27_14); also elsewhere on the board
SRAM_IO15: U601.U18 (IO_L17N_T2_A13_D29_14); also elsewhere on the board
SRAM_~CE: U601.R10 (IO_25_14); also elsewhere on the board
SRAM_~LB: U601.U17 (IO_L17P_T2_A14_D30_14); also elsewhere on the board
SRAM_~OE: U601.R17 (IO_L12N_T1_MRCC_14); also elsewhere on the board
SRAM_~UB: U601.T18 (IO_L7N_T1_D10_14); also elsewhere on the board
SRAM_~WE: U601.R15 (IO_L13N_T2_MRCC_14); also elsewhere on the board

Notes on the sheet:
PMOD
PUDC_B high disables pull-ups during boot

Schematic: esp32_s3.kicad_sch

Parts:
C401, C403: 100n; C_0402_1005Metric; LCSC C1525
C402: 22u; C_0805_2012Metric; LCSC C45783
D401: STATUS_LED; LED_0805_2012Metric; LCSC C2297
J401: TP_I2C; PinSocket_1x04_P2.54mm_Vertical; not fitted
J402: Micro_SD_Card_Det1; microSD_G-Switch_GT-TF003-H0185-02; LCSC C5155564
Q401: AO3400A; SOT-23; LCSC C20917
R401, R403, R420, R421, R422, R423, R424, R425, R426, R427: 10K; R_0402_1005Metric; LCSC C25744
R402, R406, R408, R409, R410, R411, R413, R414, R415, R416, R417, R418, R419: 0R; R_0402_1005Metric_Pad0.72x0.64mm_HandSolder; LCSC C17168
R404, R405: 3K3; R_0402_1005Metric_Pad0.72x0.64mm_HandSolder; LCSC C25890
R407: 2K2; R_0402_1005Metric; LCSC C25879
R412: 100K; R_0402_1005Metric; LCSC C25741
TP401, TP402: FPGA_SPI_~{CS}; TestPoint_Pad_D1.0mm
U401: ESP32-S3-MINI-1-N8; ESP32-S3-MINI-1; LCSC C2913206

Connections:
+3V3: C401.2, C402.1, C403.2, J402.4 (VDD), R401.1, R403.1, R404.1, R405.1, R407.1, R412.1, R420.1, R421.1, R422.1, R423.1, R424.1, R425.1, R426.2, U401.3 (3V3); also elsewhere on the board
+3V3_PG: R401.2, U401.45 (EN); also elsewhere on the board
/ESP32-S3/ESP32_RX: TP402.1, U401.40 (U0RXD/GPIO44)
/ESP32-S3/ESP32_SDIO_CLK: R416.2, U401.28 (GPIO33)
/ESP32-S3/ESP32_SDIO_CMD: R418.1, U401.27 (GPIO47)
/ESP32-S3/ESP32_SDIO_D0: R417.2, U401.29 (GPIO34)
/ESP32-S3/ESP32_SDIO_D1: R419.1, U401.30 (GPIO48)
/ESP32-S3/ESP32_SDIO_D2: R415.1, U401.25 (GPIO21)
/ESP32-S3/ESP32_SDIO_D3: R414.2, U401.26 (GPIO26)
/ESP32-S3/ESP32_SPI2_CLK: R410.1, U401.16 (GPIO12)
/ESP32-S3/ESP32_SPI2_D0: R409.1, U401.15 (GPIO11)
/ESP32-S3/ESP32_SPI2_D1: R411.1, U401.17 (GPIO13)
/ESP32-S3/ESP32_SPI2_D2: R413.1, U401.18 (GPIO14)
/ESP32-S3/ESP32_SPI2_D3: R408.1, U401.13 (GPIO9)
/ESP32-S3/ESP32_TX: TP401.1, U401.39 (U0TXD/GPIO43)
/ESP32-S3/ESP32_USB_D+: R402.1, U401.24 (GPIO20/USB_D+)
/ESP32-S3/ESP32_USB_D-: R406.1, U401.23 (GPIO19/USB_D-)
/ESP32-S3/SDIO_CLK: J402.5 (CLK), R416.1, R423.2
/ESP32-S3/SDIO_CMD: J402.3 (CMD), R418.2, R422.2
/ESP32-S3/SDIO_D0: J402.7 (DAT0), R417.1, R424.2
/ESP32-S3/SDIO_D1: J402.8 (DAT1), R419.2, R425.2
/ESP32-S3/SDIO_D2: J402.1 (DAT2), R415.2, R420.2
/ESP32-S3/SDIO_D3/~CS: J402.2 (DAT3/CD), R414.1, R421.2
/ESP32-S3/SD_Detect: R427.2, U401.31 (GPIO35)
/ESP32-S3/SD_Detect_s: J402.9 (DET), R426.1, R427.1
/ESP32-S3/STATUS_LED: Q401.1 (G), R412.2, U401.32 (GPIO36)
/ESP32-S3/Status_LED_A: D401.2 (A), R407.2
/ESP32-S3/Status_LED_K: D401.1 (K), Q401.3 (D)
BATT_CHG: U401.35 (GPIO39/MTCK); also elsewhere on the board
BTN_Home: U401.4 (GPIO0/BOOT); also elsewhere on the board
BTN_VOL_DOWN: U401.36 (GPIO40/MTDO); also elsewhere on the board
BTN_VOL_UP: U401.37 (GPIO41/MTDI); also elsewhere on the board
DAC_~RESET: U401.41 (GPIO45); also elsewhere on the board
FPGA_DONE: U401.10 (GPIO6); also elsewhere on the board
FPGA_INIT_B: U401.12 (GPIO8); also elsewhere on the board
FPGA_POWER_EN: U401.44 (GPIO46); also elsewhere on the board
FPGA_PROGRAM_B: U401.11 (GPIO7); also elsewhere on the board
FPGA_SPI_CLK: R410.2; also elsewhere on the board
FPGA_SPI_D0: R409.2; also elsewhere on the board
FPGA_SPI_D1: R411.2; also elsewhere on the board
FPGA_SPI_D2: R413.2; also elsewhere on the board
FPGA_SPI_D3: R408.2; also elsewhere on the board
FPGA_SPI_~CS: U401.14 (GPIO10); also elsewhere on the board
GND: C401.1, C402.2, C403.1, J401.4, J402.6 (VSS), J402.10 (SHIELD), Q401.2 (S), U401.1 (GND), U401.2 (GND), U401.42 (GND), U401.43 (GND), U401.46 (GND), U401.47 (GND), U401.48 (GND), U401.49 (GND), U401.50 (GND), U401.51 (GND), U401.52 (GND), U401.53 (GND), U401.54 (GND), U401.55 (GND), U401.56 (GND), U401.57 (GND), U401.58 (GND), U401.59 (GND), U401.60 (GND), U401.61 (GND), U401.62 (GND), U401.63 (GND), U401.64 (GND), U401.65 (GND); also elsewhere on the board
I2C0_SCL: J401.2, R404.2, U401.33 (GPIO37); also elsewhere on the board
I2C0_SDA: J401.3, R405.2, U401.34 (GPIO38); also elsewhere on the board
LCD_BACKLIGHT: U401.38 (GPIO42/MTMS); also elsewhere on the board
LCD_D/~CX: U401.7 (GPIO3); also elsewhere on the board
LCD_SPI_CLK: U401.8 (GPIO4); also elsewhere on the board
LCD_SPI_PICO: U401.9 (GPIO5); also elsewhere on the board
LCD_~CS: U401.6 (GPIO2); also elsewhere on the board
LCD_~RST: U401.5 (GPIO1); also elsewhere on the board
MCU_~IRQ: J401.1, R403.2, U401.20 (GPIO16); also elsewhere on the board
USB_D+: R402.2; also elsewhere on the board
USB_D-: R406.2; also elsewhere on the board
~POWER_SW: U401.19 (GPIO15); also elsewhere on the board
~VBUS_PGOOD: U401.21 (GPIO17); also elsewhere on the board

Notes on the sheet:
ESP32-S3 ~{IRQ} is open-drain
Power / Status LED
microSD Slot

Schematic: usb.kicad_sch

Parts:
D501, D502, D503: H5VU25U; Diodes_UDFN-10_1.0x2.5mm_P0.5mm; LCSC C7420374
J501: USB_C_Receptacle_USB2.0; USB-C-SMD_TYPE-C-24P-QT; LCSC C2681555
R501, R502: 5K1; R_0402_1005Metric; LCSC C25905

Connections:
/USB/USB_CC1: J501.A5 (CC1), R501.1
/USB/USB_CC2: J501.B5 (CC2), R502.1
GND: D501.3 (A), D501.8 (A), D502.3 (A), D502.8 (A), D503.3 (A), D503.8 (A), J501.A1 (GND), J501.A12 (GND), J501.B1 (GND), J501.B12 (GND), J501.S1 (SHIELD), R501.2, R502.2; also elsewhere on the board
HDMI_CLK+: D503.4 (K3), D503.7 (K3), J501.A10 (RX2-); also elsewhere on the board
HDMI_CLK-: D503.5 (K4), D503.6 (K4), J501.A11 (RX2+); also elsewhere on the board
HDMI_D0+: D502.2 (K2), D502.9 (K2), J501.B3 (TX2-); also elsewhere on the board
HDMI_D0-: D502.1 (K1), D502.10 (K1), J501.B2 (TX2+); also elsewhere on the board
HDMI_D1+: D503.1 (K1), D503.10 (K1), J501.A2 (TX1+); also elsewhere on the board
HDMI_D1-: D503.2 (K2), D503.9 (K2), J501.A3 (TX1-); also elsewhere on the board
HDMI_D2+: D502.5 (K4), D502.6 (K4), J501.B11 (RX1+); also elsewhere on the board
HDMI_D2-: D502.4 (K3), D502.7 (K3), J501.B10 (RX1-); also elsewhere on the board
USB_D+: D501.2 (K2), D501.9 (K2), J501.A6 (D+), J501.B6 (D+); also elsewhere on the board
USB_D-: D501.4 (K3), D501.7 (K3), J501.A7 (D-), J501.B7 (D-); also elsewhere on the board
USB_SBU1: D501.5 (K4), D501.6 (K4), J501.A8 (SBU1); also elsewhere on the board
USB_SBU2: D501.1 (K1), D501.10 (K1), J501.B8 (SBU2); also elsewhere on the board
VBUS: J501.A4 (VBUS), J501.A9 (VBUS), J501.B4 (VBUS), J501.B9 (VBUS); also elsewhere on the board

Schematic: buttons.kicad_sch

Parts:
C1601: 100n; C_0402_1005Metric; LCSC C1525
R1601, R1602, R1603, R1604, R1605, R1606, R1607, R1608, R1609, R1610, R1611, R1612, R1613, R1614, R1615, R1616, R1617, R1618, R1619, R1620, R1621, R1622, R1623, R1624, R1625, R1626, R1627, R1628, R1629, R1630: 10K; R_0402_1005Metric; LCSC C25744
SW1601: Up; SW_SPST_SKRR; LCSC C97437
SW1602: X; SW_SPST_SKRR; LCSC C97437
SW1603: Left; SW_SPST_SKRR; LCSC C97437
SW1604: Right; SW_SPST_SKRR; LCSC C97437
SW1605: Y; SW_SPST_SKRR; LCSC C97437
SW1606: A; SW_SPST_SKRR; LCSC C97437
SW1607: Down; SW_SPST_SKRR; LCSC C97437
SW1608: B; SW_SPST_SKRR; LCSC C97437
SW1609: Select; SW_SPST_SKRB; LCSC C115356
SW1610: Home; SW_SPST_SKRB; LCSC C115356
SW1611: Start; SW_SPST_SKRB; LCSC C115356
SW1612: L; SW_Tactile_SPST_PTS645Vxx13SMT
SW1613: R; SW_Tactile_SPST_PTS645Vxx13SMT
SW1614: Vol_Up; SW_SPST_SKSC; LCSC C115361
SW1615: Vol_Down; SW_SPST_SKSC; LCSC C115361
U1601: TCA9535PWR; TSSOP-24_4.4x7.8mm_P0.65mm; LCSC C130204

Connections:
+3V3: C1601.1, R1601.1, R1602.1, R1605.1, R1606.1, R1607.1, R1608.1, R1613.1, R1614.1, R1617.1, R1618.1, R1619.1, R1623.1, R1625.1, R1626.1, R1629.1, U1601.24 (VCC); also elsewhere on the board
/Buttons/BTN_A_s: R1608.2, R1612.2, SW1606.1
/Buttons/BTN_B_s: R1614.2, R1616.2, SW1608.1
/Buttons/BTN_Down_s: R1613.2, R1615.2, SW1607.1
/Buttons/BTN_Home_s: R1618.2, R1621.2, SW1610.1
/Buttons/BTN_L_s: R1623.2, R1624.2, SW1612.1
/Buttons/BTN_Left_s: R1605.2, R1609.2, SW1603.1
/Buttons/BTN_R_s: R1625.2, R1627.2, SW1613.1
/Buttons/BTN_Right_s: R1606.2, R1610.2, SW1604.1
/Buttons/BTN_Select_s: R1617.2, R1620.2, SW1609.1
/Buttons/BTN_Start_s: R1619.2, R1622.2, SW1611.1
/Buttons/BTN_Up_s: R1601.2, R1603.2, SW1601.1
/Buttons/BTN_Vol_Down_s: R1629.2, R1630.2, SW1615.1
/Buttons/BTN_Vol_Up_s: R1626.2, R1628.2, SW1614.1
/Buttons/BTN_X_s: R1602.2, R1604.2, SW1602.1
/Buttons/BTN_Y_s: R1607.2, R1611.2, SW1605.1
BTN_A: R1612.1, U1601.7 (P03); also elsewhere on the board
BTN_B: R1616.1, U1601.8 (P04); also elsewhere on the board
BTN_Down: R1615.1, U1601.18 (P15); also elsewhere on the board
BTN_Home: R1621.1; also elsewhere on the board
BTN_L: R1624.1, U1601.14 (P11); also elsewhere on the board
BTN_Left: R1609.1, U1601.17 (P14); also elsewhere on the board
BTN_R: R1627.1, U1601.4 (P00); also elsewhere on the board
BTN_Right: R1610.1, U1601.16 (P13); also elsewhere on the board
BTN_Select: R1620.1, U1601.19 (P16); also elsewhere on the board
BTN_Start: R1622.1, U1601.20 (P17); also elsewhere on the board
BTN_Up: R1603.1, U1601.15 (P12); also elsewhere on the board
BTN_VOL_DOWN: R1630.1; also elsewhere on the board
BTN_VOL_UP: R1628.1; also elsewhere on the board
BTN_X: R1604.1, U1601.5 (P01); also elsewhere on the board
BTN_Y: R1611.1, U1601.6 (P02); also elsewhere on the board
GND: C1601.2, SW1601.2, SW1602.2, SW1603.2, SW1604.2, SW1605.2, SW1606.2, SW1607.2, SW1608.2, SW1609.2, SW1610.2, SW1611.2, SW1612.2, SW1613.2, SW1614.2, SW1615.2, U1601.2 (A1), U1601.3 (A2), U1601.9 (P05), U1601.10 (P06), U1601.11 (P07), U1601.12 (GND), U1601.13 (P10), U1601.21 (A0); also elsewhere on the board
I2C0_SCL: U1601.22 (SCL); also elsewhere on the board
I2C0_SDA: U1601.23 (SDA); also elsewhere on the board
MCU_~IRQ: U1601.1 (~INT); also elsewhere on the board

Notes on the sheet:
Button I/O Expander (optional)
I2C Addr: 0x20

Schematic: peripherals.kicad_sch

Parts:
C1501, C1502, C1503, C1504: 100n; C_0402_1005Metric; LCSC C1525
C1505: 22p; C_0402_1005Metric_Pad0.74x0.62mm_HandSolder; LCSC C1555
D1501: 1N4148W; D_SOD-123; LCSC C81598
J1501: Vibration_Motor; Rumble_Motor_Pads
Q1501: AO3401A; SOT-23; LCSC C15127
Q1502: AO3400A; SOT-23; LCSC C20917
R1501, R1504: 10K; R_0402_1005Metric; LCSC C25744
R1502, R1503: 1K; R_0402_1005Metric; LCSC C11702
U1501: LSM6DS3TR-C; LGA-14_3x2.5mm_P0.5mm_LayoutBorder3x4y; LCSC C967633
U1502: PCF8563T; TSSOP-8_3x3mm_P0.65mm; LCSC C27397
Y1501: 32.768kHz; Crystal_SMD_3215-2Pin_3.2x1.5mm; LCSC C32346

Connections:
+3V3: C1501.1, C1502.2, C1503.2, D1501.1 (K), J1501.1, Q1501.2 (S), U1501.5 (VDDIO), U1501.8 (VDD), U1501.12 (CS); also elsewhere on the board
+3V3_FPGA: R1501.1; also elsewhere on the board
/Peripherals/RTC_INT: U1502.3 (~INT)
/Peripherals/RTC_OSCI: C1505.2, U1502.1 (OSCI), Y1501.1
/Peripherals/RTC_OSCO: U1502.2 (OSCO), Y1501.2
/Peripherals/Vibrate_FET_g: Q1502.1 (G), R1503.2
/Peripherals/Vibrate_N: C1503.1, D1501.2 (A), J1501.2, Q1501.3 (D), Q1502.3 (D)
/Peripherals/~Vibrate_Brake_g: Q1501.1 (G), R1502.2
GND: C1501.2, C1502.1, C1504.1, C1505.1, Q1502.2 (S), R1504.2, U1501.1 (SDO/SA0), U1501.2 (SDX), U1501.3 (SCX), U1501.6 (GND), U1501.7 (GND), U1502.4 (VSS); also elsewhere on the board
I2C0_SCL: U1501.13 (SCL), U1502.6 (SCL); also elsewhere on the board
I2C0_SDA: U1501.14 (SDA), U1502.5 (SDA); also elsewhere on the board
VSYS_ALWAYS: C1504.2, U1502.8 (VDD); also elsewhere on the board
Vibrate_En: R1503.1, R1504.1; also elsewhere on the board
~Vibrate_Brake: R1501.2, R1502.1; also elsewhere on the board

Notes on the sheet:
RTC
C = (XTAL_C - 2pF) * 2 C ~= 22 pF Honestly it's pretty much a guess
I2C Addr: 0x6A
I2C Addr: 0x51
IMU
See NXP UM10301 for oscillator info
Vibration

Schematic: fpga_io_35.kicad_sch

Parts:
C1201, C1202, C1203, C1204: 470n; C_0402_1005Metric; LCSC C47339
C1205, C1206: 4u7; C_0402_1005Metric; LCSC C23733
Q1201: AO3400A; SOT-23; LCSC C20917
R1201, R1202: 330R; R_0402_1005Metric; LCSC C25104
R1203: 10K; R_0402_1005Metric; LCSC C25744
U601: XC7A100T-CSG324; Xilinx_CSG324; LCSC C1521791

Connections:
+3V3_FPGA: C1201.1, C1202.1, C1203.1, C1204.1, C1205.1, C1206.1, U601.A7 (VCCO_35), U601.C3 (VCCO_35), U601.D6 (VCCO_35), U601.F2 (VCCO_35), U601.G5 (VCCO_35), U601.J1 (VCCO_35); also elsewhere on the board
/FPGA IO Bank 35/FPGA_IRQ: Q1201.1 (G), R1203.1, U601.J3 (IO_L22P_T3_35)
/FPGA IO Bank 35/USB_SBU_1: R1201.2, U601.F3 (IO_L13N_T2_MRCC_35)
/FPGA IO Bank 35/USB_SBU_2: R1202.2, U601.D3 (IO_L12N_T1_MRCC_35)
BTN_Down: U601.H5 (IO_L24N_T3_35); also elsewhere on the board
BTN_L: U601.E6 (IO_L5P_T0_AD13P_35); also elsewhere on the board
BTN_Left: U601.G6 (IO_L19P_T3_35); also elsewhere on the board
BTN_Right: U601.F5 (IO_0_35); also elsewhere on the board
BTN_Select: U601.J5 (IO_25_35); also elsewhere on the board
BTN_Up: U601.E5 (IO_L5N_T0_AD13N_35); also elsewhere on the board
DAC_BCLK: U601.G3 (IO_L20N_T3_35); also elsewhere on the board
DAC_DIN: U601.J4 (IO_L21P_T3_DQS_35); also elsewhere on the board
DAC_MCLK: U601.G4 (IO_L20P_T3_35); also elsewhere on the board
DAC_WCLK: U601.H4 (IO_L21N_T3_DQS_35); also elsewhere on the board
FPGA_CLK_50MHz: U601.E3 (IO_L12P_T1_MRCC_35); also elsewhere on the board
FPGA_SPI_CLK: U601.F4 (IO_L13P_T2_MRCC_35); also elsewhere on the board
FPGA_SPI_D0: U601.J2 (IO_L22N_T3_35); also elsewhere on the board
FPGA_SPI_D1: U601.H1 (IO_L17P_T2_35); also elsewhere on the board
FPGA_SPI_D2: U601.H2 (IO_L15P_T2_DQS_35); also elsewhere on the board
FPGA_SPI_D3: U601.K2 (IO_L23P_T3_35); also elsewhere on the board
FPGA_SPI_~CS: U601.K1 (IO_L23N_T3_35); also elsewhere on the board
GB_Cart_AD0: U601.B6 (IO_L2N_T0_AD12N_35); also elsewhere on the board
GB_Cart_AD1: U601.A6 (IO_L3P_T0_DQS_AD5P_35); also elsewhere on the board
GB_Cart_AD2: U601.B7 (IO_L2P_T0_AD12P_35); also elsewhere on the board
GB_Cart_AD3: U601.C4 (IO_L7P_T1_AD6P_35); also elsewhere on the board
GB_Cart_AD4: U601.D4 (IO_L11N_T1_SRCC_35); also elsewhere on the board
GB_Cart_AD5: U601.C5 (IO_L1N_T0_AD4N_35); also elsewhere on the board
GB_Cart_AD6: U601.D5 (IO_L11P_T1_SRCC_35); also elsewhere on the board
GB_Cart_AD7: U601.C6 (IO_L1P_T0_AD4P_35); also elsewhere on the board
GB_Cart_AD8: U601.D8 (IO_L4P_T0_35); also elsewhere on the board
GB_Cart_PHI: U601.B3 (IO_L10P_T1_AD15P_35); also elsewhere on the board
GB_Cart_~CS1: U601.A5 (IO_L3N_T0_DQS_AD5N_35); also elsewhere on the board
GB_Cart_~OE: U601.A3 (IO_L8N_T1_AD14N_35); also elsewhere on the board
GB_Cart_~RD: U601.B4 (IO_L7N_T1_AD6N_35); also elsewhere on the board
GB_Cart_~WR: U601.A4 (IO_L8P_T1_AD14P_35); also elsewhere on the board
GB_Dir_Cart1: U601.D7 (IO_L6N_T0_VREF_35); also elsewhere on the board
GB_Dir_Cart2: U601.C7 (IO_L4N_T0_35); also elsewhere on the board
GB_Dir_Cart3: U601.B2 (IO_L10N_T1_AD15N_35); also elsewhere on the board
GB_Dir_SC: U601.G1 (IO_L17N_T2_35); also elsewhere on the board
GB_Dir_SD: U601.F1 (IO_L18P_T2_35); also elsewhere on the board
GB_Dir_SI: U601.E1 (IO_L18N_T2_35); also elsewhere on the board
GB_Dir_SO: U601.C2 (IO_L16P_T2_35); also elsewhere on the board
GB_Link_SC: U601.G2 (IO_L15N_T2_DQS_35); also elsewhere on the board
GB_Link_SD: U601.E2 (IO_L14P_T2_SRCC_35); also elsewhere on the board
GB_Link_SI: U601.D2 (IO_L14N_T2_SRCC_35); also elsewhere on the board
GB_Link_SO: U601.C1 (IO_L16N_T2_35); also elsewhere on the board
GND: C1201.2, C1202.2, C1203.2, C1204.2, C1205.2, C1206.2, Q1201.2 (S), R1203.2; also elsewhere on the board
MCU_~IRQ: Q1201.3 (D); also elsewhere on the board
USB_SBU1: R1201.1; also elsewhere on the board
USB_SBU2: R1202.1; also elsewhere on the board
Vibrate_En: U601.B1 (IO_L9P_T1_DQS_AD7P_35); also elsewhere on the board
~Vibrate_Brake: U601.A1 (IO_L9N_T1_DQS_AD7N_35); also elsewhere on the board

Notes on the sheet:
Single-ended clock must go to P pin
IRQ

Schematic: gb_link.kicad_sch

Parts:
C1, C3, C4: 100p; C_0402_1005Metric; LCSC C1546
C2004, C2005, C2006, C2007, C2008, C2009, C2010, C2011: 100n; C_0402_1005Metric; LCSC C1525
D2001: H5VU25U; Diodes_UDFN-10_1.0x2.5mm_P0.5mm; LCSC C7420374
J2001: Link_Port; GameBoy_LinkPort_AGB_Horizontal
R2, R3, R4, R5: 330R; R_0402_1005Metric; LCSC C25104
R2005, R2006, R2007: 47K; R_0402_1005Metric; LCSC C25792
R2008: 30K; R_0402_1005Metric; LCSC C25776
U2001, U2002, U2003, U2004: 74LVC1T45; SOT-363_SC-70-6; LCSC C168855

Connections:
+3V3_FPGA: C2005.2, C2007.2, C2009.2, C2011.2, U2001.1 (VCCA), U2002.1 (VCCA), U2003.1 (VCCA), U2004.1 (VCCA); also elsewhere on the board
/Game Boy Interfaces/Game Boy Link/Link_SC: R2008.2, U2004.4 (B); also elsewhere on the board
/Game Boy Interfaces/Game Boy Link/Link_SC_a: D2001.5 (K4), D2001.6 (K4), J2001.5 (SC); also elsewhere on the board
/Game Boy Interfaces/Game Boy Link/Link_SD: R2006.2, U2002.4 (B); also elsewhere on the board
/Game Boy Interfaces/Game Boy Link/Link_SD_a: D2001.4 (K3), D2001.7 (K3), J2001.4 (SD); also elsewhere on the board
/Game Boy Interfaces/Game Boy Link/Link_SI: R2007.2, U2003.4 (B); also elsewhere on the board
/Game Boy Interfaces/Game Boy Link/Link_SI_a: D2001.2 (K2), D2001.9 (K2), J2001.3 (SI); also elsewhere on the board
/Game Boy Interfaces/Game Boy Link/Link_SO: R2005.2, U2001.4 (B); also elsewhere on the board
/Game Boy Interfaces/Game Boy Link/Link_SO_a: D2001.1 (K1), D2001.10 (K1), J2001.2 (SO); also elsewhere on the board
GB_Dir_SC: U2004.5 (DIR); also elsewhere on the board
GB_Dir_SD: U2002.5 (DIR); also elsewhere on the board
GB_Dir_SI: U2003.5 (DIR); also elsewhere on the board
GB_Dir_SO: U2001.5 (DIR); also elsewhere on the board
GB_Link_SC: U2004.3 (A); also elsewhere on the board
GB_Link_SD: U2002.3 (A); also elsewhere on the board
GB_Link_SI: U2003.3 (A); also elsewhere on the board
GB_Link_SO: U2001.3 (A); also elsewhere on the board
GND: C2004.1, C2005.1, C2006.1, C2007.1, C2008.1, C2009.1, C2010.1, C2011.1, D2001.3 (A), D2001.8 (A), J2001.6 (GND), J2001.SH, U2001.2 (GND), U2002.2 (GND), U2003.2 (GND), U2004.2 (GND); also elsewhere on the board
VGB: C2004.2, C2006.2, C2008.2, C2010.2, J2001.1 (VDD), R2005.1, R2006.1, R2007.1, R2008.1, U2001.6 (VCCB), U2002.6 (VCCB), U2003.6 (VCCB), U2004.6 (VCCB); also elsewhere on the board

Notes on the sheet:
For SC: 100K and 47K in parallel = ~32K

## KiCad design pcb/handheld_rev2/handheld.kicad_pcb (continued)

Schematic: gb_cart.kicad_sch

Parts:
C1901, C1902, C1903, C1904, C1905, C1906, C1907, C1908, C1909, C1910, C1911, C1912, C1913: 100n; C_0402_1005Metric; LCSC C1525
J1901: Cartridge_Slot; GameBoy_Cartridge_AGS_1x32-1MP_P1.50mm_Socket_Horizontal
R1901, R1902, R1905: 49R9; R_0402_1005Metric; LCSC C25120
R1903: 100K; R_0402_1005Metric; LCSC C25741
R1904: 27K; R_0603_1608Metric; LCSC C22967
U1901, U1903: 74LVC1T45; SOT-363_SC-70-6; LCSC C168855
U1902, U1904: 74LVCH16T245; TSSOP-48_6.1x12.5mm_P0.5mm; LCSC C352975

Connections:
+3V3_FPGA: C1903.2, C1904.2, C1906.2, C1909.2, C1912.2, C1913.2, R1903.1, U1901.1 (VCCA), U1902.31 (VCCA), U1902.42 (VCCA), U1903.1 (VCCA), U1904.31 (VCCA), U1904.42 (VCCA); also elsewhere on the board
/Game Boy Interfaces/Game Boy Cartridge/Cart_A16: J1901.22 (A16/D0), U1902.12 (1B8)
/Game Boy Interfaces/Game Boy Cartridge/Cart_A17: J1901.23 (A17/D1), U1902.11 (1B7)
/Game Boy Interfaces/Game Boy Cartridge/Cart_A18: J1901.24 (A18/D2), U1902.9 (1B6)
/Game Boy Interfaces/Game Boy Cartridge/Cart_A19: J1901.25 (A19/D3), U1902.8 (1B5)
/Game Boy Interfaces/Game Boy Cartridge/Cart_A20: J1901.26 (A20/D4), U1902.6 (1B4)
/Game Boy Interfaces/Game Boy Cartridge/Cart_A21: J1901.27 (A21/D5), U1902.5 (1B3)
/Game Boy Interfaces/Game Boy Cartridge/Cart_A22: J1901.28 (A22/D6), U1902.3 (1B2)
/Game Boy Interfaces/Game Boy Cartridge/Cart_A23: J1901.29 (A23/D7), U1902.2 (1B1)
/Game Boy Interfaces/Game Boy Cartridge/Cart_AD0: J1901.6 (AD0/A0), U1904.12 (1B8)
/Game Boy Interfaces/Game Boy Cartridge/Cart_AD1: J1901.7 (AD1/A1), U1904.11 (1B7)
/Game Boy Interfaces/Game Boy Cartridge/Cart_AD2: J1901.8 (AD2/A2), U1904.9 (1B6)
/Game Boy Interfaces/Game Boy Cartridge/Cart_AD3: J1901.9 (AD3/A3), U1904.8 (1B5)
/Game Boy Interfaces/Game Boy Cartridge/Cart_AD4: J1901.10 (AD4/A4), U1904.6 (1B4)
/Game Boy Interfaces/Game Boy Cartridge/Cart_AD5: J1901.11 (AD5/A5), U1904.5 (1B3)
/Game Boy Interfaces/Game Boy Cartridge/Cart_AD6: J1901.12 (AD6/A6), U1904.3 (1B2)
/Game Boy Interfaces/Game Boy Cartridge/Cart_AD7: J1901.13 (AD7/A7), U1904.2 (1B1)
/Game Boy Interfaces/Game Boy Cartridge/Cart_AD8: J1901.14 (AD8/A8), U1902.23 (2B8)
/Game Boy Interfaces/Game Boy Cartridge/Cart_AD9: J1901.15 (AD9/A9), U1902.22 (2B7)
/Game Boy Interfaces/Game Boy Cartridge/Cart_AD10: J1901.16 (AD10/A10), U1902.20 (2B6)
/Game Boy Interfaces/Game Boy Cartridge/Cart_AD11: J1901.17 (AD11/A11), U1902.19 (2B5)
/Game Boy Interfaces/Game Boy Cartridge/Cart_AD12: J1901.18 (AD12/A12), U1902.17 (2B4)
/Game Boy Interfaces/Game Boy Cartridge/Cart_AD13: J1901.19 (AD13/A13), U1902.16 (2B3)
/Game Boy Interfaces/Game Boy Cartridge/Cart_AD14: J1901.20 (AD14/A14), U1902.14 (2B2)
/Game Boy Interfaces/Game Boy Cartridge/Cart_AD15: J1901.21 (AD15/A15), U1902.13 (2B1)
/Game Boy Interfaces/Game Boy Cartridge/Cart_PHI: J1901.2 (PHI), U1904.17 (2B4)
/Game Boy Interfaces/Game Boy Cartridge/Cart_VIN: J1901.31 (~REQ/VIN), R1903.2, U1903.4 (B)
/Game Boy Interfaces/Game Boy Cartridge/Cart_~CS1: R1902.1, U1904.13 (2B1)
/Game Boy Interfaces/Game Boy Cartridge/Cart_~CS1_d: J1901.5 (~CS1/~CS), R1902.2
/Game Boy Interfaces/Game Boy Cartridge/Cart_~CS2: R1905.2, U1901.4 (B)
/Game Boy Interfaces/Game Boy Cartridge/Cart_~CS2_d: J1901.30 (~CS2/~RES), R1904.2, R1905.1
/Game Boy Interfaces/Game Boy Cartridge/Cart_~RD: J1901.4 (~RD), U1904.14 (2B2)
/Game Boy Interfaces/Game Boy Cartridge/Cart_~WR: R1901.2, U1904.16 (2B3)
/Game Boy Interfaces/Game Boy Cartridge/Cart_~WR_d: J1901.3 (~WR), R1901.1
GB_Cart_A16: U1902.37 (1A8); also elsewhere on the board
GB_Cart_A17: U1902.38 (1A7); also elsewhere on the board
GB_Cart_A18: U1902.40 (1A6); also elsewhere on the board
GB_Cart_A19: U1902.41 (1A5); also elsewhere on the board
GB_Cart_A20: U1902.43 (1A4); also elsewhere on the board
GB_Cart_A21: U1902.44 (1A3); also elsewhere on the board
GB_Cart_A22: U1902.46 (1A2); also elsewhere on the board
GB_Cart_A23: U1902.47 (1A1); also elsewhere on the board
GB_Cart_AD0: U1904.37 (1A8); also elsewhere on the board
GB_Cart_AD1: U1904.38 (1A7); also elsewhere on the board
GB_Cart_AD2: U1904.40 (1A6); also elsewhere on the board
GB_Cart_AD3: U1904.41 (1A5); also elsewhere on the board
GB_Cart_AD4: U1904.43 (1A4); also elsewhere on the board
GB_Cart_AD5: U1904.44 (1A3); also elsewhere on the board
GB_Cart_AD6: U1904.46 (1A2); also elsewhere on the board
GB_Cart_AD7: U1904.47 (1A1); also elsewhere on the board
GB_Cart_AD8: U1902.26 (2A8); also elsewhere on the board
GB_Cart_AD9: U1902.27 (2A7); also elsewhere on the board
GB_Cart_AD10: U1902.29 (2A6); also elsewhere on the board
GB_Cart_AD11: U1902.30 (2A5); also elsewhere on the board
GB_Cart_AD12: U1902.32 (2A4); also elsewhere on the board
GB_Cart_AD13: U1902.33 (2A3); also elsewhere on the board
GB_Cart_AD14: U1902.35 (2A2); also elsewhere on the board
GB_Cart_AD15: U1902.36 (2A1); also elsewhere on the board
GB_Cart_PHI: U1904.32 (2A4); also elsewhere on the board
GB_Cart_VIN: U1903.3 (A); also elsewhere on the board
GB_Cart_~CS1: U1904.36 (2A1); also elsewhere on the board
GB_Cart_~CS2: U1901.3 (A); also elsewhere on the board
GB_Cart_~OE: U1902.25 (2~OE), U1902.48 (1~OE), U1904.25 (2~OE), U1904.48 (1~OE); also elsewhere on the board
GB_Cart_~RD: U1904.35 (2A2); also elsewhere on the board
GB_Cart_~WR: U1904.33 (2A3); also elsewhere on the board
GB_Dir_Cart0: U1902.1 (1DIR); also elsewhere on the board
GB_Dir_Cart1: U1902.24 (2DIR); also elsewhere on the board
GB_Dir_Cart2: U1904.1 (1DIR); also elsewhere on the board
GB_Dir_Cart3: U1904.24 (2DIR); also elsewhere on the board
GB_Dir_VIN: U1903.5 (DIR); also elsewhere on the board
GB_Dir_~CS2: U1901.5 (DIR); also elsewhere on the board
GND: C1901.1, C1902.1, C1903.1, C1904.1, C1905.1, C1906.1, C1907.1, C1908.1, C1909.1, C1910.1, C1911.1, C1912.1, C1913.1, J1901.32 (GND), J1901.MP, U1901.2 (GND), U1902.4 (GND), U1902.10 (GND), U1902.15 (GND), U1902.21 (GND), U1902.28 (GND), U1902.34 (GND), U1902.39 (GND), U1902.45 (GND), U1903.2 (GND), U1904.4 (GND), U1904.10 (GND), U1904.15 (GND), U1904.19 (2B5), U1904.20 (2B6), U1904.21 (GND), U1904.22 (2B7), U1904.23 (2B8), U1904.26 (2A8), U1904.27 (2A7), U1904.28 (GND), U1904.29 (2A6), U1904.30 (2A5), U1904.34 (GND), U1904.39 (GND), U1904.45 (GND); also elsewhere on the board
VGB: C1901.2, C1902.2, C1905.2, C1907.2, C1908.2, C1910.2, C1911.2, J1901.1 (VDD), R1904.1, U1901.6 (VCCB), U1902.7 (VCCB), U1902.18 (VCCB), U1903.6 (VCCB), U1904.7 (VCCB), U1904.18 (VCCB); also elsewhere on the board

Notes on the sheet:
AGS uses 18K for CS2 pull-up
AGS uses 47Ω for WR/CS1 resistor
AGS uses 15Ω for CS2 limiter

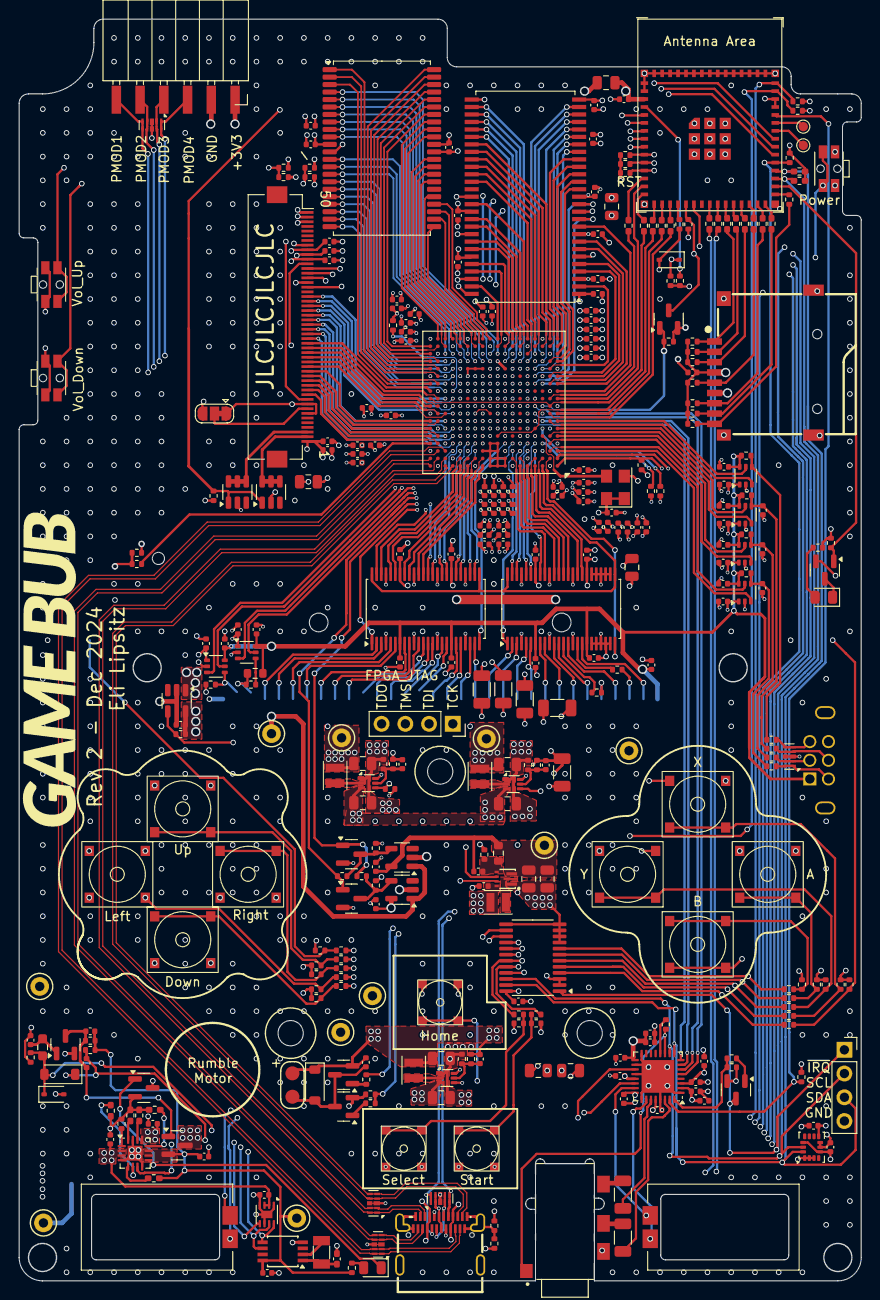
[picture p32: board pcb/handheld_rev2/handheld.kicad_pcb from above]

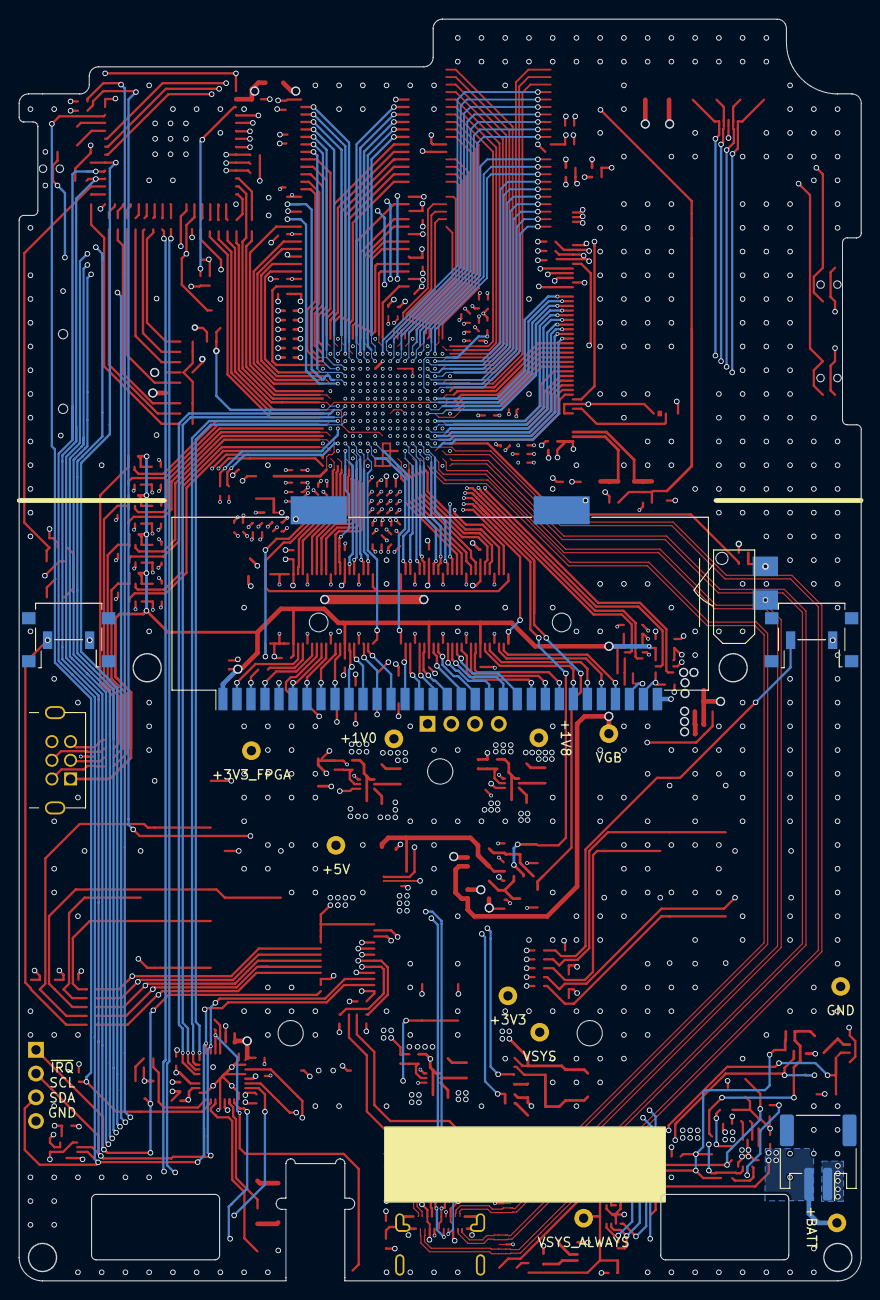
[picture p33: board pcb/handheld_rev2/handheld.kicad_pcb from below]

Board: 6 copper layers, 90.1 x 135.0 mm, 359 parts (6 on the bottom side), 360 nets.

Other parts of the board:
C2001, C2002, C2003: 100p; C_0402_1005Metric
R2001, R2002, R2003, R2004: 330R; R_0402_1005Metric

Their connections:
/Game Boy Interfaces/Game Boy Link/Link_SC: R2004.2; also elsewhere on the board
/Game Boy Interfaces/Game Boy Link/Link_SC_a: R2004.1; also elsewhere on the board
/Game Boy Interfaces/Game Boy Link/Link_SD: C2001.1, R2003.2; also elsewhere on the board
/Game Boy Interfaces/Game Boy Link/Link_SD_a: R2003.1; also elsewhere on the board
/Game Boy Interfaces/Game Boy Link/Link_SI: C2002.1, R2002.2; also elsewhere on the board
/Game Boy Interfaces/Game Boy Link/Link_SI_a: R2002.1; also elsewhere on the board
/Game Boy Interfaces/Game Boy Link/Link_SO: C2003.1, R2001.2; also elsewhere on the board
/Game Boy Interfaces/Game Boy Link/Link_SO_a: R2001.1; also elsewhere on the board
GND: C2001.2, C2002.2, C2003.2; also elsewhere on the board

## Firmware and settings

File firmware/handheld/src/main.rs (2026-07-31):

use anyhow::Context;
use flate2::read::GzDecoder;

use device::Device;

use crate::ui::UI;

mod bitstream;
mod device;
mod kvs;
mod test_hardware;       // 新增：硬件自检模块
pub mod ui;
mod util;
mod worker;

fn main() -> anyhow::Result<()> {
    esp_idf_svc::sys::link_patches();
    esp_idf_svc::log::EspLogger::initialize_default();
    esp_idf_svc::log::set_target_level("gpio", log::LevelFilter::Warn).unwrap();

    kvs::Kvs::init()?;
    log::info!("Device revision {:?}", kvs::keys::DEVICE_REVISION.get());
    log::info!("Serial: {:?}", kvs::keys::DEVICE_SERIAL.get());

    // Check that the firmware is compatible with the listed revision.
    cfg_if::cfg_if! {
        if #[cfg(feature = "rev1")] {
            let required_revision = 1;
        } else if #[cfg(feature = "rev2")] {
            let required_revision = 2;
        } else {
            compile_error!("No board revision selected");
        }
    };
    if kvs::keys::DEVICE_REVISION.get() != Some(required_revision) {
        anyhow::bail!(
            "Incompatible firmware revision: device={:?} firmware={}",
            kvs::keys::DEVICE_REVISION.get(),
            required_revision
        );
    }

    // Proceed to initialize device.
    Device::init()?;
    let mut device = Device::lock();

    // ─── 硬件自检（失败则立即终止，不执行后续操作） ───
    test_hardware::run_tests(&mut device)?;
    // ────────────────────────────────────────────────────

    let is_sdcard_mounted = device.sdcard.is_some();
    device.set_brightness(kvs::keys::BRIGHTNESS.get().unwrap());

    // Setup workers.
    worker::start();

    // Initial programming FPGA
    fn program_fpga(device: &mut Device) -> anyhow::Result<()> {
        let bitstream =
            util::open_system_file("boot.bit.gz").context("Failed to read bitstream")?;
        let mut bitstream = GzDecoder::new(bitstream);
        device
            .fpga
            .program(&mut bitstream)
            .context("Failed to program FPGA")?;
        device.lcd.enable_fpga_control()?;
        Ok(())
    }
    let fpga_program_result = program_fpga(&mut device);

    // Setup UI
    let mut ui = UI::new(&mut device);
    std::mem::drop(device);

    // If there was an error programming the FPGA, show it now.
    if !is_sdcard_mounted {
        show_fatal_error("Error mounting SD card".into());
    } else if let Err(error) = fpga_program_result {
        show_fatal_error_anyhow(error);
    }

    // Run UI in this thread.
    ui.run();
}

fn show_fatal_error_anyhow(error: anyhow::Error) {
    use std::fmt::Write;

    let mut message = format!("{}\n", error);
    for e in error.chain().skip(1) {
        let _ = write!(message, "\n{}", e);
    }
    show_fatal_error(message);
}

fn show_fatal_error(error: String) {
    Device::lock().lcd.enable_mcu_control().unwrap();
    ui::send(ui::Message::FatalError(error));
    ui::send(ui::Message::Redraw);
}

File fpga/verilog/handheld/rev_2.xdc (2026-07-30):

########################################
# Clocking
########################################
# External 50 MHz input clock
set_property -dict { PACKAGE_PIN E3     IOSTANDARD LVCMOS33 } [get_ports { clk_50mhz }];

########################################
# Cartridge Slot
########################################
# Cartridge Bank 0: A16 to A23
set_property -dict { PACKAGE_PIN A11    IOSTANDARD LVCMOS33 } [get_ports { cart_bank0[0] }];
set_property -dict { PACKAGE_PIN B11    IOSTANDARD LVCMOS33 } [get_ports { cart_bank0[1] }];
set_property -dict { PACKAGE_PIN B12    IOSTANDARD LVCMOS33 } [get_ports { cart_bank0[2] }];
set_property -dict { PACKAGE_PIN A13    IOSTANDARD LVCMOS33 } [get_ports { cart_bank0[3] }];
set_property -dict { PACKAGE_PIN B13    IOSTANDARD LVCMOS33 } [get_ports { cart_bank0[4] }];
set_property -dict { PACKAGE_PIN A14    IOSTANDARD LVCMOS33 } [get_ports { cart_bank0[5] }];
set_property -dict { PACKAGE_PIN B14    IOSTANDARD LVCMOS33 } [get_ports { cart_bank0[6] }];
set_property -dict { PACKAGE_PIN J13    IOSTANDARD LVCMOS33 } [get_ports { cart_bank0[7] }];

# Cartridge Bank 1: AD8 to AD15
set_property -dict { PACKAGE_PIN D8     IOSTANDARD LVCMOS33 } [get_ports { cart_bank1[0] }];
set_property -dict { PACKAGE_PIN C12    IOSTANDARD LVCMOS33 } [get_ports { cart_bank1[1] }];
set_property -dict { PACKAGE_PIN D12    IOSTANDARD LVCMOS33 } [get_ports { cart_bank1[2] }];
set_property -dict { PACKAGE_PIN D13    IOSTANDARD LVCMOS33 } [get_ports { cart_bank1[3] }];
set_property -dict { PACKAGE_PIN C14    IOSTANDARD LVCMOS33 } [get_ports { cart_bank1[4] }];
set_property -dict { PACKAGE_PIN D14    IOSTANDARD LVCMOS33 } [get_ports { cart_bank1[5] }];
set_property -dict { PACKAGE_PIN C15    IOSTANDARD LVCMOS33 } [get_ports { cart_bank1[6] }];
set_property -dict { PACKAGE_PIN F13    IOSTANDARD LVCMOS33 } [get_ports { cart_bank1[7] }];

# Cartridge Bank 2: AD0 to AD7
set_property -dict { PACKAGE_PIN B6     IOSTANDARD LVCMOS33 } [get_ports { cart_bank2[0] }];
set_property -dict { PACKAGE_PIN A6     IOSTANDARD LVCMOS33 } [get_ports { cart_bank2[1] }];
set_property -dict { PACKAGE_PIN B7     IOSTANDARD LVCMOS33 } [get_ports { cart_bank2[2] }];
set_property -dict { PACKAGE_PIN C4     IOSTANDARD LVCMOS33 } [get_ports { cart_bank2[3] }];
set_property -dict { PACKAGE_PIN D4     IOSTANDARD LVCMOS33 } [get_ports { cart_bank2[4] }];
set_property -dict { PACKAGE_PIN C5     IOSTANDARD LVCMOS33 } [get_ports { cart_bank2[5] }];
set_property -dict { PACKAGE_PIN D5     IOSTANDARD LVCMOS33 } [get_ports { cart_bank2[6] }];
set_property -dict { PACKAGE_PIN C6     IOSTANDARD LVCMOS33 } [get_ports { cart_bank2[7] }];

# Cartridge Bank 3: 0: nCS1, 1: nRD, 2: nWR, 3: PHI
set_property -dict { PACKAGE_PIN A5     IOSTANDARD LVCMOS33 } [get_ports { cart_bank3[0] }];
set_property -dict { PACKAGE_PIN B4     IOSTANDARD LVCMOS33 } [get_ports { cart_bank3[1] }];
set_property -dict { PACKAGE_PIN A4     IOSTANDARD LVCMOS33 } [get_ports { cart_bank3[2] }];
set_property -dict { PACKAGE_PIN B3     IOSTANDARD LVCMOS33 } [get_ports { cart_bank3[3] }];

# Cartridge individual signals
# Pin 30: nRST (GB) / nCS2 (GBA)
set_property -dict { PACKAGE_PIN J14    IOSTANDARD LVCMOS33 } [get_ports { cart_pin30 }];
set_property -dict { PACKAGE_PIN H14    IOSTANDARD LVCMOS33 } [get_ports { cart_pin30_dir }];

# Pin 31: VIN (GB) / nIRQ (GBA)
set_property -dict { PACKAGE_PIN L13    IOSTANDARD LVCMOS33 } [get_ports { cart_pin31 }];
set_property -dict { PACKAGE_PIN L14    IOSTANDARD LVCMOS33 } [get_ports { cart_pin31_dir }];

# Cartridge bank directions
set_property -dict { PACKAGE_PIN F14    IOSTANDARD LVCMOS33 } [get_ports { cart_bank0_dir }];
set_property -dict { PACKAGE_PIN D7     IOSTANDARD LVCMOS33 } [get_ports { cart_bank1_dir }];
set_property -dict { PACKAGE_PIN C7     IOSTANDARD LVCMOS33 } [get_ports { cart_bank2_dir }];
set_property -dict { PACKAGE_PIN B2     IOSTANDARD LVCMOS33 } [get_ports { cart_bank3_dir }];

# Cartridge configuration
set_property -dict { PACKAGE_PIN D18    IOSTANDARD LVCMOS33 } [get_ports { cart_switch }];
set_property -dict { PACKAGE_PIN G13    IOSTANDARD LVCMOS33 } [get_ports { cart_en_3v3 }];
set_property -dict { PACKAGE_PIN G14    IOSTANDARD LVCMOS33 } [get_ports { cart_en_5v0 }];
set_property -dict { PACKAGE_PIN A3     IOSTANDARD LVCMOS33 } [get_ports { cart_oe_n   }];
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

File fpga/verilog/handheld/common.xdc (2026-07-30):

########################################
# Config
########################################
# Enable bitstream compression
set_property BITSTREAM.GENERAL.COMPRESS True [current_design]

# Tell Vivado the voltages used during configuration
set_property CFGBVS VCCO [current_design]
set_property CONFIG_VOLTAGE 3.3 [current_design]

# Configure framebuffers with "power-optimized" ram-decomposition.
#
# This affects how Vivado elaborates RAMs that are larger than a RAMB36: by default,
# it'll optimize for timing, which means splitting entries across multiple BRAMs.
# This is problematic if the number of rows isn't a power of two, because it'll waste
# a significant amount of space (e.g. a 240x160 framebuffer, with 38,400 15-bit entries,
# will end up using 30 BRAMs (each 1 bit x 32768) (with expansion).
#
# Power optimized decomposition will split rows across BRAMs, so the same framebuffer will
# use 19 BRAMs (each 15-bit x 2048) (depth expansion).
set_property ram_decomp power [get_cells handheld_top/overlayFramebuffer_mem_ext/Memory_reg]
set_property ram_decomp power [get_cells handheld_top/framebuffers_mem_ext/Memory_reg]
set_property ram_decomp power [get_cells handheld_top/framebuffers_mem_*_ext/Memory_reg]

########################################
# Clocking
########################################
# External 50 MHz input clock
create_clock -add -name sys_clk_pin -period 20.00 -waveform {0 10} [get_ports { clk_50mhz }];
set_property CLOCK_DEDICATED_ROUTE FALSE [get_nets clk_in_50mhz]

# The 'dpi' and 'hdmi' clocks pass through a clock mux, and are mutually exclusive.
# Mark their fanouts as being in a physically exclusive clock group.
set_clock_groups -name exclusive_dpi_hdmi -physically_exclusive -group clk_out_dpi_clk_wiz_system -group clk_out_hdmi_clk_wiz_system

# Mark the BUFGMUX_CTRL select input as having a false path.
# From UG472, the select input's setup/hold times only determine whether the old clock is used for an extra cycle
# after changing, which we don't care about.
set_false_path -setup -hold -to bufgmux_av/S0

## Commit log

2026-07-30 Initial commit with all project files
    [DpadButton.stl, ExtButtonArray.stl, FaceButtonArray.stl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]
2026-07-31 Move espflash.toml and partitions.csv to root for CI
    [partitions.csv]

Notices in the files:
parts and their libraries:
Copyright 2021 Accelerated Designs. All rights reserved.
